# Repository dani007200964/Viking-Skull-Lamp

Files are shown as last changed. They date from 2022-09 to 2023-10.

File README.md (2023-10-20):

# Viking Skull Lamp 

## Introduction

I made this project for my brother. He loves Halloween and asked me to create a Viking-style lamp that has a glowing skull.
This is what comes out of this idea. I roughly had five months to test the device before publishing it. I can happily say
that in this period nothing went wrong with it. It just worked like a charm. Also, I have worked a lot on the documentation,
meanwhile. Here you can see what can this thing do.

Tutorial VIdeo (https://www.youtube.com/watch?v=T2uH4yskYew)

## Features:
* 30 addressable LED to make it shine :rotating_light:
* Microphone for :studio_microphone:
  * Music reactive lighting :musical_note:
  * @ref clap_pattern "Clap switch" :clap:
* Foldable controls
* Interactive menu with a graphical display :joystick:
* Saving and loading the configuration parameters :floppy_disk:
* Light modes:
  * Rainbow :rainbow:
  * Candle :candle:
  * Pulse :loud_sound:
  * Komodo 3000 :sunny:
  * Color :art:
* Humidifier for spooky smoke effect :ghost:
* Magic runes on the front. They are glow-in-the-dark :star:

## Documentation

The full documentation with detailed assembly instructions can be found [here](https://dani007200964.github.io/Viking-Skull-Lamp/html/index.html).

## Donation

If you like my work, and if it was useful for you, please consider buying me a coffee or tipping. :coffee: :coffee: :coffee:

<a href='https://ko-fi.com/danielhajnal' target='_blank'>Buy Me a Coffee at ko-fi.com

## Contributing

Pull requests are welcome. For major changes, please open an issue first to discuss what you would like to change.

## Used Resources:

* [FastLED](https://github.com/FastLED/FastLED)
* [PlatformIO](https://platformio.org/)
* [Visual Studio Code](https://code.visualstudio.com/)
* [Atom](https://atom.io/)
* [Doxygen](https://doxygen.nl/manual/tables.html)
* [Doxygen Awesome Theme](https://github.com/jothepro/doxygen-awesome-css)
* [Graphviz](https://graphviz.org/)
* [FreeCAD](https://www.freecadweb.org/)
* [Blender](https://www.blender.org/)
* [Prusa Slicer](https://github.com/prusa3d/PrusaSlicer/releases)
* [Gimp](https://www.gimp.org/)
* [KiCad](https://www.kicad.org/)
* [Interactive HTML BOM](https://github.com/openscopeproject/InteractiveHtmlBom)
* [Inkscape](https://inkscape.org/)
* [OpenShot](https://www.openshot.org/)
* [model-viewer](https://modelviewer.dev/)

## License & Copyright

© Daniel Hajnal

:email: hajnal.daniel96@gmail.com

Software is licensed under the __MIT__ License, and the hardware and the mechanical parts are licensed under the __Creative Commons__ [BY-NC-SA](https://creativecommons.org/licenses/by-nc-sa/4.0/) license.

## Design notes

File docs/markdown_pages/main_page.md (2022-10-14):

@mainpage Viking Skull Lamp

__Introduction__

I made this project for my brother. He loves Halloween and asked me to create a Viking-style lamp that has a glowing skull.
This is what comes out of this idea. I roughly had five months to test the device before publishing it. I can happily say
that in this period nothing went wrong with it. It just worked like a charm. Also, I have worked a lot on the documentation,
meanwhile. Here you can see what can this thing do. Also, there are some nice photos of the lighting in the @ref gallery "gallery".

\htmlonly

<p align="center"><iframe width="1024" height="786" src="https://www.youtube.com/embed/T2uH4yskYew" title="YouTube video player" frameborder="0" allow="accelerometer; autoplay; clipboard-write; encrypted-media; gyroscope; picture-in-picture" allowfullscreen></iframe></iframe></p>

\endhtmlonly

__Features:__
* 30 addressable LED to make it shine \emoji :rotating_light:
* Microphone for \emoji :studio_microphone:
  * Music reactive lighting \emoji :musical_note:
  * @ref clap_pattern "Clap switch" \emoji :clap:
* Foldable controls
* Interactive menu with a graphical display \emoji :joystick:
* Saving and loading the configuration parameters \emoji :floppy_disk:
* Light modes:
  * Rainbow \emoji :rainbow:
  * Candle \emoji :candle:
  * Pulse \emoji :loud_sound:
  * Komodo 3000 \emoji :sunny:
  * Color \emoji :art:
* Humidifier for spooky smoke effect \emoji :ghost:
* Magic runes on the front. They are glow-in-the-dark \emoji :star:

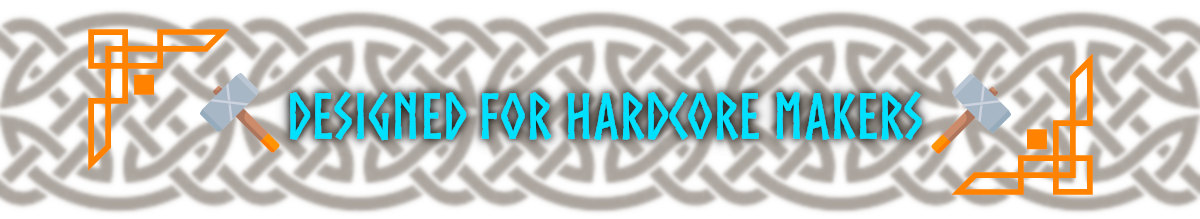
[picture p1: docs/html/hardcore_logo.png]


I want to clarify at the beginning that this is not a beginner-level project. It's more like a hardcore one.
If you love to create stuff and you are brave enough to start this journey, this documentation will guide you
through the whole assembly procedure. Before you start buying the components, please check the
@ref required_tools "required tools" page. It contains everything you need to create this device. If you don't
have a tool, it will be clear at the beginning.

I tried to not make mistakes in the device or its documentation, but I'm just a regular person, sometimes
I make mistakes like everyone else do. If you find a problem or something does not understandable, please visit
the @ref issue_guide "issue guide" section. There is an example of how to submit an issue. If you report an issue
I will try my best to fix it.

This journey consists of five stages. You have to start from the first and progress upwards.

1. \ref components "Sourcing Components:" Firstly you have to source the required parts and materials.

2. \ref print_guide "3D Printing Parts:" Next, you have to print all the necessary parts. There are some tricky ones
so read the \ref print_guide "print guide" section carefully.

3. \ref pcb_assembly "PCB And Cable Assembly:" I have designed a custom PCB for this project. It expands the functionality of
the Arduino UNO platform. It controls all the peripherals in the system. The custom PCB was necessary to make the project
fit this size.

4. \ref software_guide "Software Guide:" Of course, this project has a custom firmware. It is written in C++ and I
have used PlatformIO as a development tool.

5. \ref assembly_instructions "Mechanical Assembly:" Finally it's time to assemble the whole thing.

__Donation__

If you like my work, and if it was useful for you, please consider buying me a coffee or tipping. \emoji :coffee: \emoji :coffee: \emoji :coffee:



__Contributing__

Pull requests are welcome. For major changes, please open an issue first to discuss what you would like to change.

__Used Resources:__

* [FastLED](https://github.com/FastLED/FastLED)
* [PlatformIO](https://platformio.org/)
* [Visual Studio Code](https://code.visualstudio.com/)
* [Atom](https://atom.io/)
* [Doxygen](https://doxygen.nl/manual/tables.html)
* [Doxygen Awesome Theme](https://github.com/jothepro/doxygen-awesome-css)
* [Graphviz](https://graphviz.org/)
* [FreeCAD](https://www.freecadweb.org/)
* [Blender](https://www.blender.org/)
* [Prusa Slicer](https://github.com/prusa3d/PrusaSlicer/releases)
* [Gimp](https://www.gimp.org/)
* [KiCad](https://www.kicad.org/)
* [Interactive HTML BOM](https://github.com/openscopeproject/InteractiveHtmlBom)
* [Inkscape](https://inkscape.org/)
* [OpenShot](https://www.openshot.org/)
* [model-viewer](https://modelviewer.dev/)

__License & Copyright__

© Daniel Hajnal

\emoji :email: hajnal.daniel96@gmail.com

Software is licensed under the __MIT__ License, and the hardware and the mechanical parts are licensed under the __Creative Commons__ [BY-NC-SA](https://creativecommons.org/licenses/by-nc-sa/4.0/) license.

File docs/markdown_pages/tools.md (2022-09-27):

@page required_tools Required Tools

@section essential_tools Essential Tools

These tools are required to create this project. Without them, it is almost impossible
to finish every section. Also if you are a maker these tools can be used later for
future projects.

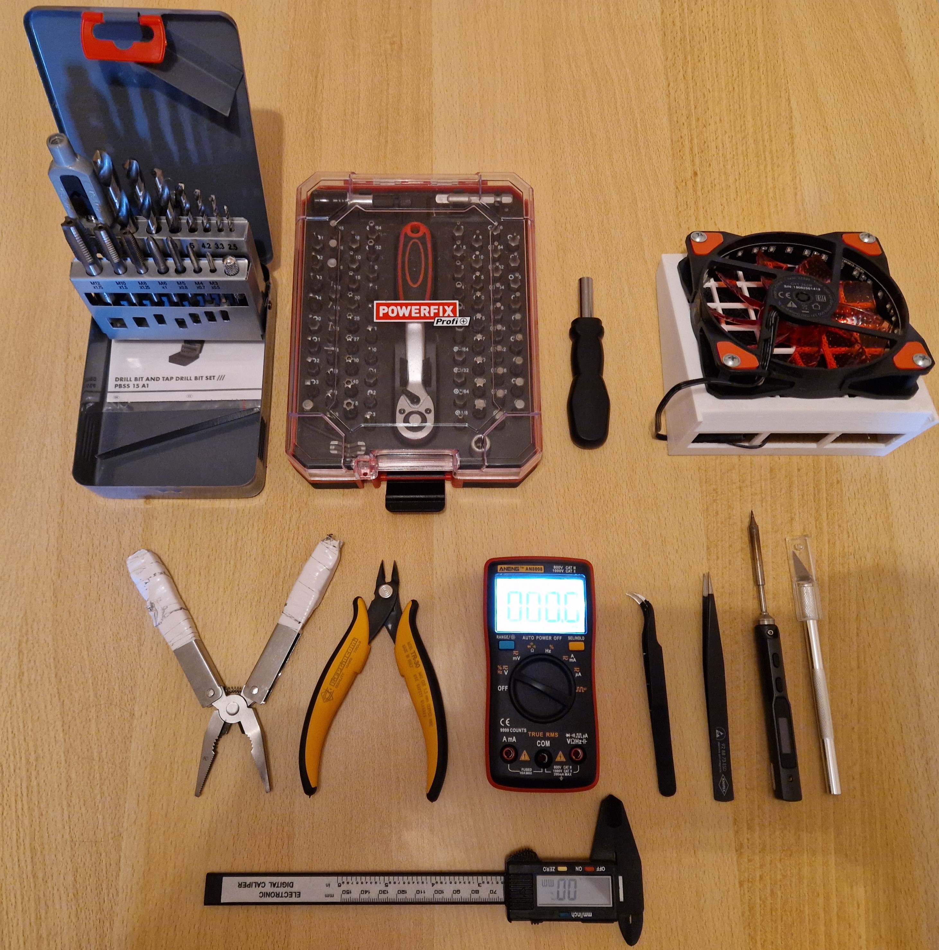
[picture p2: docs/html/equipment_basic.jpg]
Essential Tools


* Screwdriver with a lot of bitheads
* Superglue
* Side cutter
* Multimeter
* Tweezers
* Soldering iron
* Fume extractor
* Exacto knife
* Tapping set
* Caliper
* Pliers
* Connector crimping pliers( [PA-09](https://www.engineertools-jp.com/pa092021) for example )
* 3D printer with 180mm * 180mm * 150mm volume at least. I have a Prusa Mini, but
I think any popular 3D printer can make these parts. For the nozzle, I used a 0.4mm one and it
was enough for all parts.

@note If you do some soldering work PLEASE USE A FUME EXTRACTOR. That smoke is very
dangerous, it can kill you. Please solder in a well-ventilated area with some kind
of fume extractor. You can build one with some carbon filter and a PC fan.

@section tools_for_warriors Tools For Warriors

In this section, I show some tools, that I used in this project. These are not necessary
to finish the project, but they can accelerate the process and the result will be
more professional.

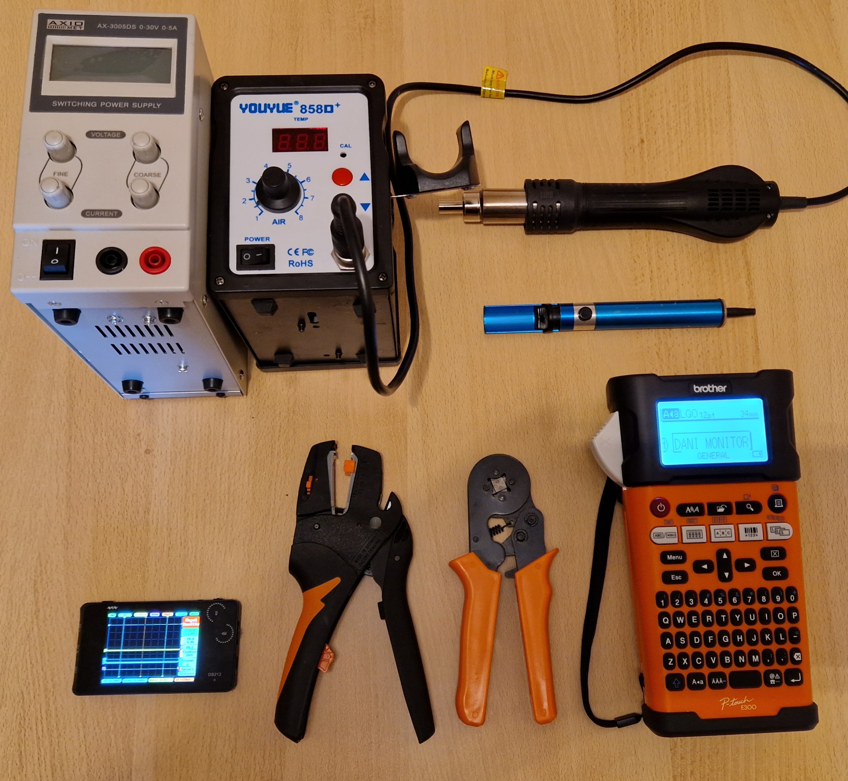
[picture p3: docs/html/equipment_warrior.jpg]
Warrior's Tools


* Bench supply - If you want to power up prototype electronics it can be a lifesaver.
You can limit the current to a safe level, this way if something's wrong with the
circuit, it won't blow to your face at the smoke test.
* Hot air station - If you do some SMD rework it is a game changer. Also, it can be
used for heat-shrinking tubes.
* Label maker - One of my favorite gadgets. If you want to organize something it is
the right tool. I use it whenever I have more cable than one.
* Stripping tool - This thing is awesome when you have to deal with cables. It is
not cheap, but you can strip cable ends like a God with it. Also, your hand won't
hurt after a day.
* End sleeve crimper - If you have to deal with terminal blocks, this thing is very useful.
You can press the end sleeves with regular pliers, but it's hard to fit in the terminal block
that way. There are cheap solutions, I highly recommend getting one.
* Solder sucker - It can be useful with THT components.
* Oscilloscope - There are a huge variety of scopes today. There are cheap ones like
the [DS212](https://www.miniware.com.cn/product/ds212-mini-oscilloscope-digital-oscilloscope/).
It is cheap and does the job for basic circuits. Sadly the interface is hard to use.

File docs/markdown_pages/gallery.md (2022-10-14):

@page gallery Gallery

\htmlonly

<div class="row">   
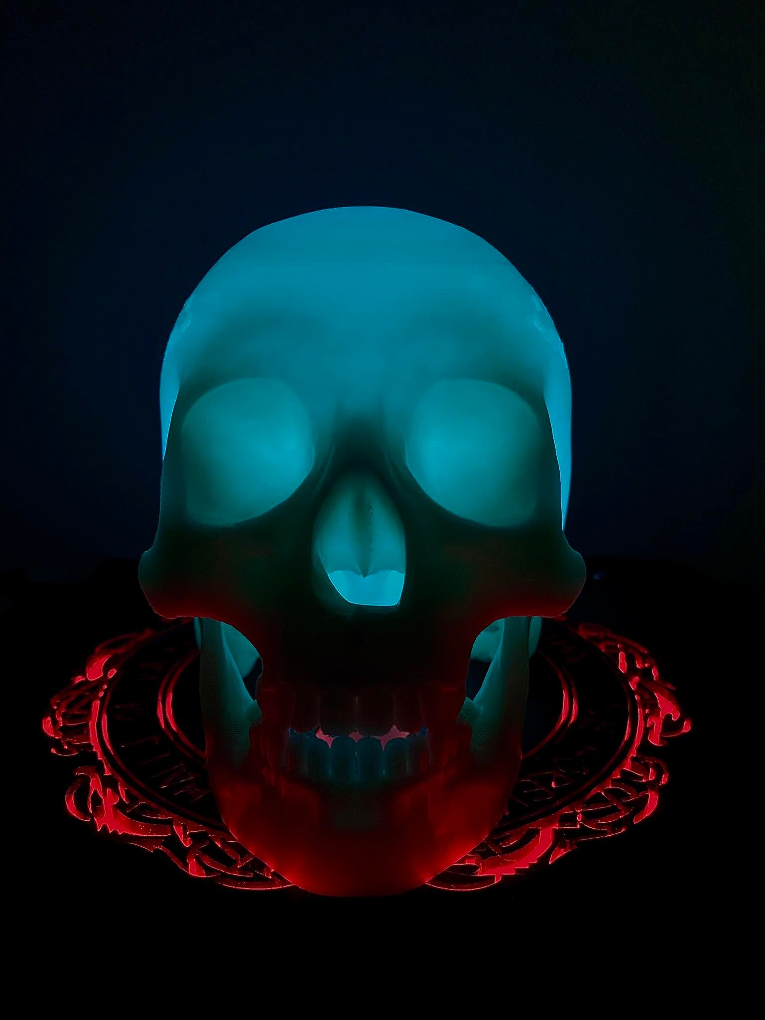
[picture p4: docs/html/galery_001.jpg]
Concrete factory
     
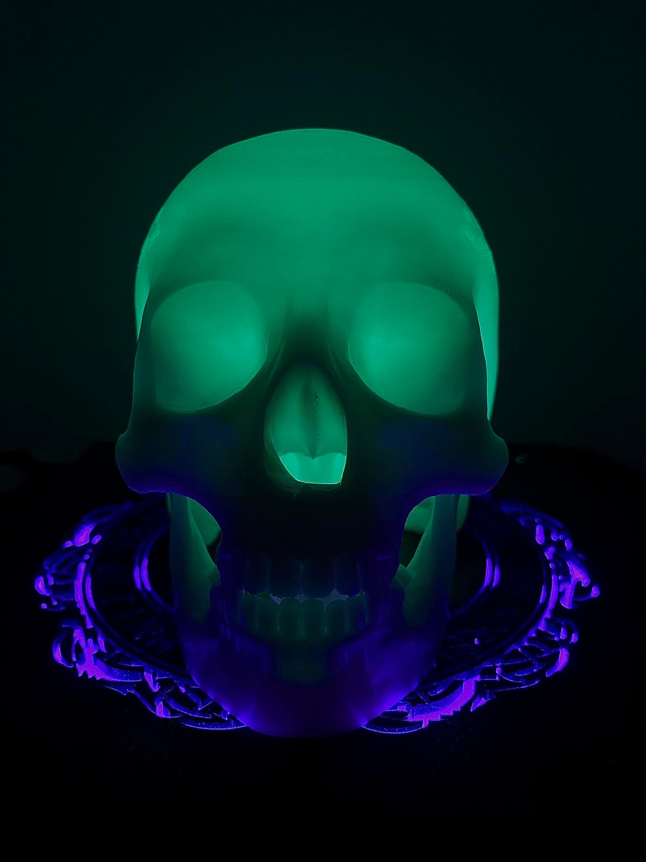
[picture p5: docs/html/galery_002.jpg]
     
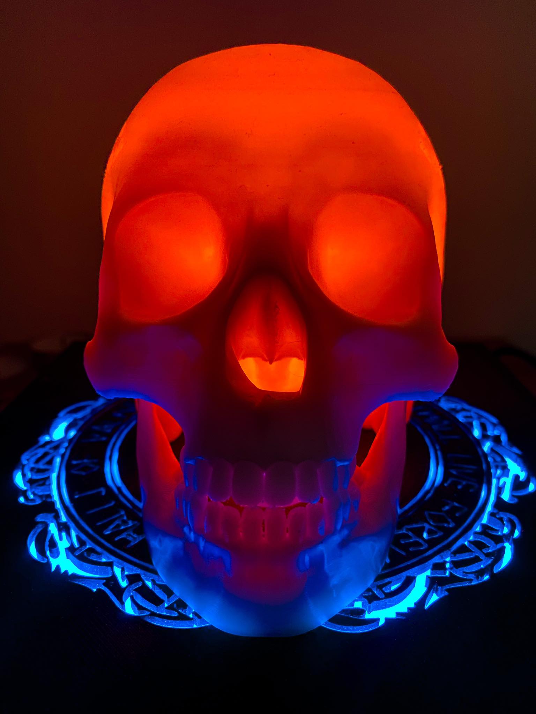
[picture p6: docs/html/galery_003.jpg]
     
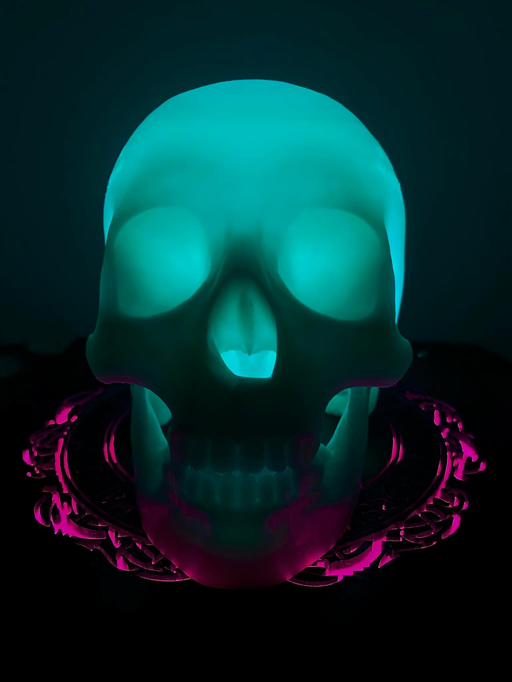
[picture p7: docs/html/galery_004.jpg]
     
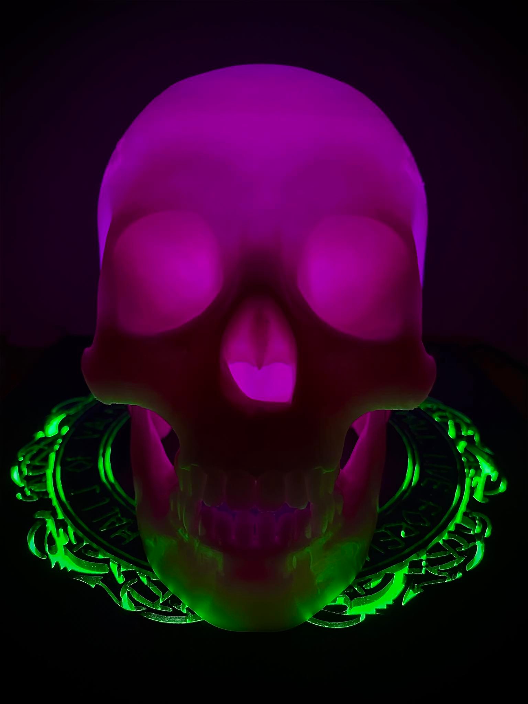
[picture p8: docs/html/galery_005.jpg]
     
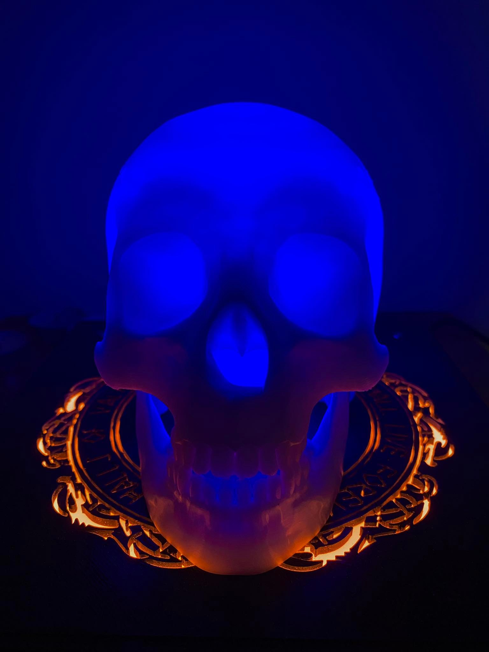
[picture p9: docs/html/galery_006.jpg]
     
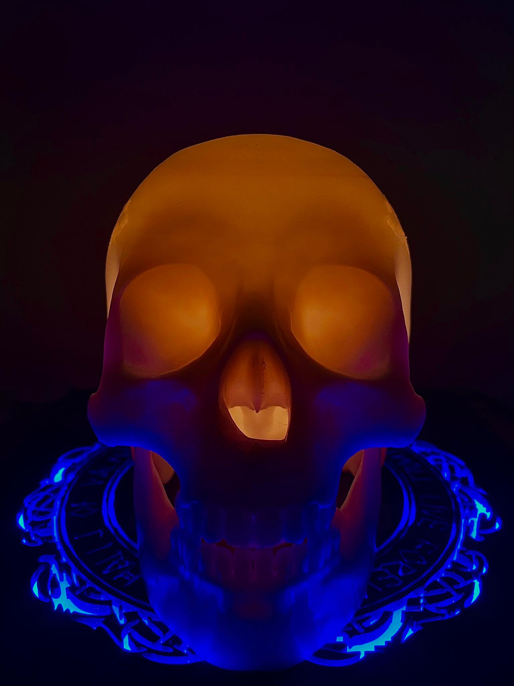
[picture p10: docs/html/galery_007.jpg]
     
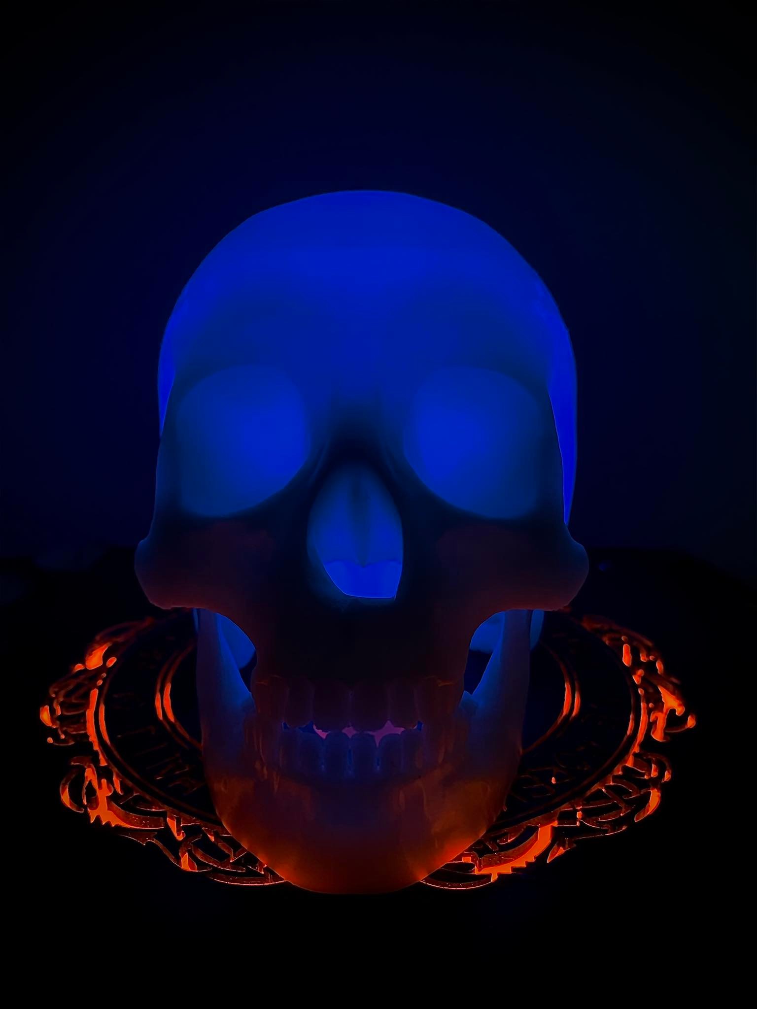
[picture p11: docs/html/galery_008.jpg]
     
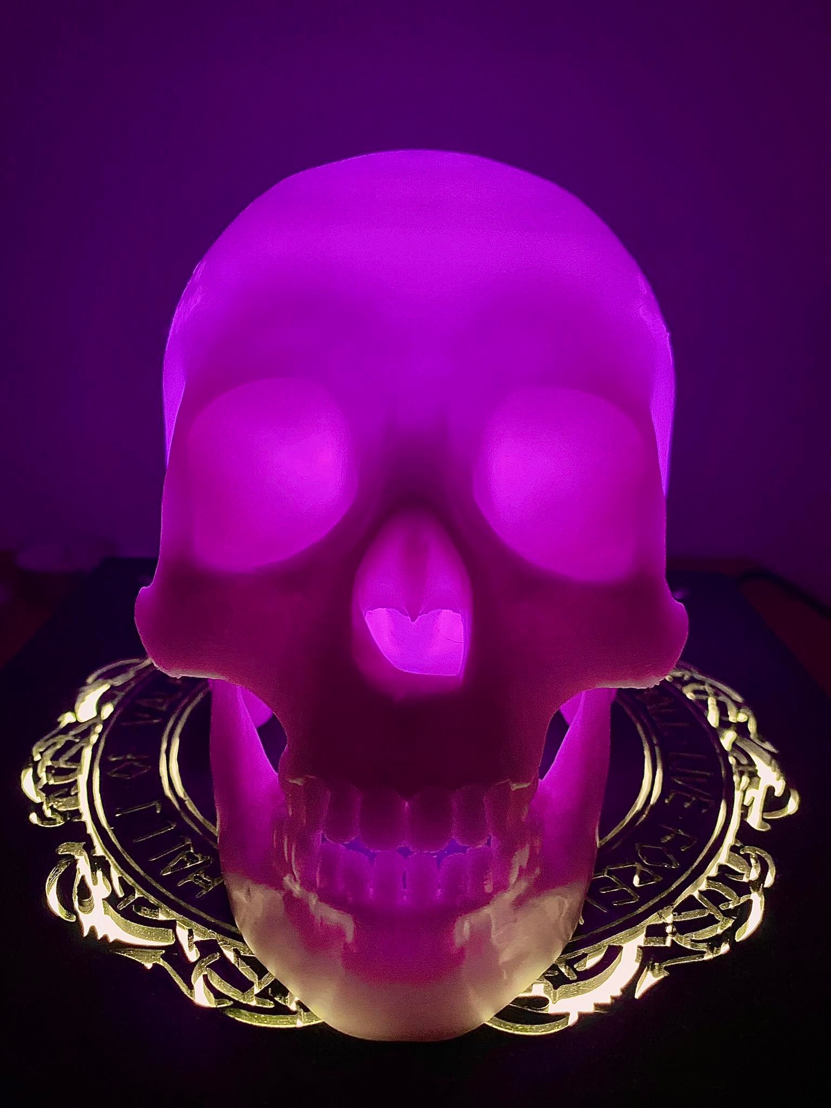
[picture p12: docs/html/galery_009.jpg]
     
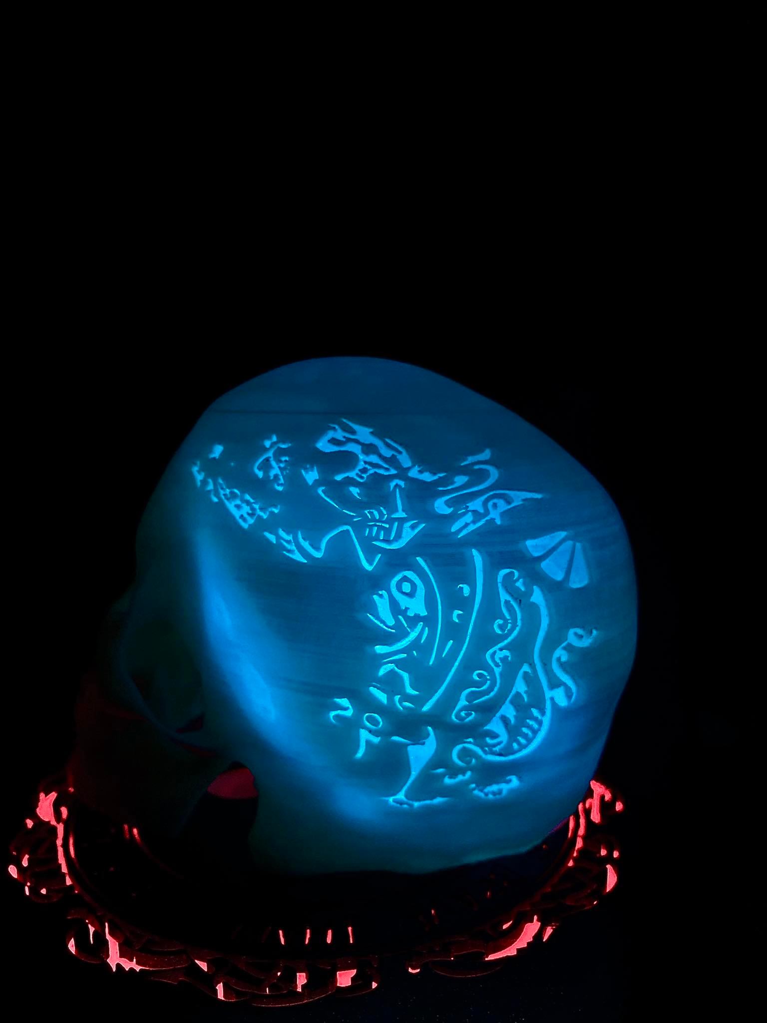
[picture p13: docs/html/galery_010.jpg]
     
     Abstract factory
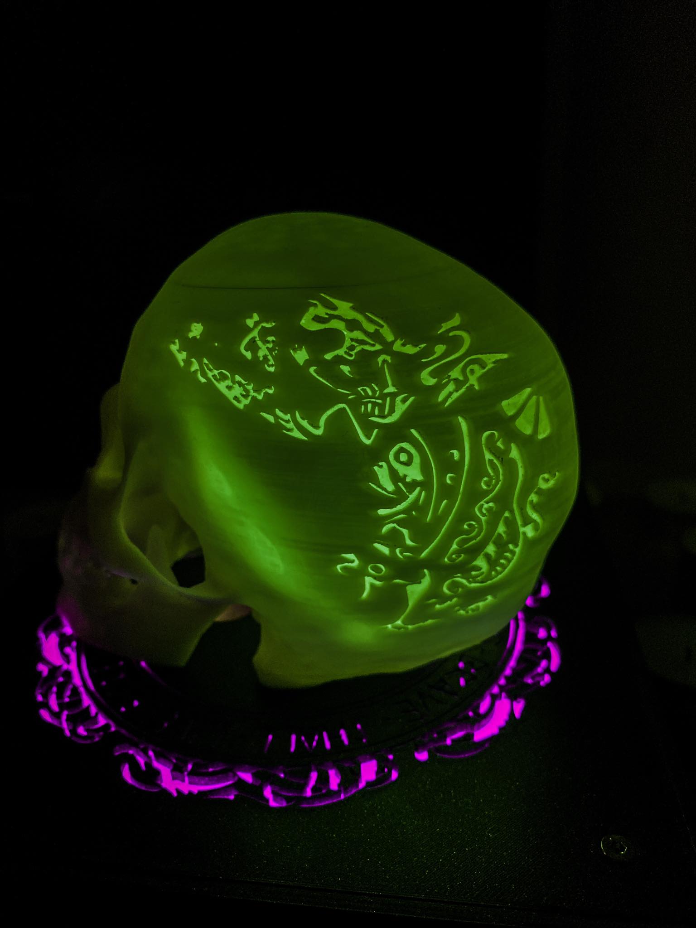
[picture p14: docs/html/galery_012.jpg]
     
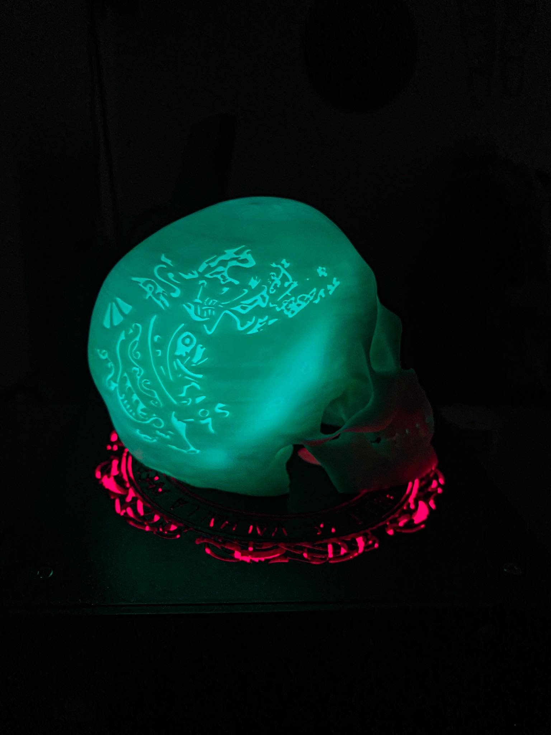
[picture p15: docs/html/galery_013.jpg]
     
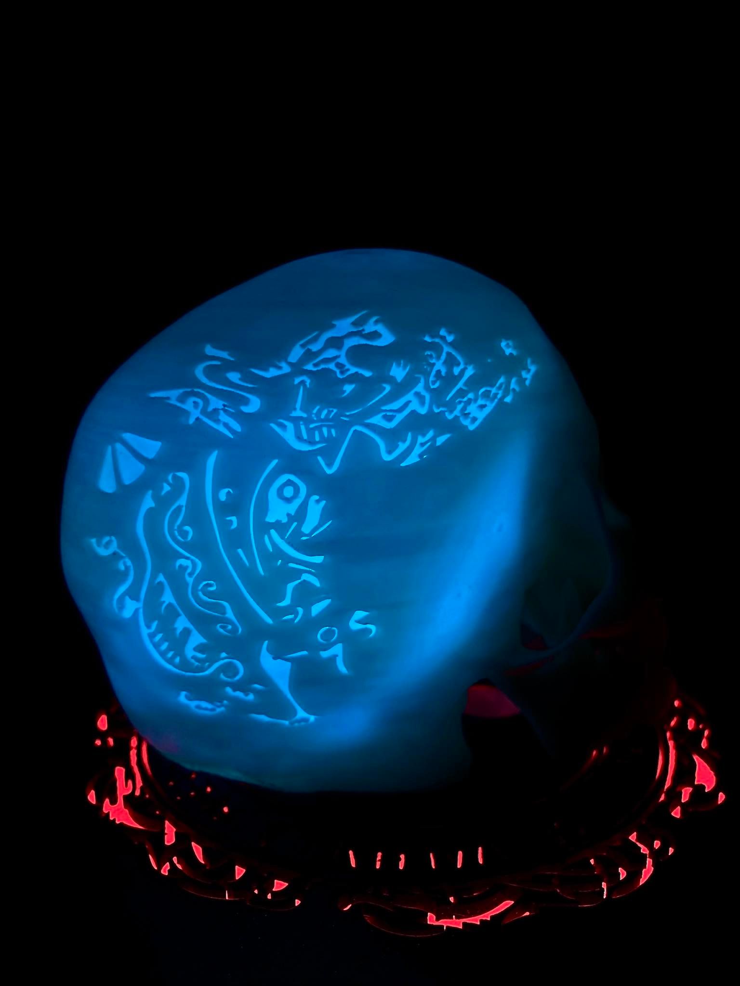
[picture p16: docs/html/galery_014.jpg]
     
</div>

\endhtmlonly

@section clap_pattern Clap Pattern

\htmlonly

<video controls>
  <source src="clap_pattern.mp4">
</video>

\endhtmlonly

@note This clap pattern is supported by the software. It sometimes works \emoji :grimacing:

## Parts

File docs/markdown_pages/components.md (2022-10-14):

@page components Components

\htmlonly

<iframe src="https://docs.google.com/spreadsheets/d/e/2PACX-1vSf02YC8l392_BotfjYF4mUZivv1Xb5yQWE1lsLWvxXTTtfUl-AnEIT_xKbkZg5Pfvl0sSlF0SmhizU/pubhtml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" style="width:100%;height:80vh;"></iframe>

\endhtmlonly

This table shows all the required components to build this project. I tried to use generic
parts to make the sourcing easier. I included the distributors which I used. I calculated
the nominal quantity for everything, but I also included the quantity, that I recommend
to source. It is always a good thing if you have some spare parts, you can use them later.
It is very frustrating when something has less in stock than needed. Also sometimes you
stumble upon a bad module( encoder, display... ) that doesn't work. Personally, I had only
one incident with a cheap display module in the years, but you get the idea.

__Techno Viking PCB Parts__

This is a special topic. Because the PCB has a relatively high amount of components, I think
it's better to handle that separately. Luckily the PCB designer software that I used can create
an interactive HTML-based component list, I included that in the
@ref how_to_get_the_right_components "How To Get PCB Components" section. It can be used for
PCB assembly as well.

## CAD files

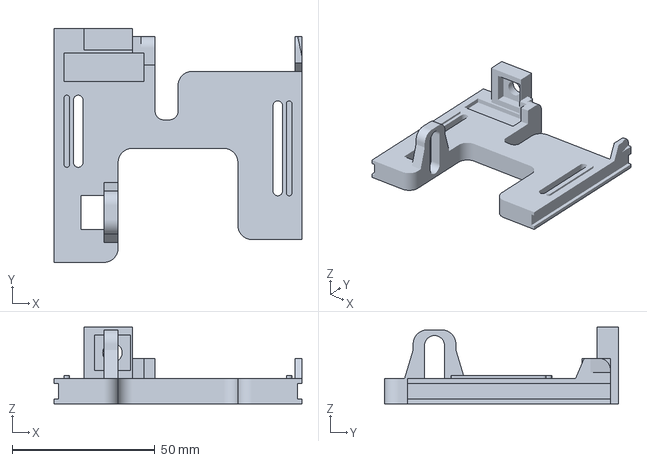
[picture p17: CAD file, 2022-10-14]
CAD/3mf/moving_platform_1pcs.3mf
87.0 x 82.0 x 27.0 mm

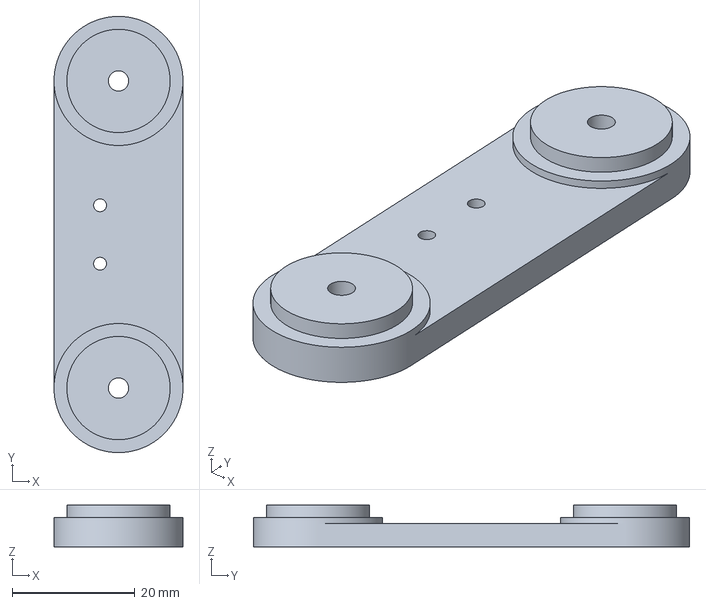
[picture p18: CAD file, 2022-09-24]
CAD/3mf/left_endstop_mount_1pcs.3mf
21.0 x 71.0 x 6.80 mm

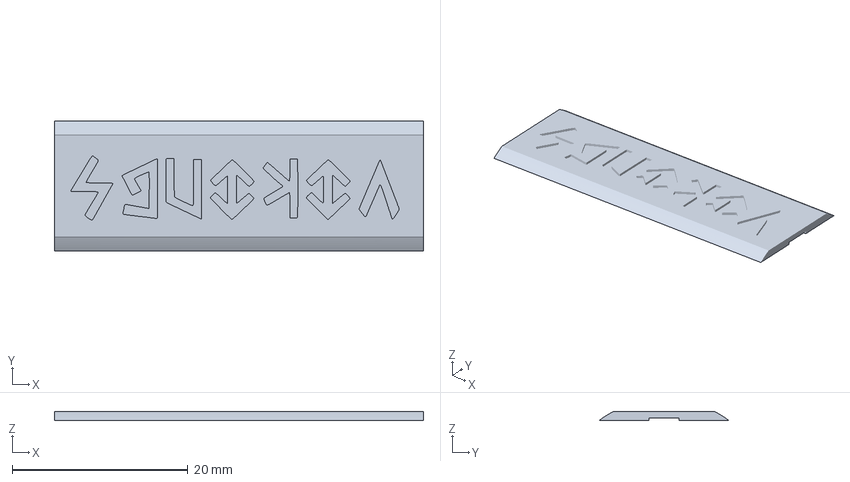
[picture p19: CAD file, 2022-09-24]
docs/html/display_holder_front_with_art_1pcs.3mf
42.0 x 14.8 x 1.00 mm

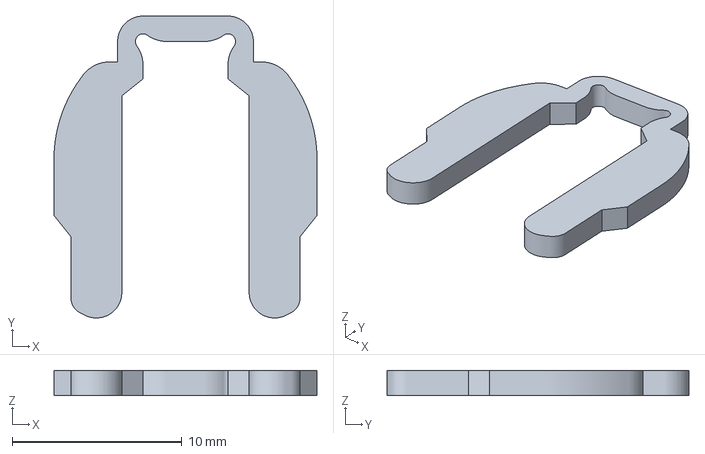
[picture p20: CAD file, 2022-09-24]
docs/html/display_clamp_2pcs.3mf
15.5 x 17.8 x 1.50 mm

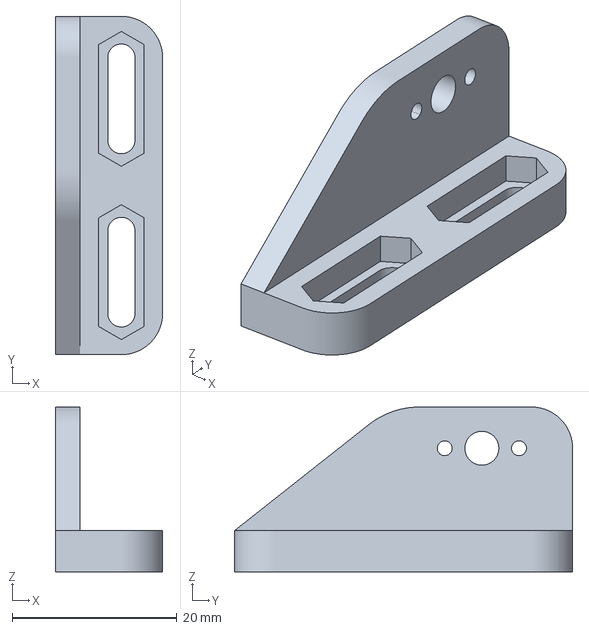
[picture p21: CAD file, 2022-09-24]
CAD/3mf/motor_mount_1pcs.3mf
13.0 x 41.0 x 20.0 mm

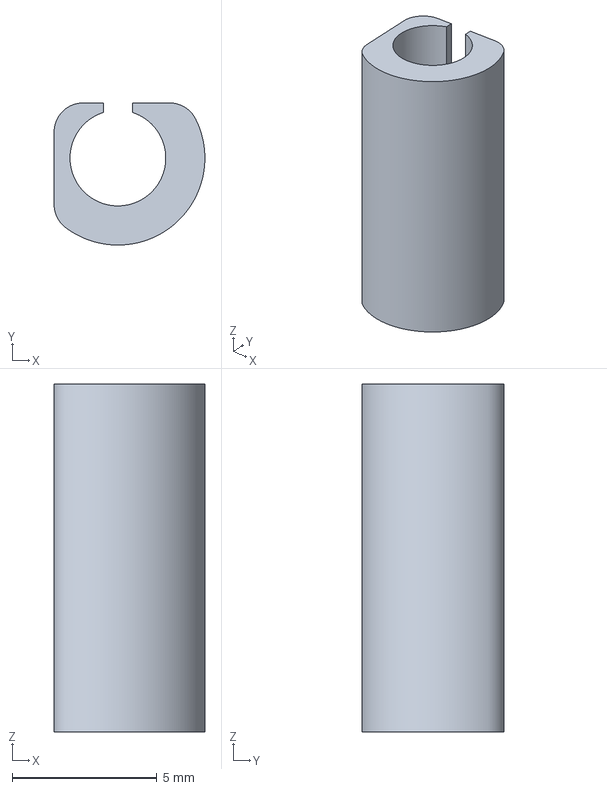
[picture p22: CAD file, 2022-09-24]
docs/html/pcb_spacer_corner_1pcs.3mf
5.20 x 4.90 x 12.0 mm

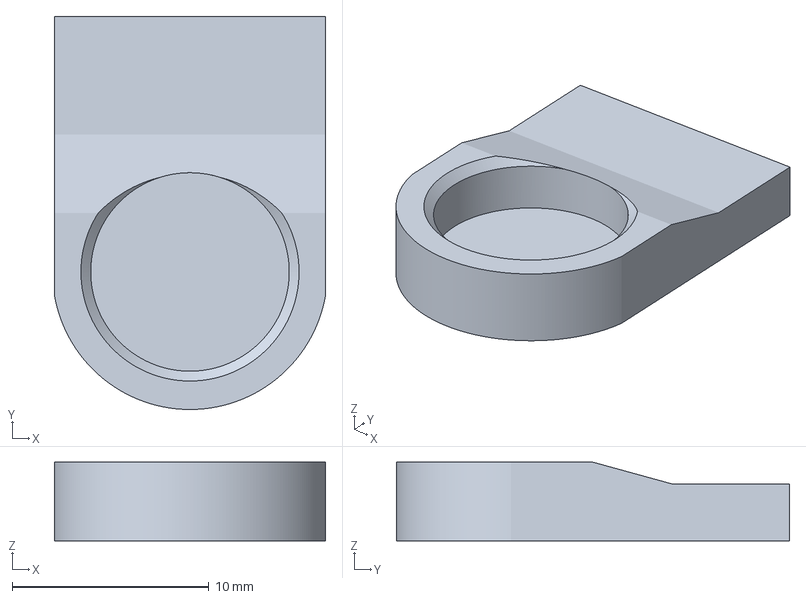
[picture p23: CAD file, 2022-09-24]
CAD/3mf/front_panel_magnet_holder_1pcs.3mf
13.8 x 20.0 x 4.00 mm

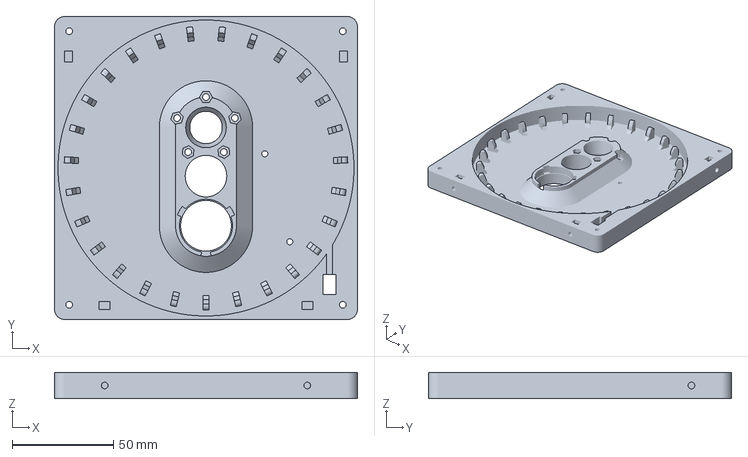
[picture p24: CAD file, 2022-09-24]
docs/html/led_holder_1pcs.3mf
149.5 x 149.5 x 13.0 mm

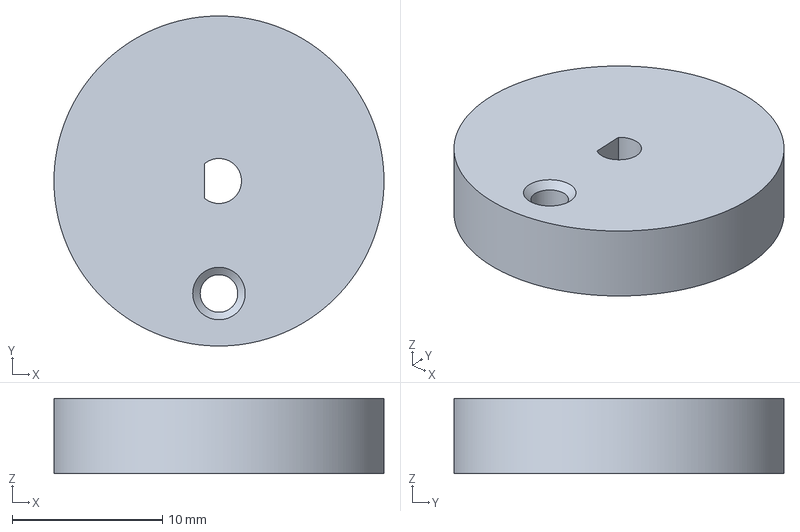
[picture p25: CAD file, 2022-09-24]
CAD/3mf/eccetric_shaft_1pcs.3mf
22.0 x 22.0 x 5.00 mm

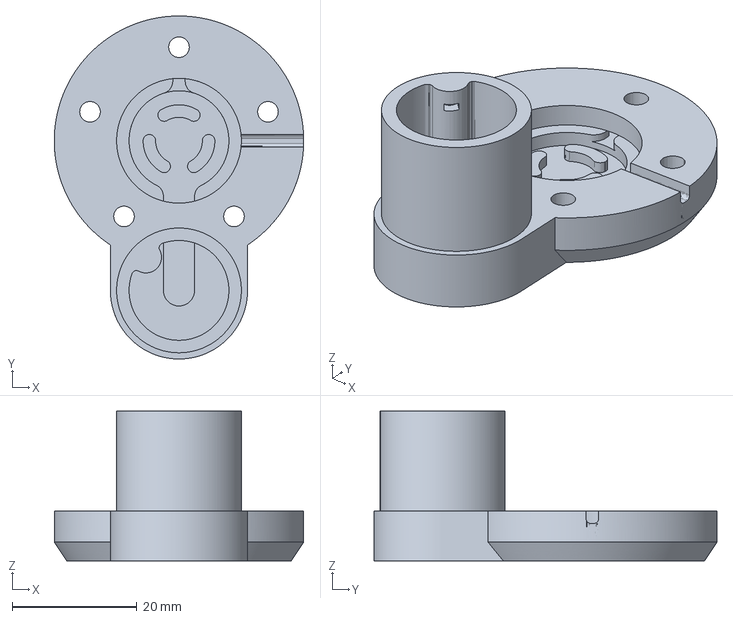
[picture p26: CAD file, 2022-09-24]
docs/html/azomizer_socket_1pcs_PETG.3mf
40.0 x 55.0 x 24.0 mm

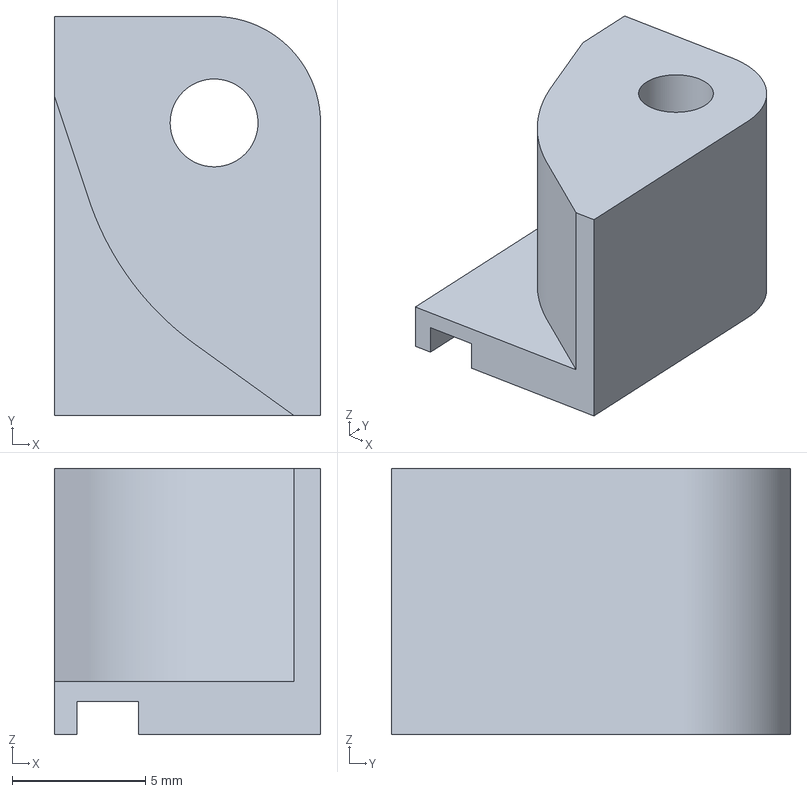
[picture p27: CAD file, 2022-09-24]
CAD/3mf/endstop_knob_2pcs.3mf
10.0 x 15.0 x 10.0 mm

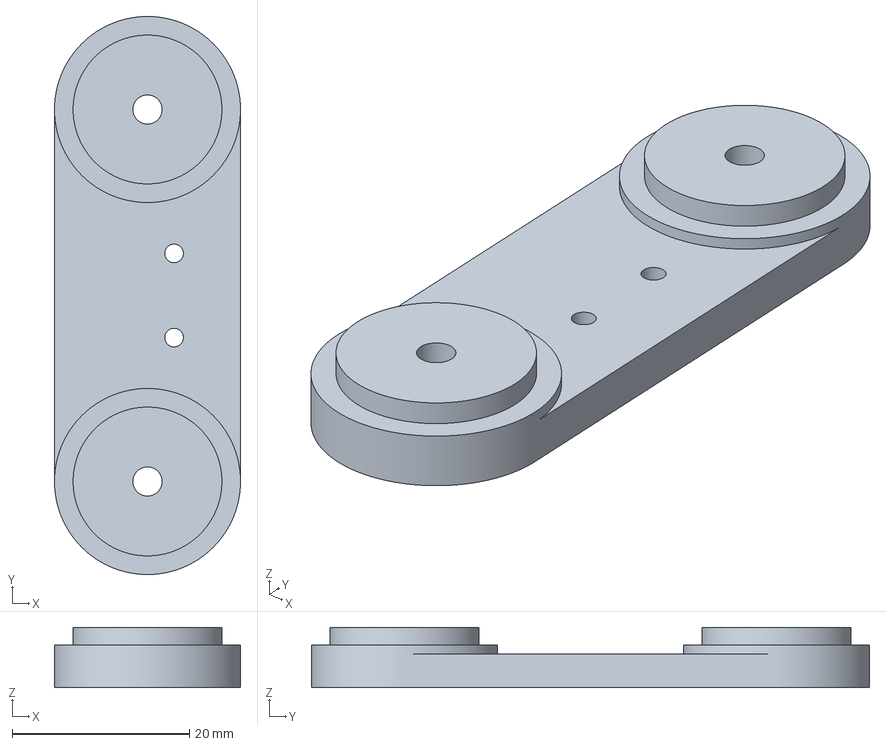
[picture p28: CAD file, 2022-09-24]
docs/html/right_endstop_mount_1pcs.3mf
21.0 x 63.0 x 6.80 mm

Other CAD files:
CAD/3mf/box_front_with_art_1pcs.3mf
CAD/3mf/display_holder_base_with_art_1pcs.3mf
CAD/3mf/encoder_knob_with_art_1pcs.3mf
CAD/3mf/led_ring_mount_1pcs.3mf
CAD/3mf/long_screw_spacer_1pcs.3mf
CAD/3mf/short_screw_spacer_1pcs.3mf
docs/html/box_front_naked_1pcs.stl
docs/html/box_front_with_art_1pcs.3mf
docs/html/display_clamp_2pcs.stl
docs/html/display_holder_base_with_art_1pcs.3mf
docs/html/display_holder_base_with_art_1pcs.stl
docs/html/display_holder_front_with_art_1pcs.stl
docs/html/display_holder_naked_1pcs.stl
docs/html/eccetric_shaft_1pcs.stl
docs/html/encoder_knob_naked_1pcs.stl
docs/html/encoder_knob_with_art_1pcs.3mf
docs/html/encoder_knob_with_art_1pcs.stl
docs/html/endstop_knob_2pcs.stl
docs/html/front_panel_magnet_holder_1pcs.stl
docs/html/led_ring_mount_1pcs.3mf
docs/html/led_ring_mount_1pcs.stl
docs/html/left_endstop_mount_1pcs.stl
docs/html/long_screw_spacer_1pcs.3mf
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

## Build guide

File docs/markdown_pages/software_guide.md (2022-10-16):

@page software_guide Software Guide



@section environment Environment

In this project, I used [Visual Studio Code](https://code.visualstudio.com/). It is an
open-source, multi-platform text editor, which has a lot of useful plugins. One of
those plugins is [PlatformIO](https://platformio.org/), which is a complete build system
for embedded devices. It is very easy to use and works very well.

__To make it work:__

__1.__ Download and install \emoji :package: [Visual Studio Code](https://code.visualstudio.com/)

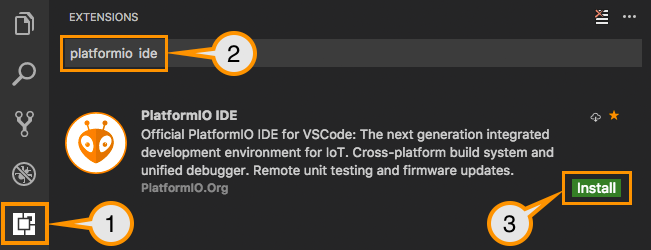
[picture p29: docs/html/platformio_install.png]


__2.__ Open VS Code and install the PlatformIO extension.

__3.__ Download the latest [release](https://github.com/dani007200964/Viking-Skull-Lamp/releases)
from the Viking Skull Lamp repository and unpack it somewhere on your machine.

__4.__ Open VS Code and follow the steps below.

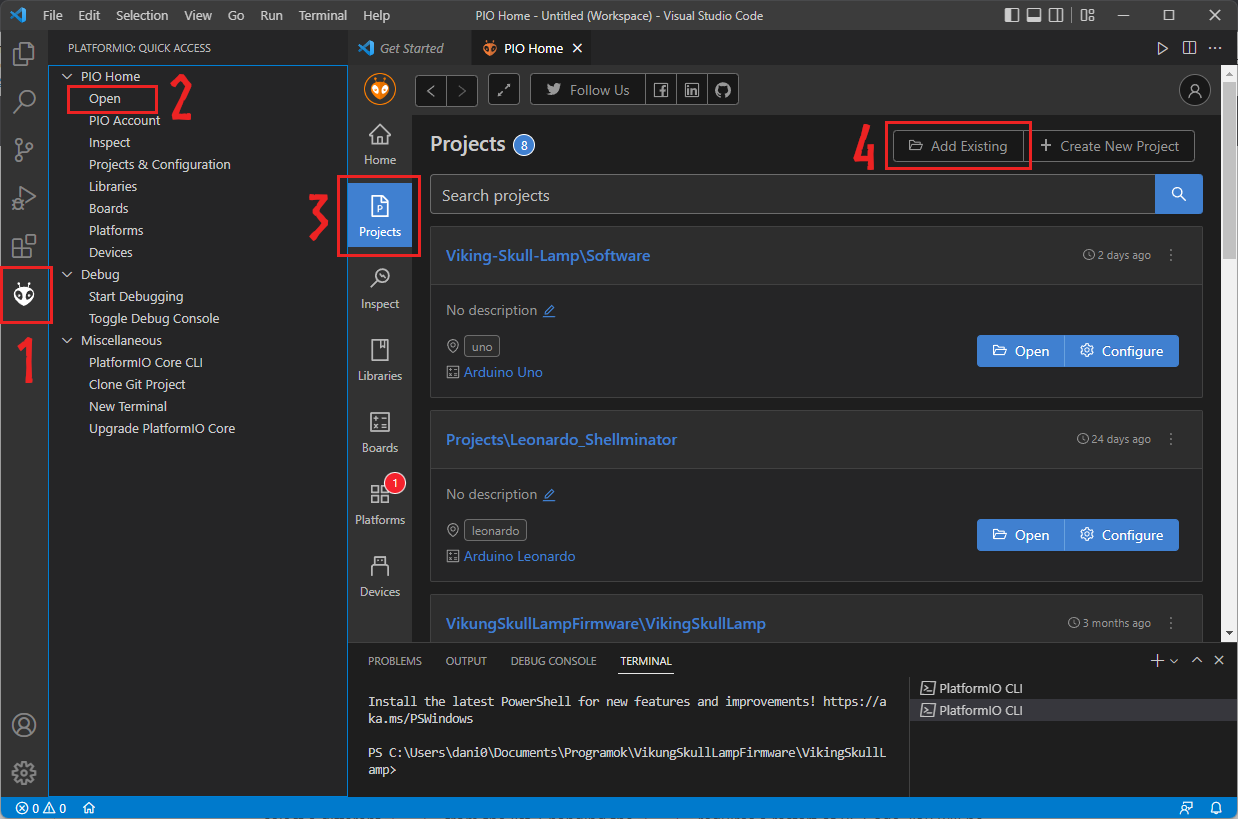
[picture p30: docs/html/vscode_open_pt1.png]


__5.__ Locate and open the __Software__ folder in the downloaded project folder.

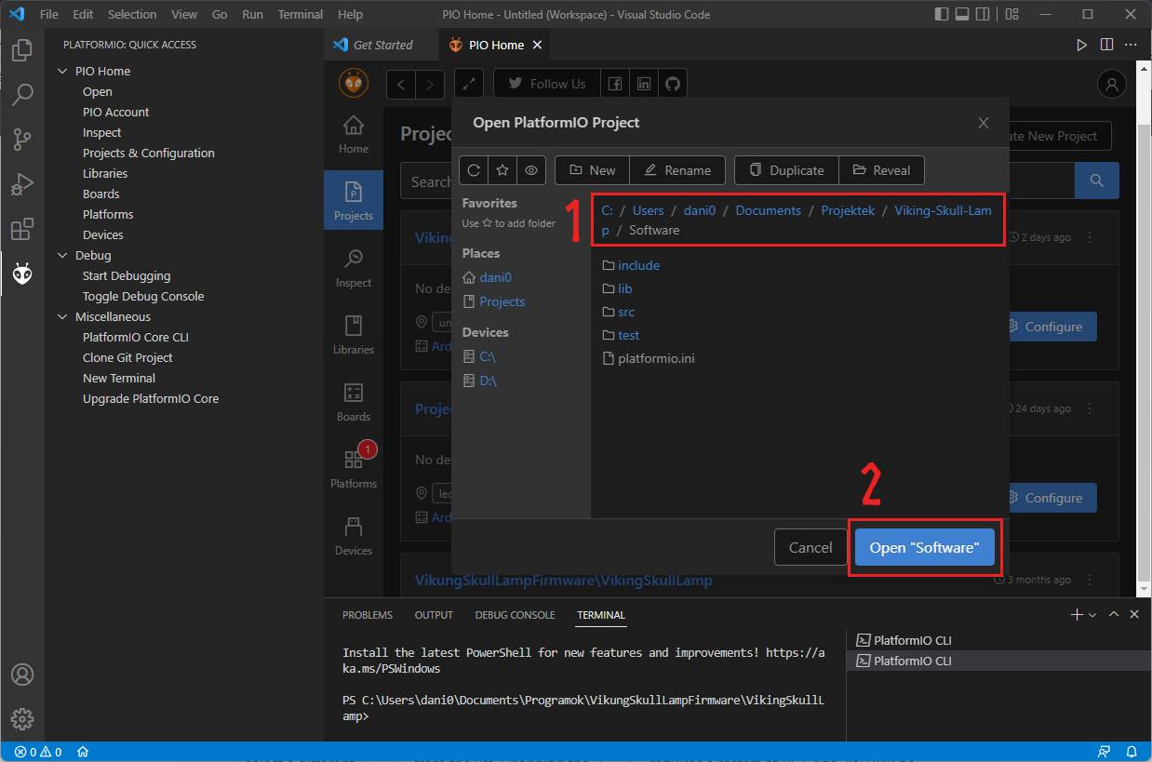
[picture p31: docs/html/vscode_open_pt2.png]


If everything went well, that's all, you can build and upload the firmware.

@section build_the_firmware Build The Firmware

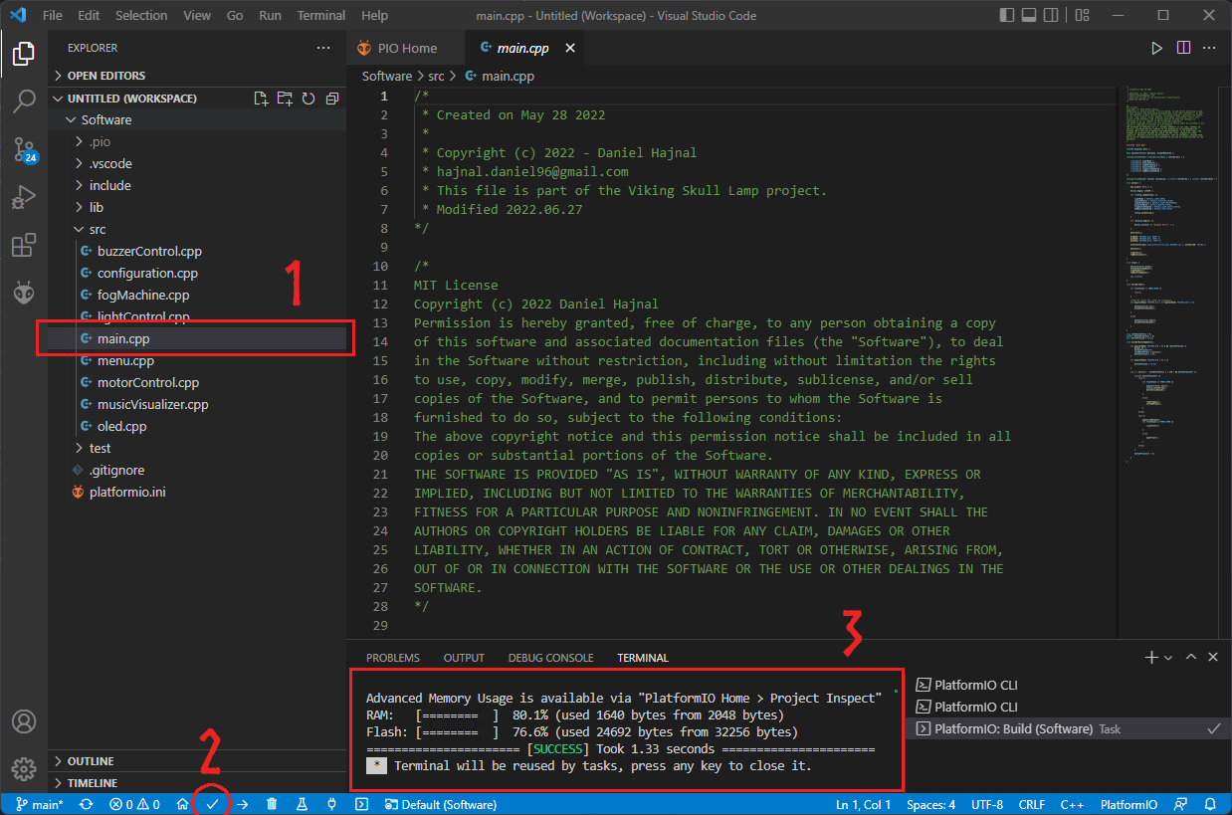
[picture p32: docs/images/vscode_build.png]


After the build finishes you should see a big green __[SUCCESS]__ on the console.

@section upload_the_firmware Upload The Firmware

@warning Do __NOT__ power the board from the USB and the power chord at the same
time! It can damage your board or your computer. If you upload the firmware use
the USB port only. If you use the device as intended of course you can use the
power chord.

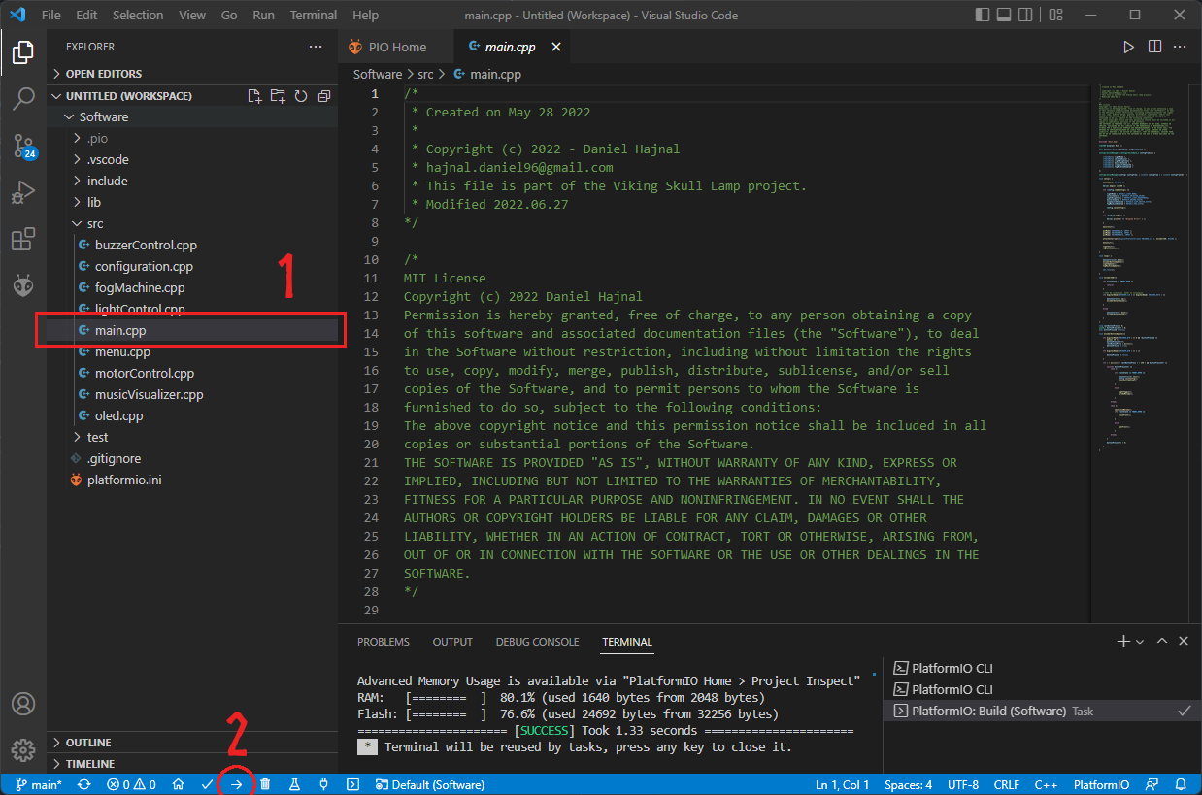
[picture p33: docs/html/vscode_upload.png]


@section modify_the_firmware Modify The Firmware

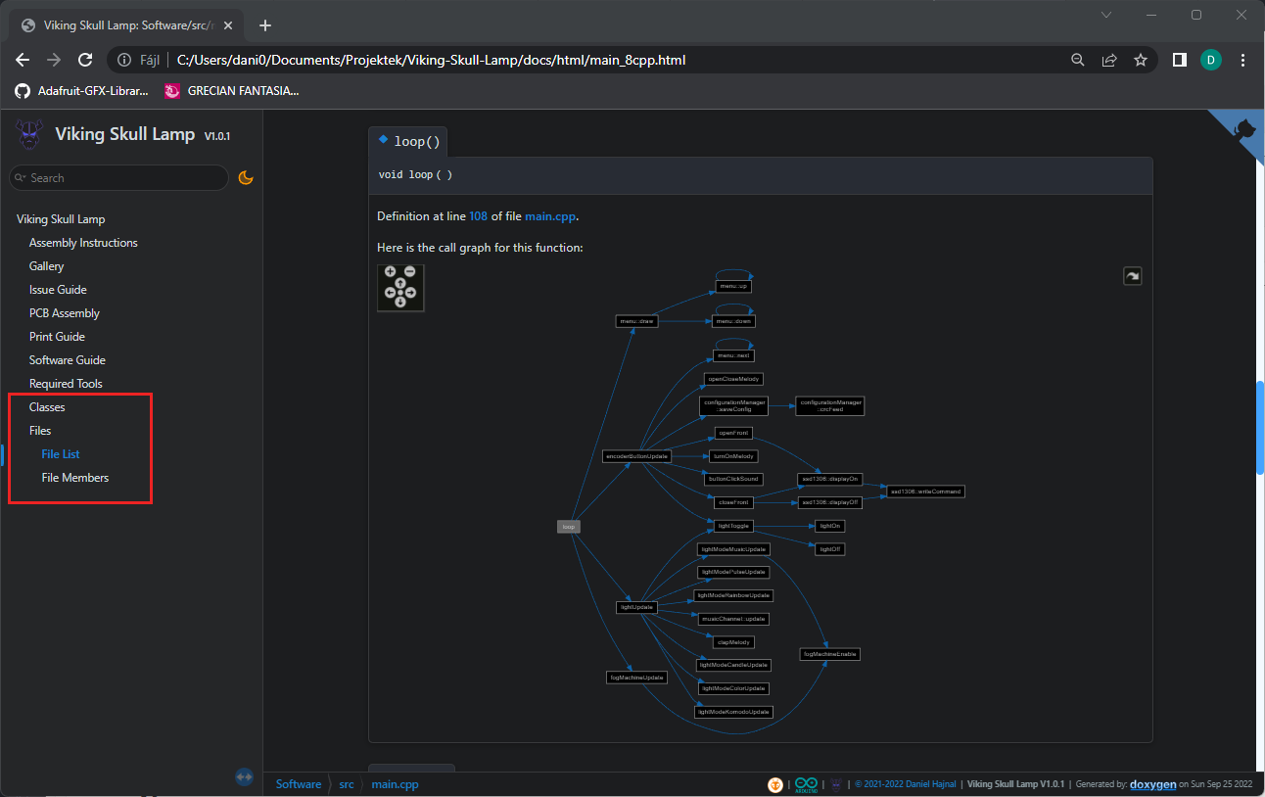
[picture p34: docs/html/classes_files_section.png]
Classes And Files


This is an open-source project, you can modify it as you like. The software
is no exception. I tried to comment it as much as possible to make it Doxygen compatible.
To understand the structure and the logic behind the source code, please check out
the __Classes__ and __Files__ section at the bottom left.

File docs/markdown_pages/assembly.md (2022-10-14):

@page assembly_instructions Assembly Instructions

\htmlonly

<script type="module" src="https://unpkg.com/@google/model-viewer/dist/model-viewer.min.js"></script>

<model-viewer src="assembly_animation.glb" ar ar-modes="webxr scene-viewer quick-look" camera-controls poster="poster.png" shadow-intensity="0" exposure="0.81" shadow-softness="1" environment-image="legacy" autoplay style="width:100%;height:80vh;">
    <div class="progress-bar hide" slot="progress-bar">
        
    </div>
</model-viewer>

\endhtmlonly

@section step_1_rubber_feet Step 1 - Rubber Feet

Rubber Feet

@pre Required parts:
* @ref box_bottom "Box Bottom" - 1pcs
* __Rubber Feet__              - 4pcs

The four rubber feet has to glued to the bottom of the box.
Rubber feet, that I used can be found
[here](https://www.hestore.hu/prod_10030980.html?lang=en).

@section step_2_endstop_mount_prepare Step 2 - Endstop Mount Prepare

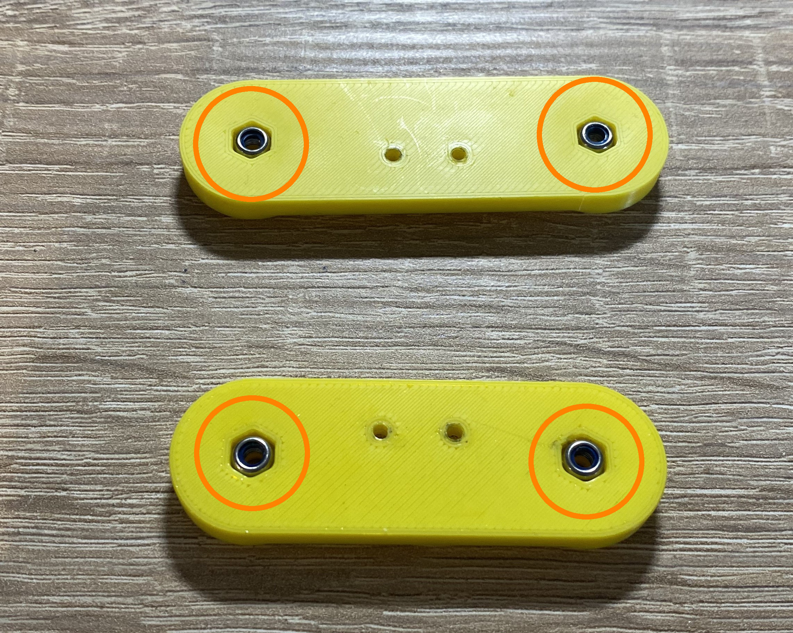
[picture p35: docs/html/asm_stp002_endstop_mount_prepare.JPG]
Endstop Mount Prepare


@pre Required parts:
* @ref right_endstop_mount "Right Endstop Mount" - 1pcs
* @ref left_endstop_mount "Left Endstop Mount"   - 1pcs
* __M3 Lock Nut__                                - 4pcs

Four M3 locknuts has to be pressed to the endstop mounts.

@section step_3_endstop_mount_screws Step 3 - Endstop Mount Screws

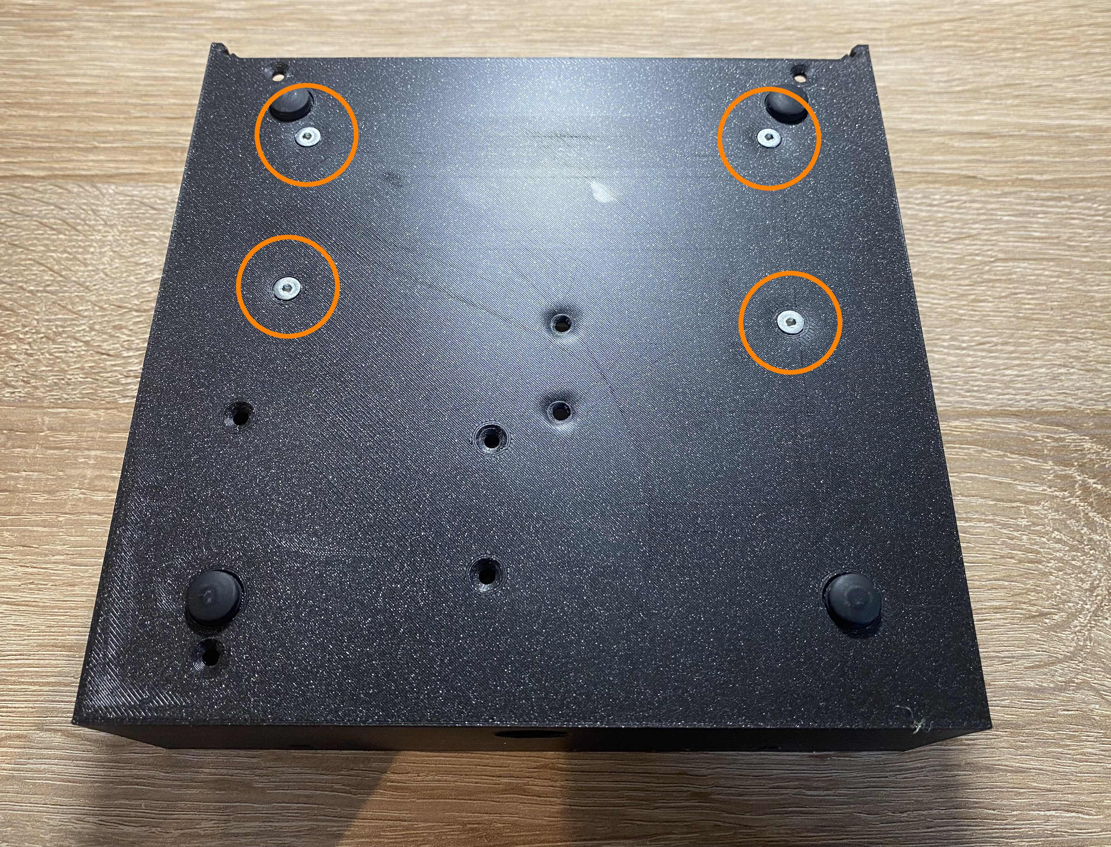
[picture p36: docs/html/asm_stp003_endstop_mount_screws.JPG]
Endstop Mount Screws


@pre Required parts:
* __M3 x 18mm FHCS__ - 4pcs

Four M3 x 18mm Flat Head Screw has to be inserted to the endstop mount holes.

@section step_4_insert_bearings Step 4 - Insert Bearings

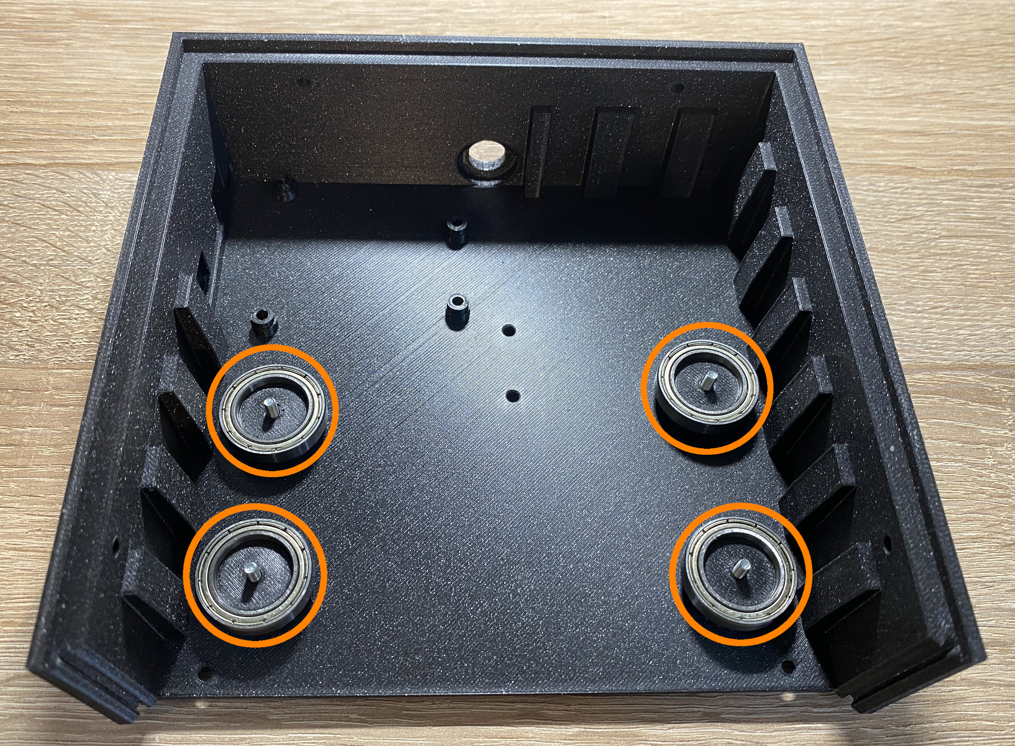
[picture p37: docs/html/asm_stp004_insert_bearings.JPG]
Insert Bearings


@pre Required parts:
* __61803 ZZ Bearings__ - 4pcs

Insert four 61803 ZZ Bearings.

@section step_5_locking_endstop_mounts Step 5 - Locking Endstop Mounts

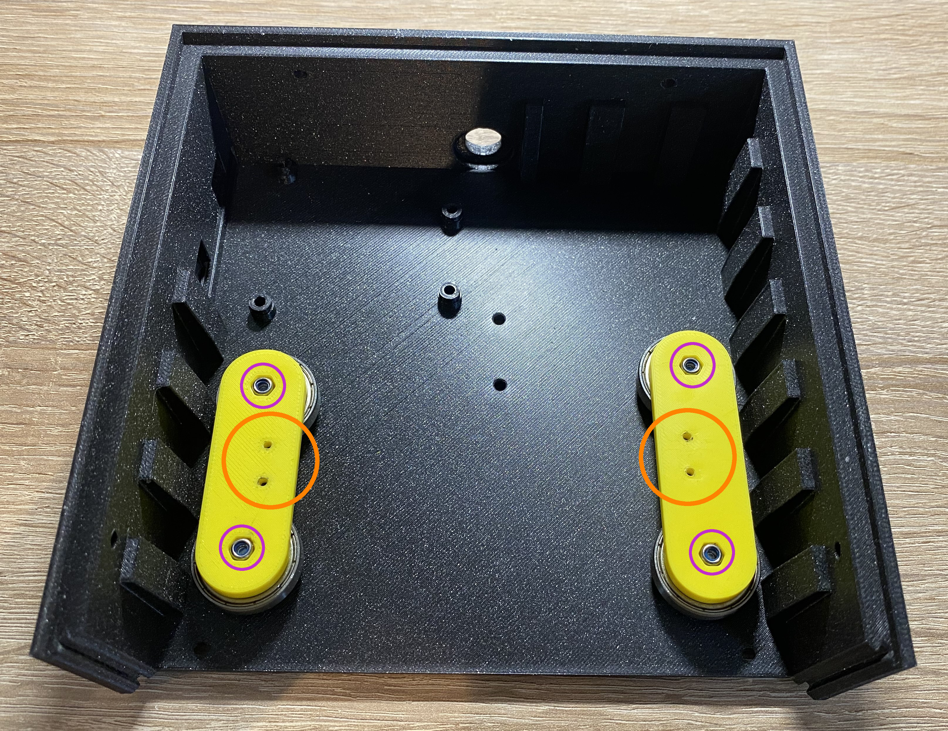
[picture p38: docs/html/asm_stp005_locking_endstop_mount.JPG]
Locking Endstop Mount


\emoji :orange_circle: Make shore, that the holes for the endstop switches are
looking __inwards__.

\emoji :purple_circle: Tighten the four screws, but __not so hard__, the bearings has
to move a bit sideways.

@section step_6_moving_platform_knobs Step 6 - Moving Platform Knobs

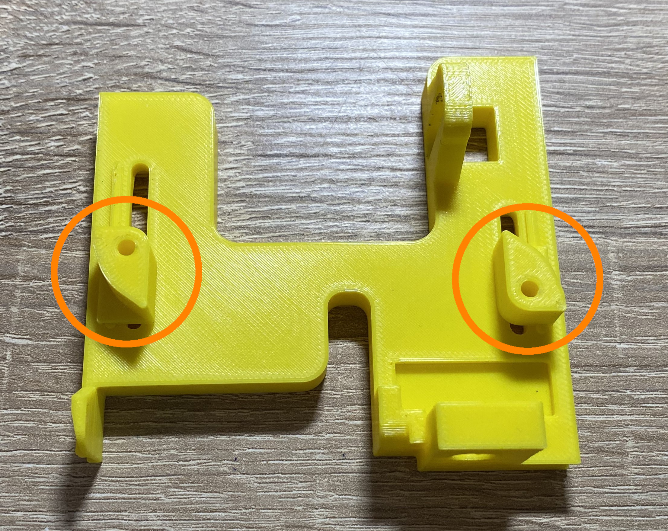
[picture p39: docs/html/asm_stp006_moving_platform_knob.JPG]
Moving Platform Knobs


@pre Required parts:
* @ref endstop_knob "Enstop Knob"        - 2pcs
* @ref moving_platform "Moving Platform" - 1pcs
* __M3 x 16mm SHCS__                     - 2pcs
* __M3 Hexnut__                          - 2pcs

Insert the two knobs to the rails on the moving platform.

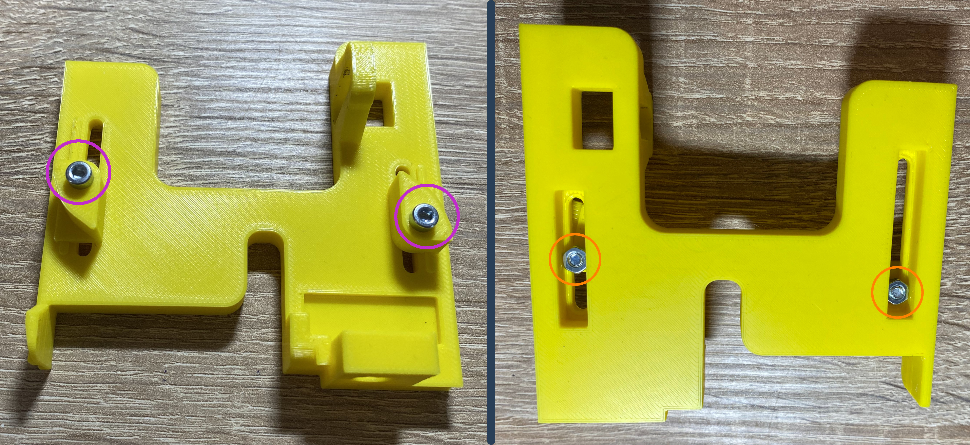
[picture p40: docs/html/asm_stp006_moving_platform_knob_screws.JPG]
Moving Platform Knobs


\emoji :orange_circle: Insert the two M3 nut to the back side of the moving platform.

\emoji :purple_circle: Tighten the two screws, but __not so hard__, the knobs has
to slide freely.

\htmlonly

<video controls autoplay loop muted>
  <source src="asm_stp006_demonstration.mp4">
</video>

\endhtmlonly

@note It has to slide freely like in the video above.

@section step_7_insert_encoder Step 7 - Insert Encoder

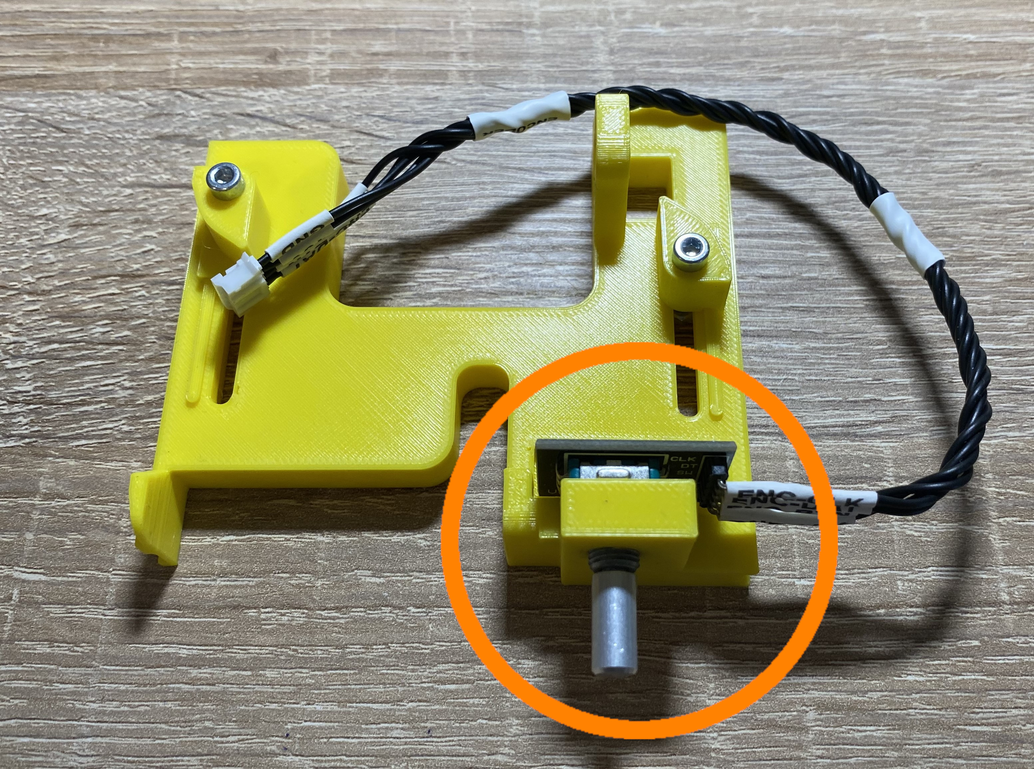
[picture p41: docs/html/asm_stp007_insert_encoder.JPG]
Insert Encoder


@pre Required parts:
* __Encoder With__ @ref encoder_cable "Cable Assembly" - 1pcs

Insert the encoder into the moving platform.

@section step_8_lock_encoder Step 8 - Lock Encoder

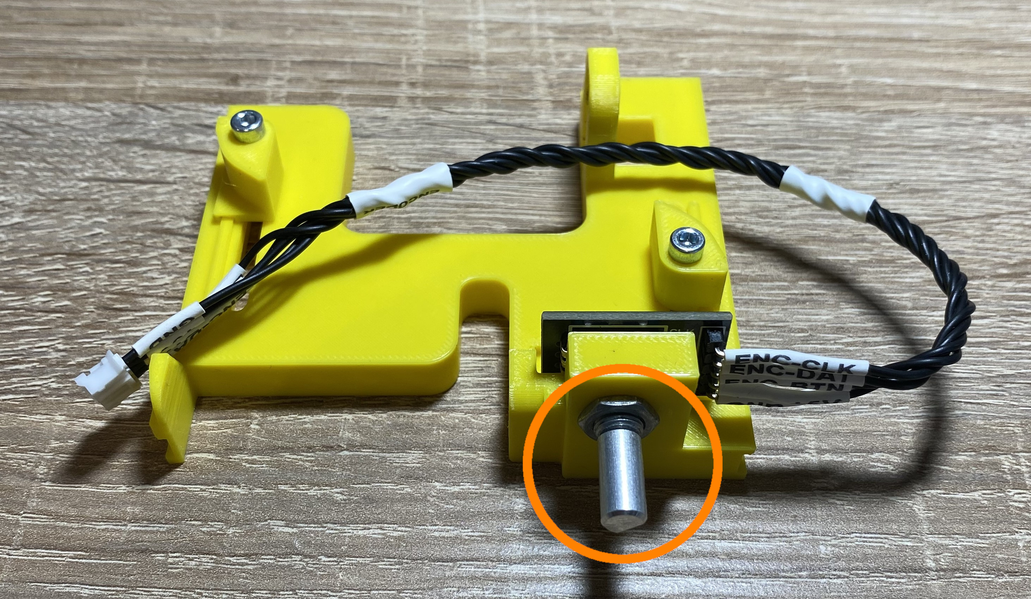
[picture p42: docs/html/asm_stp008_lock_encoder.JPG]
Lock Encoder


@pre Required parts:
* __M7 x 0.75mm__ [nut](https://www.hestore.hu/prod_10043306.html?lang=en) - 1pcs

Lock the encoder shaft with a nut. It has to be tighten.

@section step_9_slide_in_moving_platform Step 9 - Slide In The Moving Platform

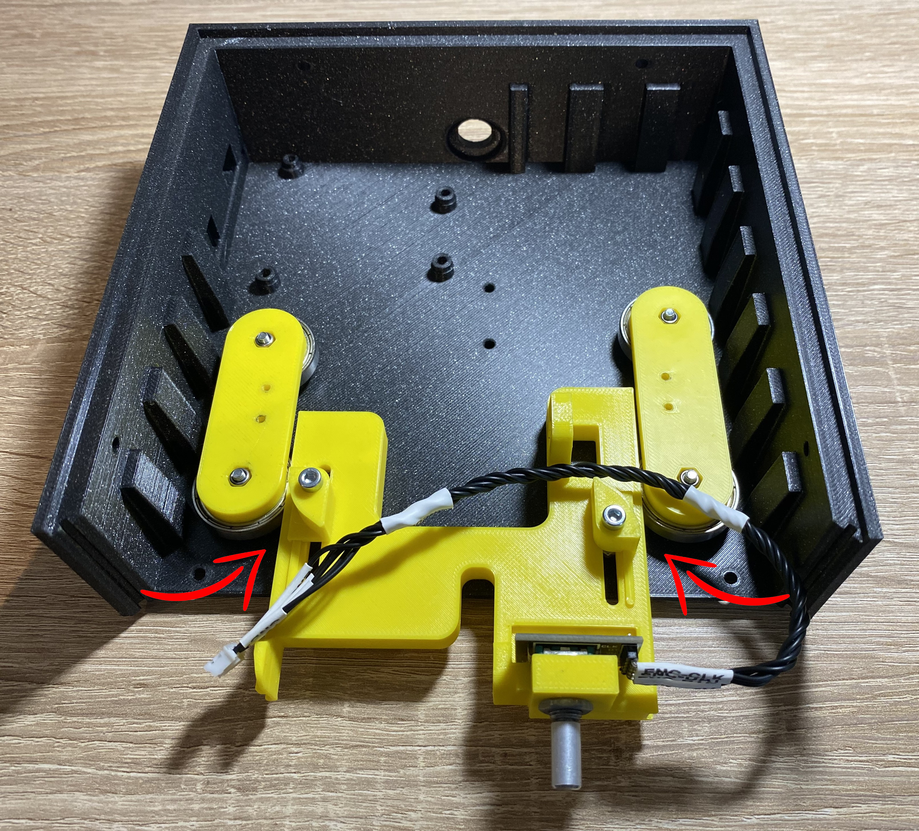
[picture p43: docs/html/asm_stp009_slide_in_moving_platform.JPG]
Slide In The Moving Platform


Slide in the moving platform to the base. The four bearings has to slide in to the
sockets on the moving platform.

@section step_10_lock_endstop_mount_screws Step 10 - Lock Endstop Mount Screws

Lock Encoder

Lock the four endstop mount screws.

@note The moving platform has to move freely forward and backward, without any side wobble.

@section step_11_motor_shaft_thread_cutting Step 11 - Motor Shaft M3 Thread Cutting

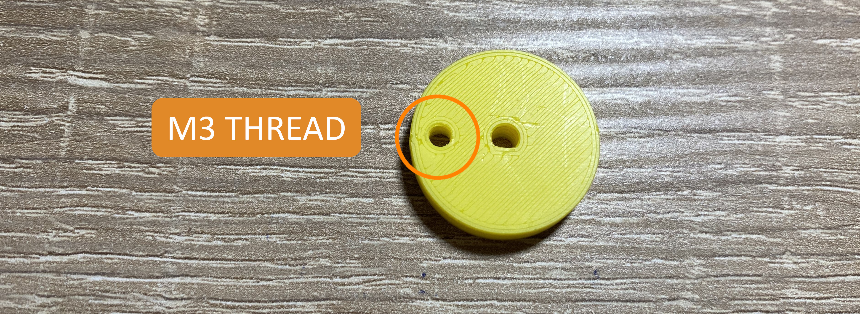
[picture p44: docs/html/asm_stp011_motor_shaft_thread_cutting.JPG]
Motor Shaft M3 Thread Cutting


@pre Required parts:
* @ref eccentric_shaft "Eccentric Shaft" - 1pcs

Cut an M3 thread to the hole on the side.

@section step_12_eccentric_shaft_assembly Step 12 - Eccentric Shaft Assembly

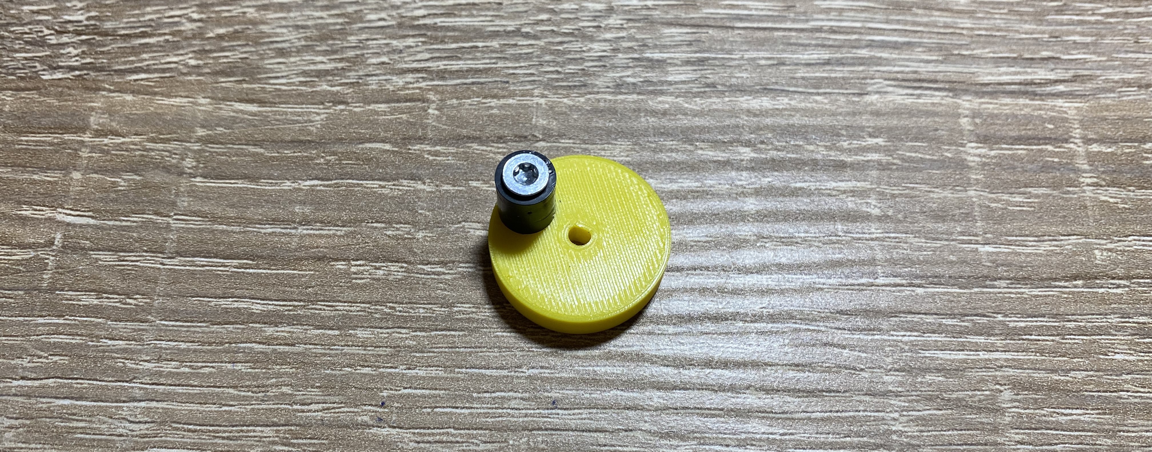
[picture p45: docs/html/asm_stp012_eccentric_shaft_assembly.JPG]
Eccentric Shaft Assembly


@pre Required parts:
* @ref step_11_motor_shaft_thread_cutting "Eccentric Shaft With Thread" - 1pcs
* __M3 x 12mm FHCS__ - 1pcs
* [Spacer](https://www.hestore.hu/prod_10024539.html) __OD=7mm ID=3.6mm H=8mm__ - 1pcs

Assemble the eccentric shaft as seen on the picture above.

@section step_13_insert_motor_screws Step 13 - Insert Motor Screws

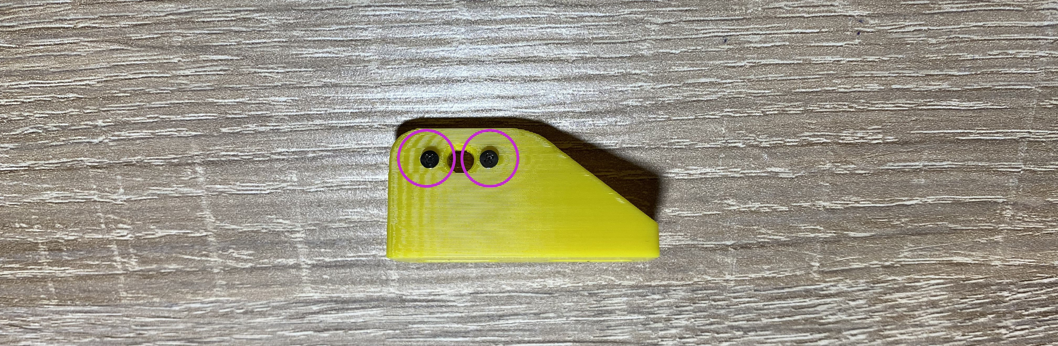
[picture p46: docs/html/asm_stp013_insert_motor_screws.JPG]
Insert Motor Screws


@pre Required parts:
* @ref motor_mount "Motor Mount" - 1pcs
* __M1.6 x 5mm FHCS__ - 2pcs

Insert the two screws into the motor mount.

@section step_14_lock_motor_screws Step 14 - Lock The Motor Screws

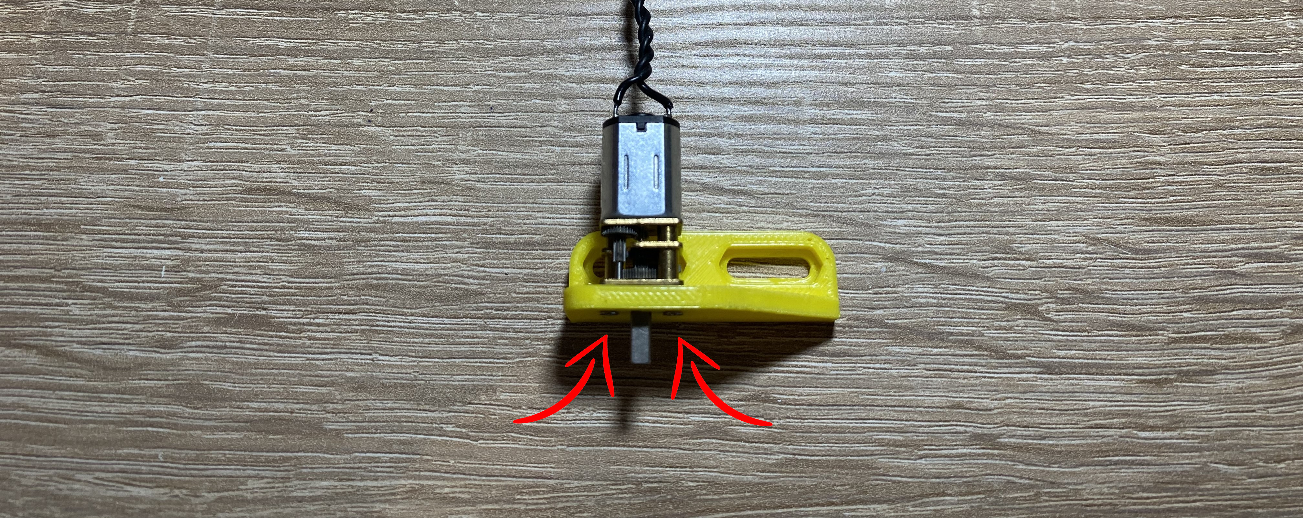
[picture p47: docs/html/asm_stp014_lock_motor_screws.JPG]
Tighten Motor Screws


@pre Required parts:
* __Motor With__ @ref motor_cable "Cable Assembly" - 1pcs

Tighten the two screws of the motor.

@section step_15_insert_motor_mount_nuts Step 15 - Insert Motor Mount Nuts

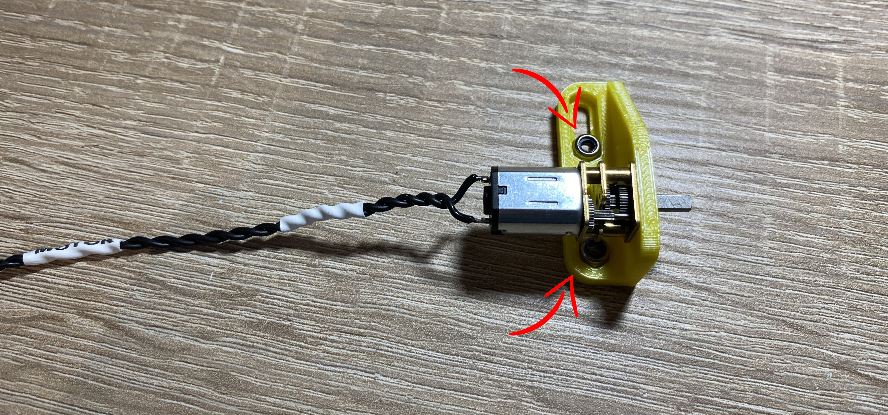
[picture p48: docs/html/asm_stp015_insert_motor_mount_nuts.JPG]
Insert Motor Mount Nuts


@pre Required parts:
* __M3 Locknut__ - 2pcs

Insert the nuts to the slots on the motor mount.

@section step_16_press_the_eccentric_shaft Step 16 - Press The Eccentric Shaft To The Motor

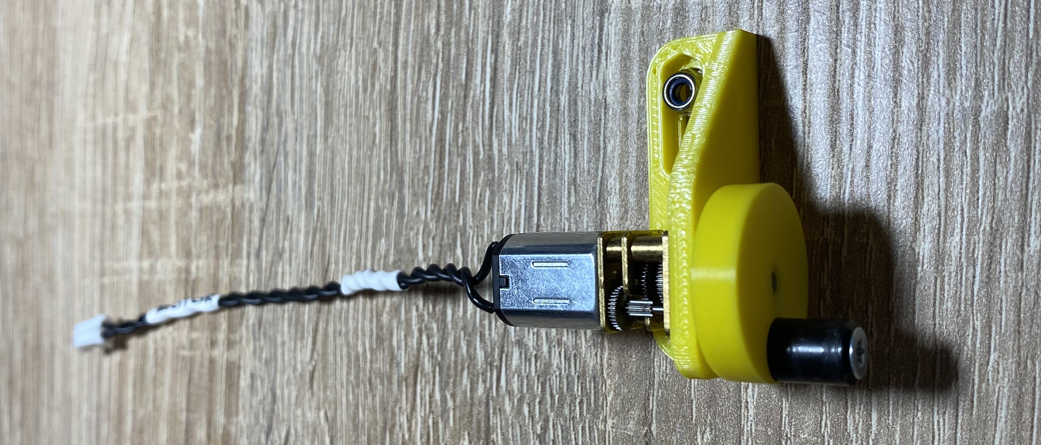
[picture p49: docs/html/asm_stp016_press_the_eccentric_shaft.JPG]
Press The Eccentric Shaft


@pre Required parts:
* @ref step_12_eccentric_shaft_assembly "Eccentric Shaft Assembly" - 1pcs

Press the eccentric shaft to the motor shaft.

@section step_17_insert_the_motor_mount Step 17 - Insert The Motor Mount

Insert The Motor Mount

@pre Required parts:
* __M3 x 10mm FHCS__ - 2pcs

Insert the motor mount to the base. From the bottom insert two M3 x 10mm flat head crews.
Tighten the two screws, but __not so hard__, the motor mount has to slide back and forward freely.

\htmlonly

<video controls autoplay loop muted>
  <source src="asm_stp017_demonstration.mp4">
</video>

\endhtmlonly

@section step_18_insert_power_jack Step 18 - Insert Power Jack

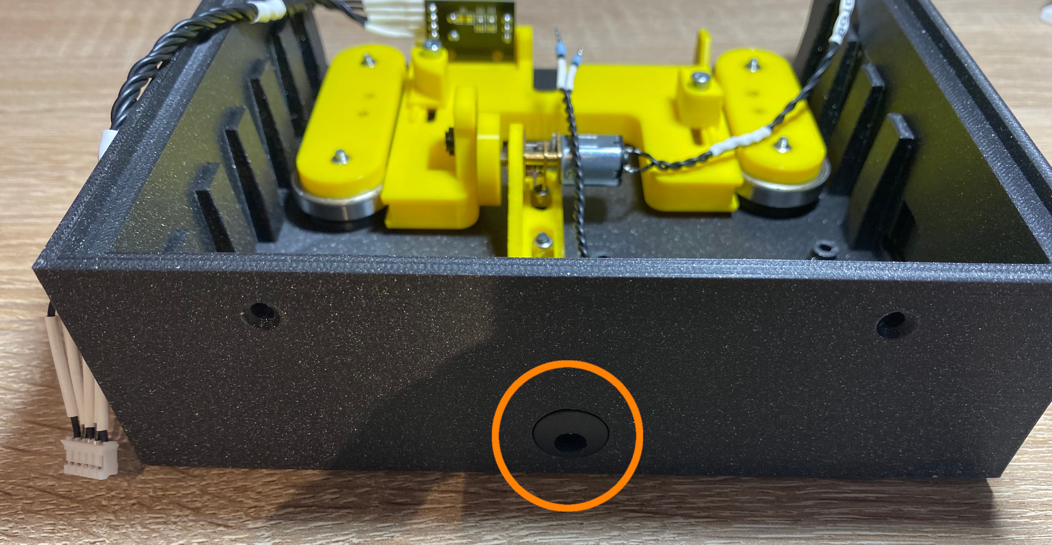
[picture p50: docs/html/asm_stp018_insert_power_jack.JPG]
Insert Power Jack


@pre Required parts:
* @ref power_connector_cable "Power Cable Assembly" - 1pcs

Insert the power jack to the slot on the back side.

@section step_19_lock_power_jack Step 19 - Lock Power Jack

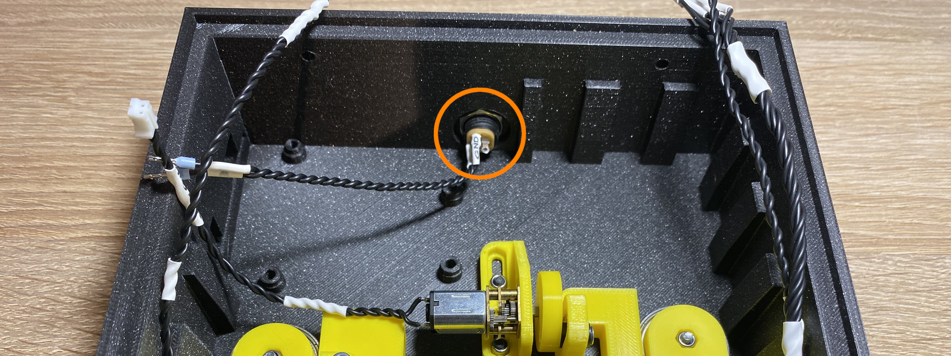
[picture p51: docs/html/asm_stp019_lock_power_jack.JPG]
Lock Power Jack


Lock the power jack with it's nut. A tweezer can be helpful for this operation.

@section step_20_insert_endstops Step 20 - Insert Endstops

Insert Endstops

@pre Required parts:
* __M2.3 x 10mm SHCS__ [Screws](https://www.tme.com/us/en-us/details/b2.3x10_bn330/bolts/bossard/1123106/) - 4pcs
* __Front Endstop__ @ref front_endstop_cable "Cable Assembly" - 1pcs
* __Back Endstop__ @ref back_endstop_cable "Cable Assembly" - 1pcs

Fix the endstops with the screws. The screw has to cut thread to the plastic,
it require some force.

@note Check the orientation of the endstops!

@section step_21_insert_pcb_screws Step 21 - Insert PCB Screws

Insert Endstops

@pre Required parts:
* __M3 x 30mm FHCS__ - 1pcs
* __M3 x 16mm FHCS__ - 3pcs

\emoji :orange_circle: M3 X 16mm screws.

\emoji :purple_circle: M3 X 30mm screw.

@section step_22_insert_arduino Step 22 - Insert Arduino

Insert Arduino

@pre Required parts:
* __Arduino Uno__ [R3](https://store.arduino.cc/products/arduino-uno-rev3) - 1pcs

Insert an Arduino UNO __R3__ to the base.

@section step_23_insert_pcb_spacers Step 23 - Insert Threaded PCB Spacers

Insert Threaded PCB Spacers

@pre Required parts:
* __M3 x 12mm__ [Spacer](https://www.tme.com/us/en-us/details/dr185rdm3x12/plastic-standoffs/dremec/185rdx12/) __With 6mm OD__ - 3pcs

Insert the spacers and tighten them.

@section step_24_insert_printed_pcb_spacer Step 24 - Insert Printed PCB Spacer

Insert Printed PCB Spacer

@pre Required parts:
* @ref pcb_spacer "PCB Spacer" - 1pcs

Insert the spacer.

@note Check the orientation!

@section step_25_insert_viking_pcb Step 25 - Insert Techno Viking PCB

Insert Techno Viking PCB

@pre Required parts:
* __Techno Viking PCB__ - 1pcs

Insert the PCB to the Arduino UNO.

@note Gently push the Techno Viking Board to the Arduino UNO.

@section step_26_insert_plastic_washer_pcb Step 26 - Insert Plastic Washer

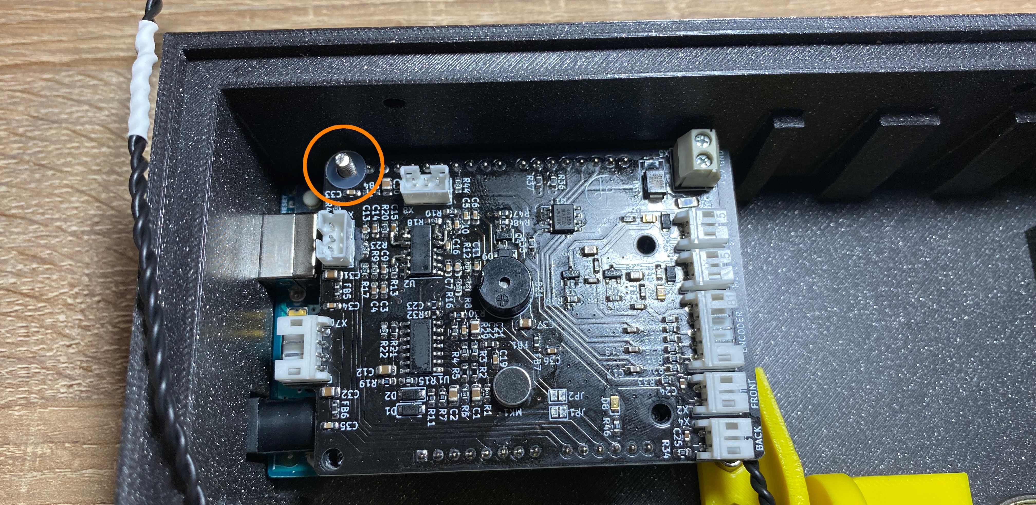
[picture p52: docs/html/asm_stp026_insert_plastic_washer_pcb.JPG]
Insert Plastic Washer


@pre Required parts:
* __M3 x 0.5mm Plastic Washer__ - 1pcs

Insert the plastic washer to the screw.

@section step_27_lock_pcb Step 27 - Lock The PCB

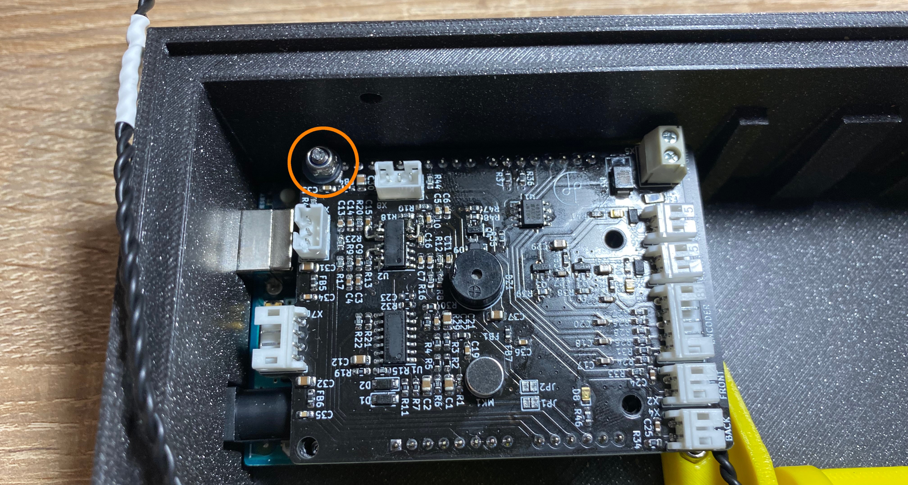
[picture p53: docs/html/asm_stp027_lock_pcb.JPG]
Lock The PCB


@pre Required parts:
* __M3 Lock Nut__ - 1pcs

Lock the screw with a nut.

@section step_28_insert_other_pcb_washers Step 28 - Insert Plastic Washer

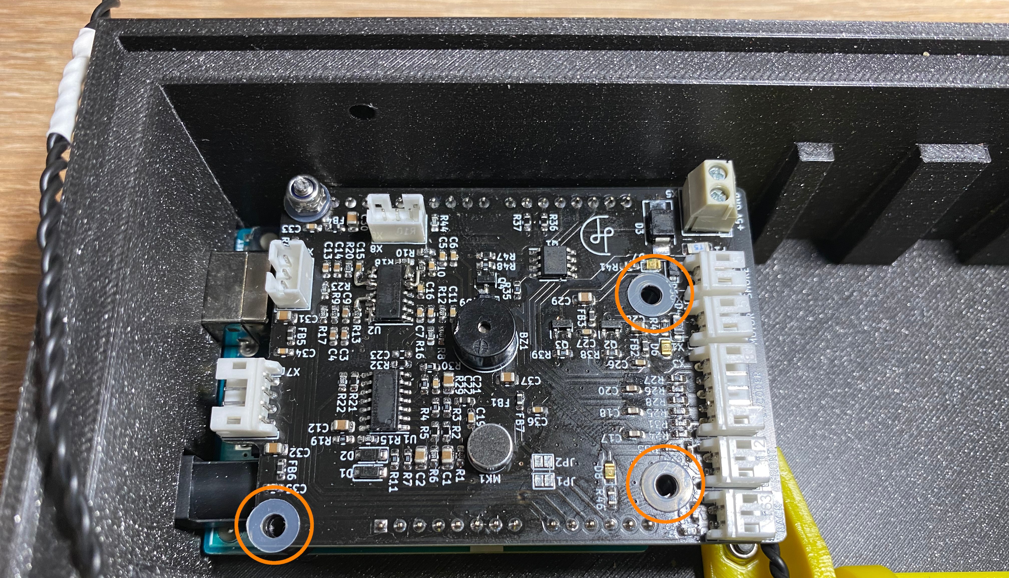
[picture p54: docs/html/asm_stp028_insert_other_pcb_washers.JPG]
Insert Plastic Washer


@pre Required parts:
* __M3 x 0.5mm Plastic Washer__ - 3pcs

Insert the remaining plastic PCB washers.

@section step_29_lock_pcb_screws Step 29 - Lock PCB Screws

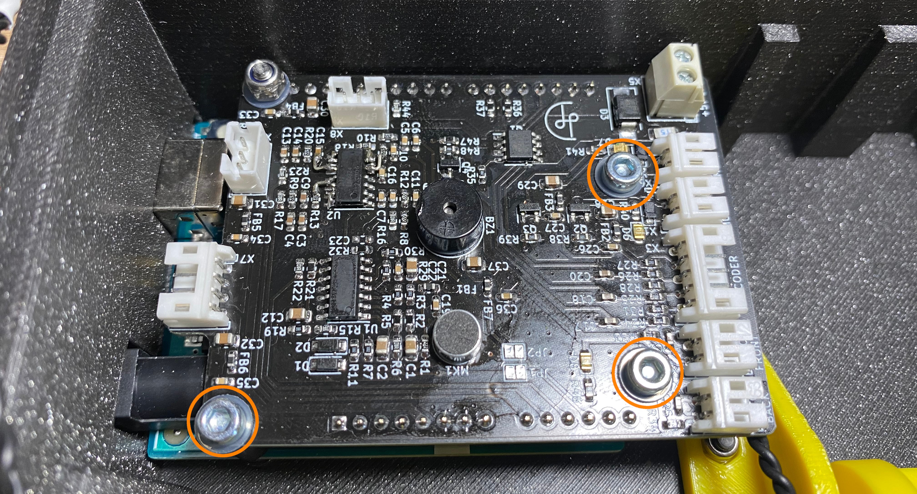
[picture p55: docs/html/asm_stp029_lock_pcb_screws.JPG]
Lock PCB Screws


@pre Required parts:
* __M3 x 5mm SHCS__ - 3pcs

Lock the PCB with the screws.

@section step_30_glue_display_holder Step 30 - Glue Display Holder

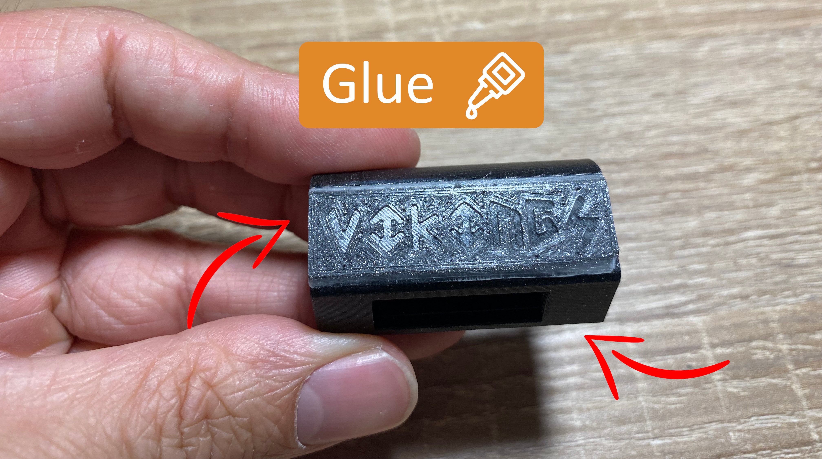
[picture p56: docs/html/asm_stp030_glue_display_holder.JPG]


@pre Required parts:
* @ref display_holder_base "Display Holder Base" - 1pcs
* @ref display_holder_front "Display Holder Front" - 1pcs
* __Super Glue__

Glue the front to the base part of the display holder.

@note Check the orientation before gluing!

@section step_31_glue_magnet_holder Step 31 - Glue Magnet Holder

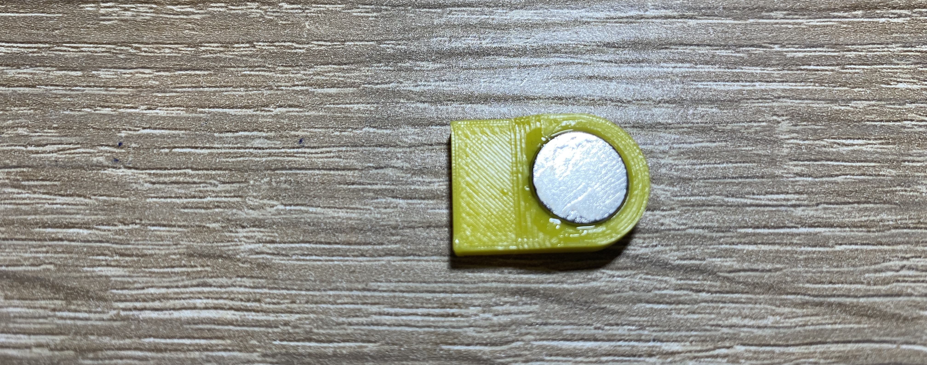
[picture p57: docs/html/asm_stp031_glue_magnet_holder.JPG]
Glue Magnet Holder


@pre Required parts:
* @ref magnet_holder "Magnet Holder" - 1pcs
* __10mm x 3mm__ [Neodymium Magnet](https://www.tme.com/us/en-us/details/gn55.2-nd-10-3/magnets/elesa-ganter/gn-55-2-nd-10-3/) - 1pcs
* __Super Glue__

Glue the magnet into the magnet holder.

@section step_32_insert_front_nuts Step 32 - Insert Front Nuts

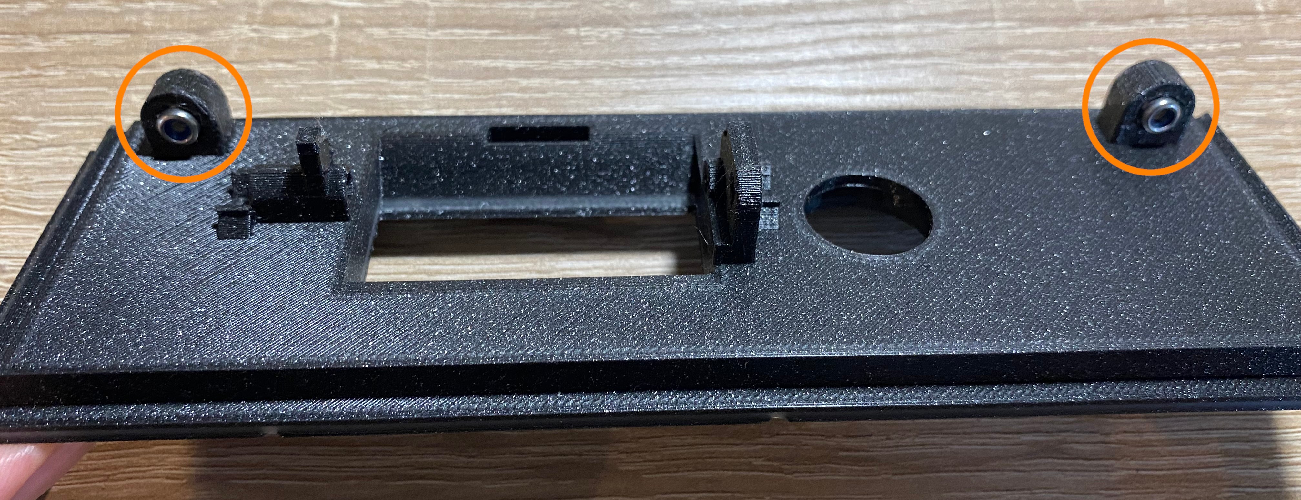
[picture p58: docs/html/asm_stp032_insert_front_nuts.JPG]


@pre Required parts:
* @ref box_front "Box Front" - 1pcs
* __M3 Lock Nut__ - 2pcs

Insert the nuts, to the slots on the front panel.

@section step_33_display_holder_thread Step 33 - Display Holder Thread Cut

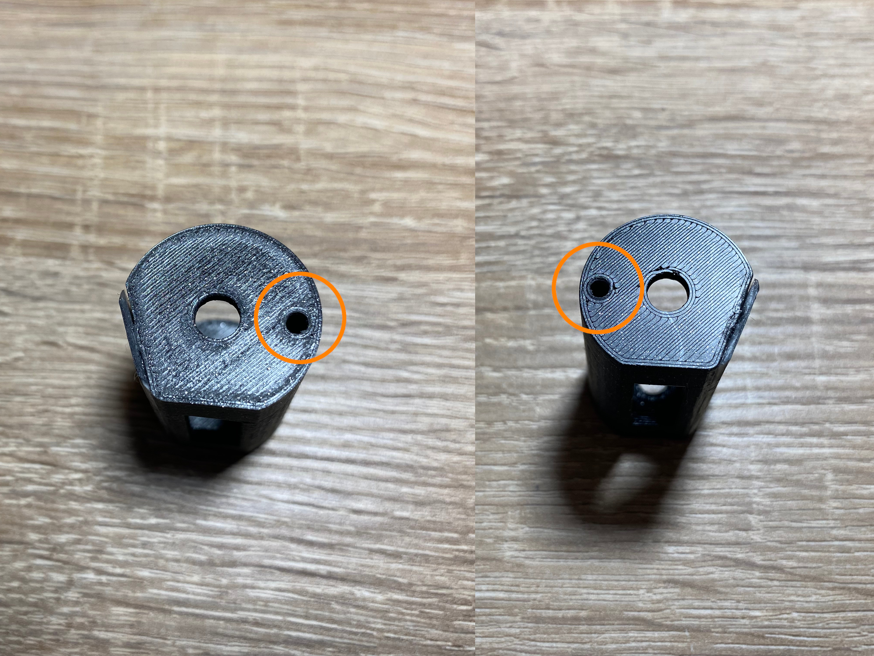
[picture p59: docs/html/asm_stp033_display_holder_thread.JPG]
Display Holder Thread Cut


@pre Required parts:
* @ref step_30_glue_display_holder "Display Holder Assembly" - 1pcs
* __M3 Thread Cutter__

Cut an M3 thread both sides of the display holder.

@note Be gentle when cutting the thread. If you cut too fast, the plastic can melt or the cutter can break.

@section step_34_insert_display_holder_screws Step 34 - Insert Display Holder Screws

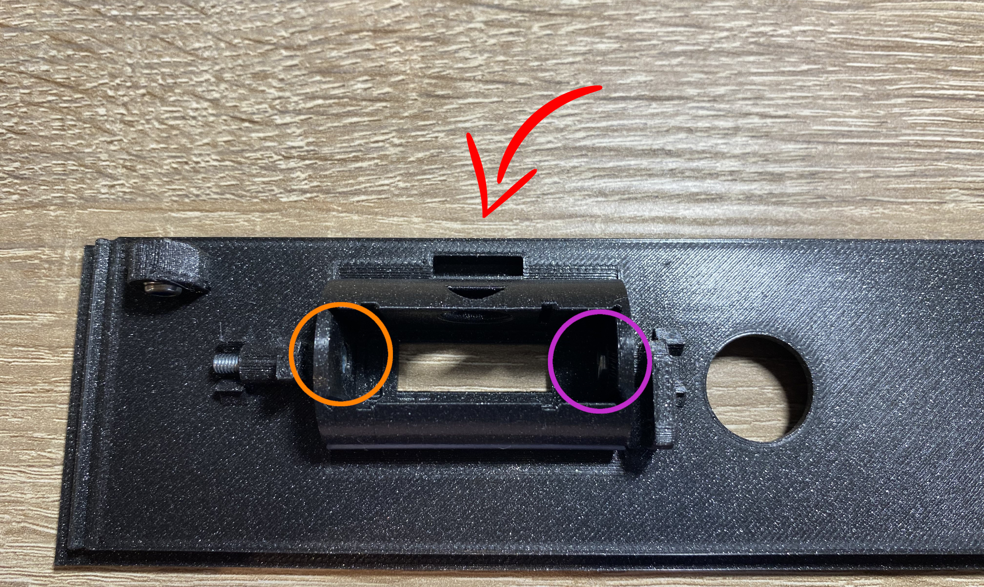
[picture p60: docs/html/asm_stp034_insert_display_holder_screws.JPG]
Insert Display Holder Screws


@pre Required parts:
* __M3 x 8mm SHCS__  - 1pcs
* __M3 x 16mm SHCS__ - 1pcs
* @ref step_33_display_holder_thread "Display Holder Assembly" - 1pcs
* @ref step_32_insert_front_nuts "Front Assembly" - 1pcs

__1.__ Insert the display holder to the front panel.

__2.__ Insert the screws from inside of the display holder.

\emoji :orange_circle: M3 x 16mm screw

\emoji :purple_circle: M3 x 8mm screw

@note Check the orientation of the slot on the front panel and the slot on the display.

@section step_35_insert_display_holder_nuts Step 35 - Insert Display Holder Nuts

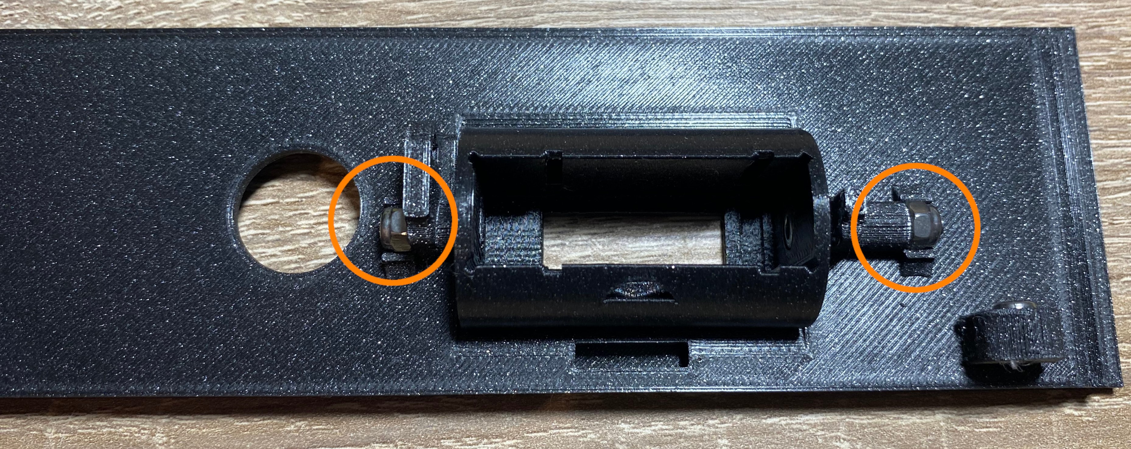
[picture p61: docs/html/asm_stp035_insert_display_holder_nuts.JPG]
Insert Display Holder Nuts


@pre Required parts:
* __M3 Lock Nut__ - 2pcs

Tighten the screws with an __Allen Key__ from the inside.

@note They have to be tight but __not overtight__! The display holder has to
rotate freely.

\htmlonly

<video controls autoplay loop muted>
  <source src="asm_stp035_demonstration.mp4">
</video>

\endhtmlonly

@section step_36_insert_display_holder_magnet Step 36 - Insert Display Holder Magnet

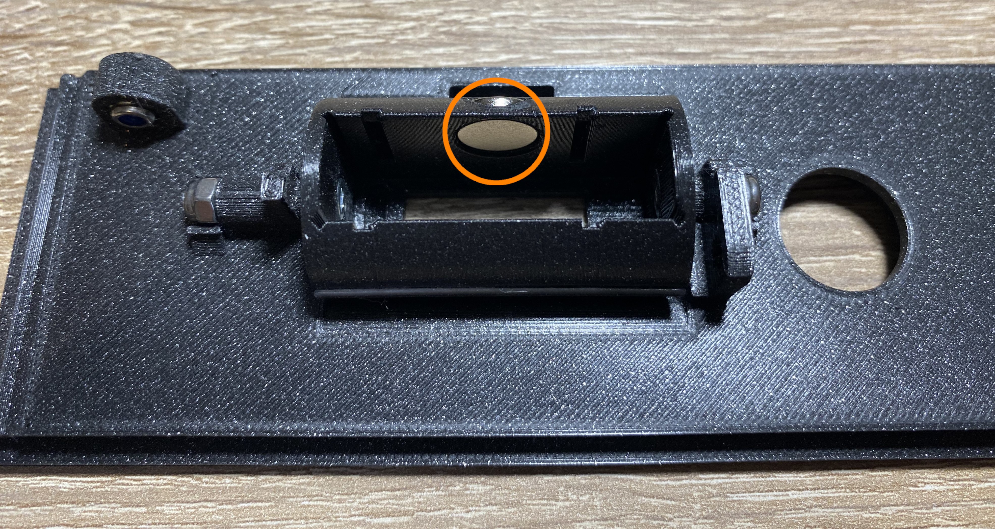
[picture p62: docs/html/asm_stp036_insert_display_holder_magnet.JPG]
Insert Display Holder Magnet


@pre Required parts:
* __10mm x 3mm__ [Neodymium Magnet](https://www.tme.com/us/en-us/details/gn55.2-nd-10-3/magnets/elesa-ganter/gn-55-2-nd-10-3/) - 1pcs

Insert the magnet in the slot on the display holder.

@note __Do NOT glue the magnet!__ It will be glued in the next steps.

@section step_37_insert_display_holder_knobs Step 37 - Insert Display Holder Knobs

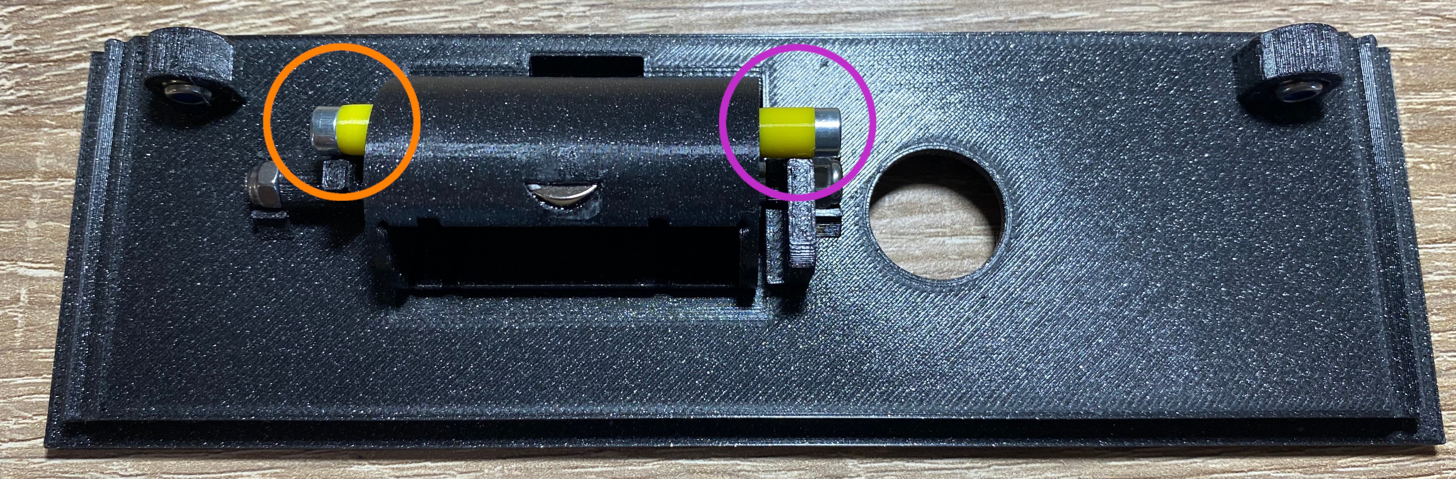
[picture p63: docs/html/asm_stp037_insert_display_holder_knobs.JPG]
Insert Display Holder Knobs


@pre Required parts:
* @ref short_screw_spacer "Short Screw Spacer" - 1pcs
* @ref long_screw_spacer "Long Screw Spacer"  - 1pcs
* __M3 x 8mm SHCS__   - 2pcs

Fix the knobs to the display holder.

\emoji :orange_circle: Short spacer

\emoji :purple_circle: Long spacer

@section step_38_test_magnets Step 38 - Test Magnets

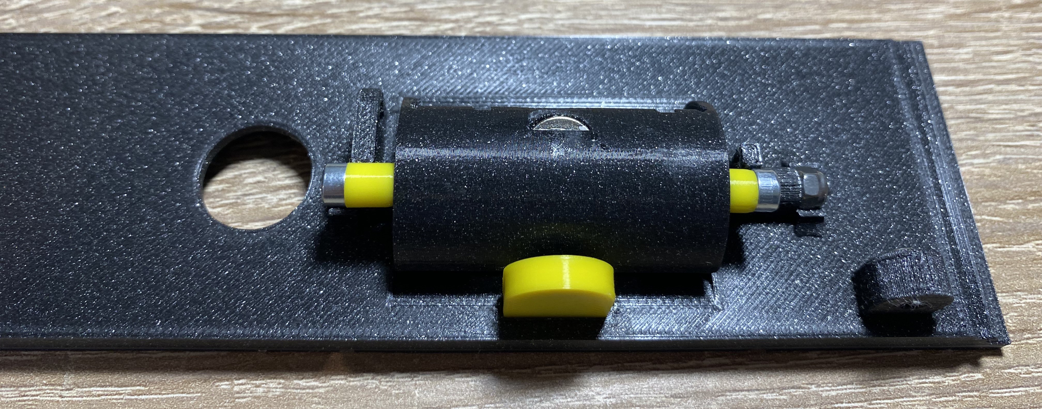
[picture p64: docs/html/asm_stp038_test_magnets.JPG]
Test Magnets


@pre Required parts:
* __Super Glue__

Insert the magnet holder to the slot on the front panel.

@note If the polarity of the magnets are correct, you should see that, the display holder closes itself.
The magnet on the front panel, should __push up__ the magnet inside the display holder.

\htmlonly

<video controls autoplay loop muted>
  <source src="asm_stp038_demonstration.mp4">
</video>

\endhtmlonly

If the magnet polarity wrong, just flip the magnet inside the display holder and try it again.

After you have tested the display holder and it's working fine, you can glue the magnet holder
into the front panel, and the magnet inside the display holder.

@section step_39_peel_off_display_cover Step 39 - Peel Off Display Cover

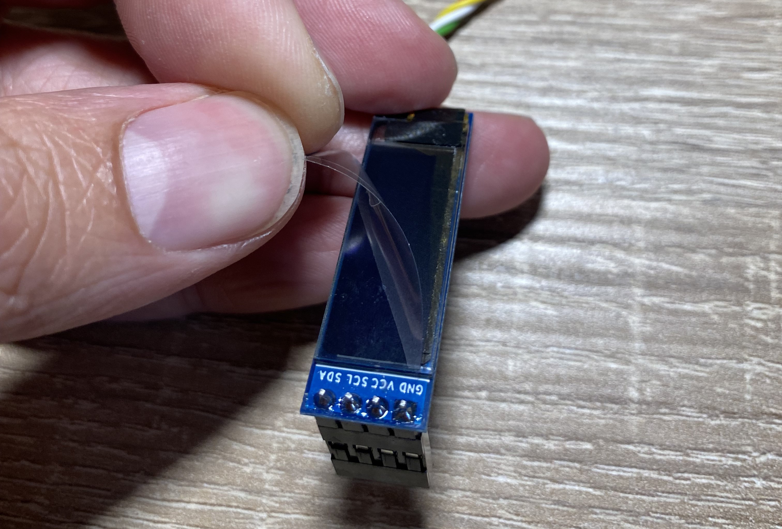
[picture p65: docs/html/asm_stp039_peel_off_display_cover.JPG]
Peel Off Display Cover


Peel off the protecting foil from the oled display.

@section step_40_insert_display Step 40 - Insert Display

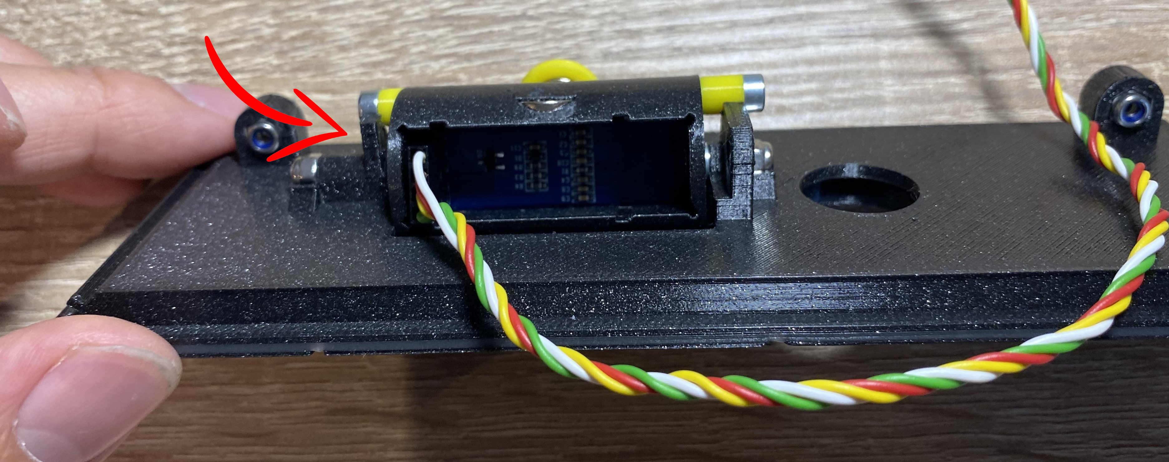
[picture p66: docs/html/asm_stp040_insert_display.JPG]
Insert Display


Insert the oled display into the display holder.

@note Check the orientation of the display cable.

@section step_41_insert_display_clamps Step 41 - Insert Display Clamps

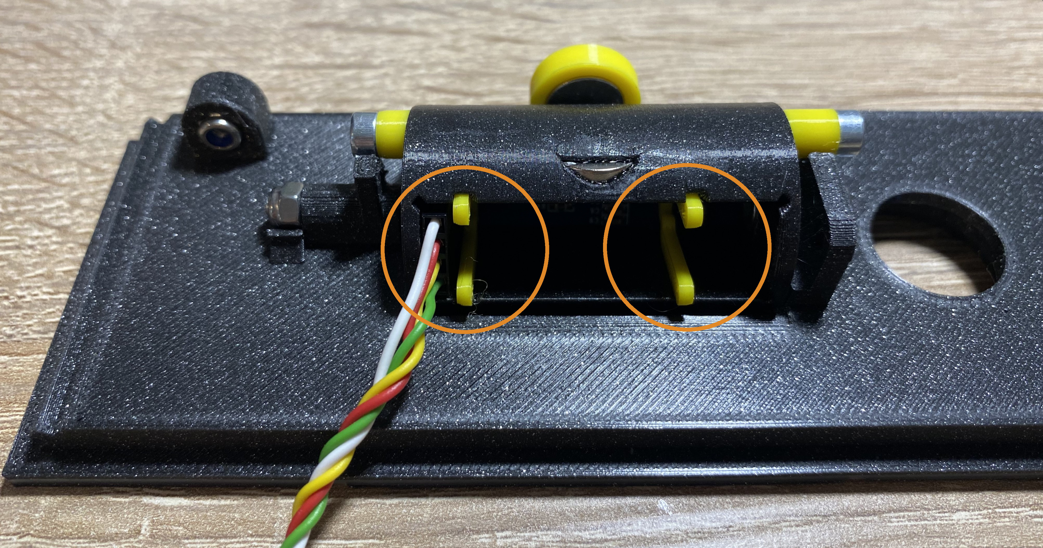
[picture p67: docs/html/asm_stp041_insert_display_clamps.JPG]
Insert Display Clamps


@pre Required parts:
* @ref display_clamp "Display Clamp" - 2pcs

Insert the clamps into the display holder.

@section step_42_rotate_shaft_back Step 42 - Rotate Shaft Back

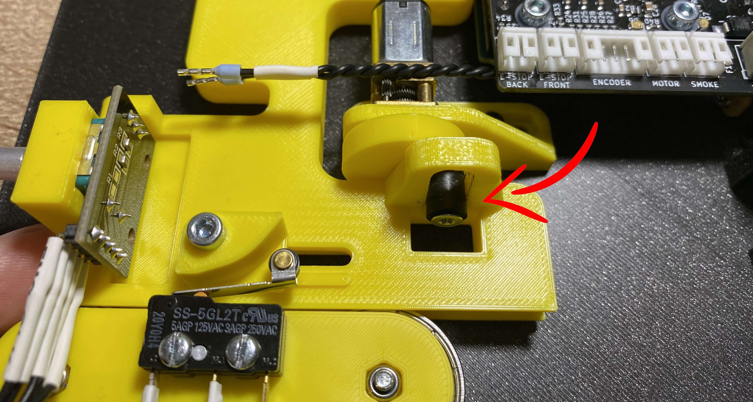
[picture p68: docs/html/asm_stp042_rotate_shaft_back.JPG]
Rotate Shaft Back


Slowly rotate the eccentric shaft to the back position.

@section step_43_insert_front Step 43 - Insert Front

Insert Front

Gently slide the front to the base.

@note The tolerances are tight, but it should slide in with a bit force. If it
doesn't, clean up the parts with an exacto knife.

Result

It should look like this.

@section step_44_lock_front Step 44 - Lock Front

Lock Front

@pre Required parts:
* __M3 x 12mm FHCS__ - 2pcs

Tighten the screws on the bottom to lock the front panel.

@section step_45_rotate_shaft_front Step 45 - Rotate Shaft Front

Rotate Shaft Front

Slowly rotate the eccentric shaft to the front position.

@section step_46_push_motor_mount_front Step 46 - Push Motor Mount Front

Push Motor Mount Front

Gently push the motor mount to the front. We have to find absolute front position.

\htmlonly

<video controls autoplay loop muted>
  <source src="asm_stp046_demonstration.mp4">
</video>

\endhtmlonly

@section step_47_lock_motor_mount Step 47 - Lock Motor Mount

Lock Motor Mount

Tighten the screws from the motor mount __while the motor mount is pushed to the front position__

If you power the motor with a bench supply( no more than __5V__, and __300mA__ ),
and crank up the voltage slowly, you should see that the mechanism opens and closes.

\htmlonly

<video controls autoplay loop muted>
  <source src="asm_stp047_test.mp4">
</video>

\endhtmlonly

@note Sorry for the color mismatch, the video captured from an early prototype.
The expected behaviour is the same.

* If the mechanism stuck at opening, that means the motor mount is set the wrong
position, it has to be adjusted. You have to push it a bit to the back.
* If the mechanism opens and closes, but the display doesn't open fully, that
means the motor mount is set the wrong position, it has to be adjusted. You have
to push it a bit to the front.

@section step_48_adjust_back_estop_knob Step 48 - Adjust Back Endstop Knob

Adjust Back Endstop Knob

1. Slowly rotate the eccentric shaft to the back position.
2. Adjust the back endstop knob position. It has to just click when the mechanism
arrives to the back position.
3. Tighten the screw to fix the knob.

@section step_49_adjust_font_estop_knob Step 49 - Adjust Front Endstop Knob

Adjust Front Endstop Knob

1. Slowly rotate the eccentric shaft to the front position.
2. Adjust the front endstop knob position. It has to just click when the mechanism
arrives to the front position.
3. Tighten the screw to fix the knob.

@section step_50_connect_wires Step 50 - Connect Wires

Connect Wires

Pinout

\emoji :orange_circle: Back endstop

\emoji :purple_circle: Front endstop

\emoji :large_blue_circle: Encoder

\emoji :green_circle: Motor

\emoji :yellow_circle: Input power \emoji :warning: __Check the polarity!__

\emoji :red_circle: Oled display.

@note If the oled display cable won't fit easily, it is recommended to unscrew the
Techno Viking PCB to access the oled display cable connector. After the display
cable connected the PCB put back to it's place.

@section step_51_oled_cable_tie Step 51 - Oled Cable Tie

Oled Cable Tie

Secure the display cable with a cable tie.

@note Make shore that the cable have enough room to move back and forward after
it has been tied.

Base Cables

The wiring should look like this.

@section step_52_encoder_knob Step 52 - Encoder Knob

Encoder Knob

@pre Required parts:
* @ref encoder_knob "Encoder Knob" - 2pcs

Insert the encoder knob to the encoder shaft.

@note The encoder knob model is designed to fit multiple length encoder shafts.
Maybe it can be pushed further than it should. In this case, insert some cotton
swabs into the hole in the knob until it's internal length is perfect.

@section step_53_upload_software Step 53 - Upload Software

Now it's time to @ref software_guide "upload the software" to the board. After it
finished you can check the functionality of the mechanism by double pressing the
encoder button. Also the display should work. Maybe some adjustment on the endstop
knobs are required.

@warning Do not continue until the mechanism and the display does not work correctly!

@note If the motor is too aggressive and fast, that means you made better mechanism than me \emoji :tada:.
In this case you have to lower the motor power by reducing the @ref MOTOR_PWM parameter in the firmware.
It requires to rebuild the software and upload it again.

@section step_54_led_holder_nuts Step 54 - Insert LED Holder Nuts

Insert LED Holder Nuts

@pre Required parts:
* @ref led_holder "Led Holder" - 1pcs
* __M3 Lock Nut__   - 5pcs
* __M3  Hexut__     - 4pcs

Insert the nuts into their slots.

\emoji :orange_circle: Regular nut

\emoji :purple_circle: Locknut

@note On the photo I have used locknuts everywhere. It was a mistake.

@section step_55_insert_led_ring_mount Step 55 - Insert LED Ring Mount

Insert LED Ring Mount

@pre Required parts:
* @ref led_ring_mount "Led Ring Mount" - 1pcs

Insert the LED ring mount to the LED holder.

@section step_56_insert_cotton_swab Step 56 - Insert Cotton Swab

Cotton Swab From Ear Stick

3mm Long Cotton Swab Rod

@pre Required parts:
* @ref atomizer_socket "Atomizer Socket" - 1pcs
* __Cotton Swab__                   - 1pcs

@note Some humidifier modules come with a cotton swab rod, some don't.
If your does not contain it, you can use an ear cleaning stick, and use
the cotton swab from it. If your module come with a cotton swab rod,
you have to cut exactly __3mm__ long peace of it with an exacto knife.

Insert the cotton swab to the center slot on the atomizer socket.

@section step_57_insert_atomizer Step 57 - Insert Atomizer

Insert Atomizer

@pre Required parts:
* __20mm Ceramic Humidifier Transducer With Silicone Housing__ - 1pcs

Insert the atomizer to the socket on the atomizer socket.

@note Check the wire orientation. It has to slide into the slot on the atomizer socket.

@warning Do __NOT__ use any glue or sealant. It could clog the return path and the humidifier
wont work. Trust me I have tried it...

@section step_58_fix_atomizer_socket Step 58 - Fix Atomizer Socket

Fix Atomizer Socket

@pre Required parts:
* __M3 x 20mm FHCS__ - 5pcs
* __M3 Lock Nut__    - 4pcs

\emoji :purple_circle: Tighten the screws using a __star pattern__. If it's too loose, it will leak.

\emoji :orange_circle: Insert the nuts to the slots.

@note Check the wire during the process. It can stuck between the two surfaces.

@section step_59_humidifier_pcb_holes Step 59 - Humidifier PCB Holes

@pre Required parts:
* __3.2mm Drill Bit__

I have bought a few humidifier module and the hole positions were different for each.
If your modules hole positions are different, lock the board to one hole and drill
another one. To fix the humidifier PCB, at least two screws are required.

@section step_60_humidifier_pcb_screws Step 60 - Insert Humidifier PCB Screws

Insert Humidifier PCB Screws

@pre Required parts:
* __M3 x 8mm Imbus Head Screw__ - 2pcs
* __M3 x 0.5mm Plastic Spacer__ - 8pcs

__1.__ Insert the two screws from the top.

__2.__ Insert 4 - 4 plastic spacer to the screw from the bottom.

@section step_61_fix_humidifier_pcb Step 61 - Fix Humidifier PCB

Fix Humidifier PCB

@pre Required parts:
* __M3 Regular Nut__ - 2pcs

\emoji :orange_circle: Tighten the screws.

\emoji :purple_circle: Connect the humidifier disc cable to the PCB.

@section step_62_humidifier_test Step 62 - Humidifier Test

__1.__ You have to make shore that the humidifier does not leak.

Fill The Tank

Fill the tank ( marked purple ) with a bit of water. Do not overfill it! It usually
takes a few minutes to soak the cotton swab, please wait at least 5 minutes. If the
cotton swab soaks all the water pleas add a bit again.

If you connect the USB port of the humidifier PCB to a phone charger you should see
some fog \emoji :ghost:

\htmlonly

<video controls autoplay loop muted>
  <source src="asm_stp062_humidifier_test_video.mp4">
</video>

\endhtmlonly

__2.__ Leave some water in the tank and put some dry paper towels between the tank and the table.
Let it on the table for a day at least. If it does not leak after a day it probably good.

@section step_63_insert_led_strip Step 63 - Insert LED Strip

Insert LED Strip

@pre Required parts:
* __LED Strip__ @ref led_strip_cable "Cable Assembly" - 1pcs

1. Insert the LED strip into the slots on the LED holder. It does not require any glue!
2. Feed through the cable on the hole at the corner.

@section step_64_skull_inserts Step 64 - Skull Inserts

Skull Inserts

@pre Required parts:
* @ref skull "Skull" - 1pcs
* __M3 inserts__ - 2pcs

Press the two inserts to the plastic with a soldering iron. I used  the with 200°C
and it worked perfectly.

@note Let it cool for 2-3 minutes.

@section step_65_fix_skull Step 65 - Fix Skull

Fix Skull

@pre Required parts:
* @ref box_top "Box Top"     - 1pcs
* __M3 x 10mm BHCS__ - 2pcs

Tighten the two screws to fix the skull to the top.

Top Part Finished

It should look like this.

@section step_66_insert_the_led_ring Step 66 - Insert LED Disc

Insert LED Disc

@pre Required parts:
* __LED Disc__ @ref led_disc_cable "Cable Assembly" - 1pcs

Insert the LED disc to the slot.

@section step_67_connect_top_cables Step 67 - Connect Top Cables

Connect Top Cables

Connect the top section's cables to the Techno Viking PCB.

\emoji :orange_circle: LED disc

\emoji :purple_circle: Humidifier

\emoji :large_blue_circle: LED strip

@section step_68_insert_led_holder Step 68 - Insert LED Holder

Insert LED Holder

Insert the LED holder to the base.

@note Check the orientation.

@section step_69_insert_top Step 69 - Insert Top

Insert Top

@pre Required parts:
* __M3 x 20mm FHCS__ - 4pcs

1. Insert the top part.
2. Tighten the 4 screws on the sides( 2 on the back 1 - 1 on the front sides ).

@section step_70_fix_top Step 70 - Fix Top

Fix Top

@pre Required parts:
* __M3 x 20mm FHCS__ - 4pcs



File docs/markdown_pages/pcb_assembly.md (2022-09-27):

@page pcb_assembly PCB Assembly

@section how_to_get_the_pcb How To Get The PCB?

This is a tricky question. If you never made a PCB and you don't want to try it, maybe I can help.
I can make a few in a month but it's depending on my free time, and suppliers( shortage... ). If
you are in trouble with the PCB you can contact me and I will try to help.

The other option is to create the PCB for yourself. It is not that hard actually, you need a good soldering iron and a
tweezer. There are a ton of videos online about soldering, but here is my preferred one:

\htmlonly

<iframe width="1024" height="786" src="https://www.youtube.com/embed/VxMV6wGS3NY" title="YouTube video player" frameborder="0" allow="accelerometer; autoplay; clipboard-write; encrypted-media; gyroscope; picture-in-picture" allowfullscreen></iframe>

\endhtmlonly

You also need some naked PCB panels, I highly recommend [JLCPCB](https://jlcpcb.com/). It is cheap and fast.
The quality for this price is very good, and the interface is simple. Just upload the
<a href="gerber.zip" target="_blank"><b>gerber files</b></a> and fill inthe settings as shown below:

JLCPCB Settings

@note Please check the settings twice. A wrong setting can be a huge price difference!

@section how_to_get_the_right_components How To Get PCB Components?

The whole PCB is designed with [KiCad](https://www.kicad.org/) and it has a very useful plugin
called [Interactive HTML BOM](https://github.com/openscopeproject/InteractiveHtmlBom).
This plugin generates a browser-based interactive tool, where you can find all the components
needed for the board. Also, it shows where those components shall be placed on the PCB.

\htmlonly

<iframe src="ibom.html" style="height:800px;width:100%;" title="description"></iframe>

\endhtmlonly

@note On smaller monitors, you may open this document <a href="ibom.html" target="_blank"><b>separately</b></a>.

Of course, if you don't like the browser version of the BOM, you can open the whole project with
KiCad.

@section schematic Schematics

This section explains the different modules and their job on the panel. You can skip this part if you
are not interested in circuit design.

\htmlonly

  <embed src="Schematics.pdf#toolbar=0" width="100%" height="800px">

\endhtmlonly

@note On smaller monitors, you may open this document <a href="Schematics.pdf" target="_blank"><b>separately</b></a>.

@subsection analog_stage Analog Stage

__This part consists of seven amplifier stages:__

1. __Microphone Preamplifier:__ The condenser microphone generates a very low amplitude signal. This stage amplifies this
signal to make it usable for the other stages. Also, this amplified signal is connected to the A3 ADC channel by default.
2. __Half-Wave Rectifier:__ This stage consumes two amplifiers. In this configuration, it is a peak detector. The software
is using this signal to detect the noise floor of the environment. It is connected to the A2 ADC channel.
3. __Low-Pass Filter:__ This stage attenuates frequency components above 500Hz. It could be used for something, but
this signal is not used by default. If you want, you can switch the state of JP1 and JP2 jumpers to use this channel.
In this way, it will be connected to the A3 ADC channel instead of the preamplifier output.
__The software does not support it, you have to implement it if needed.__
4. __High-Pass Filter:__ This stage attenuates frequency components below 2000Hz. It is connected to the A1 ADC channel.
5. __Band-Pass Filter:__ The last stage consumes two amplifiers. It has a pass band between 500Hz and 2000Hz. That
means it passes all frequency components in this range, but outside this band, it attenuates.

@subsection half_supply_generator Half-Supply Generator

This part generates exactly half of the supply voltage. The filters need a reference voltage between the power rails
to swing the output voltage up and down. This is why we need a half-supply generator. Also, this means that the filter's
output voltage is shifted to half supply instead of 0V.

@subsection power_input Power Input

This section is responsible to supply the circuits safely. It has a thermal fuse, a TVS diode, and polarity protection.
I tried to make this as safe as possible.

@subsection endstops Endstops

The endstops are just simple switches, they have to be debounced. This simple part does this job.

@subsection buzzer_driver Buzzer Driver

The panel has a small buzzer. It is useful to create some interaction when you navigate the menu. This section consists
of a transistor, that drives the buzzer, and some power filtering. The driver stage has a protection diode, so both
electromechanical and piezoelectric buzzers can be used.

@subsection display_interface Display Interface

This is just a connector for the display cable with two pull-up resistors for the I2C signals. It also has some power filtering.

@subsection dc_motor_driver DC-Motor Driver

The circuit is the same as the buzzer driver. Its job is to drive the motor.

@subsection humidifier_switch Humidifier Switch

The circuit is the same as the buzzer driver. Its job is to turn on or off the humidifier module.

@subsection led_interface LED Interface

This contains two connectors for the two LED strips and some power filtering. It also has some series
resistance, which is required to use the WS2812 and WS2813 chips properly.

@subsection encoder_interface Encoder Interface

The encoder is three switches, they have to be debounced. This section does this.

@section pcb_test PCB Test

1. After you have assembled the PCB it is necessary to test it, before connecting it to the Arduino.
This is the smoke test. The best method is to have a bench power supply, and power up the board with
s 5V and 100mA current limit. The power LED should turn on, and the current consumption should be less
than 50mA( for just the bare PCB ).
2. If the smoke test succeeds it's time to connect the PCB to the Arduino UNO and
@ref software_guide "upload the firmware" to it. If you can program the Arduino without a problem that
is a good sign.
3. Lastly, you have to connect all the peripherals to the board and try them before the final assembly.
For this step, you need all the @ref cable_preparation "peripherals and cables to be prepared". Every
connector is labeled on the PCB, so you can find the right one for each peripheral easily.
4. If everything works, you can jump to the @ref assembly_instructions "final assembly".

@note If the smoke test fails, and the current consumption is high, you probably assembled one or more components wrong.
To identify the problem, there are some practices. For example, if something blows up, it has to be replaced without
a question. Also if a component gets hot for the touch it is probably dead, I recommend replacement. Also, check the
IC-s and silicon-based component's orientation. If they are soldered in the wrong orientation they usually die at power up.

@section cable_preparation Cable Preparation

@subsection power_connector_cable Power Connector Cable

Power Connector Cable

The cable length from the connector to the end sleeves is approximately __110mm__,
the cable is __0.22mm2 ( 24 AWG )__, and the ends have cable end sleeves.
The connector, that I used can be found [here](https://www.hestore.hu/prod_10038660.html?lang=en).

@warning Always check the polarity with a multimeter, before connecting to the PCB!
The best practice is to mark the cable with a label printer or some kind of sticker.

@subsection humidifier_cable Humidifier Cable

Humidifier Cable

The cable length from the humidifier to the end connector is approximately __140mm__,
the cable is __0.22mm2 ( 24 AWG )__, and the end has a PHR-2 JST connector.
The connector, that I used can be found [here](https://www.tme.com/us/en-us/details/phr-2/raster-signal-connectors-2-00mm/jst/).
The crimping tool for the connector, that I used can be found
[here](https://www.tme.com/us/en-us/details/fut.pa-09/crimping-tools-for-terminals/engineer/pa-09/).

Humidifier Back

The polarity is marked at the back side of the humidifier board. Also, a little solder bridge
has to be made to turn on the humidifier without a button press.
The humidifier module, that I used can be found
[here](https://www.hestore.hu/prod_10041539.html?lang=en).

@warning Always check the polarity with a multimeter, before connecting to the PCB!
The best practice is to mark the cable with a label printer or some kind of sticker.

@subsection led_disc_cable LED Disc Cable

LED Disc Cable

LED Disc Connector

The cable length from the LED disc to the end connector is approximately __160mm__,
the cable is __0.22mm2 ( 24 AWG )__, and the end has a PHR-3 JST connector.
The connector, that I used can be found [here](https://www.tme.eu/hu/details/phr-3/jelcsatlakozok-raszter-2-00mm/jst/).
The crimping tool for the connector, that I used can be found
[here](https://www.tme.com/us/en-us/details/fut.pa-09/crimping-tools-for-terminals/engineer/pa-09/).

@note The cable has to be soldered to the bottom of the LED disc. The bottom side has SMD solder terminals
where the cable has to be soldered. They are labeled, so it's easy to identify the wires. There is an input
and an output connector, the input one has to be used.

The LED disc, that I used can be found
[here](https://www.hestore.hu/prod_10037905.html?lang=en).

@subsection led_strip_cable LED Strip Cable

LED Strip Cable

LED Strip Connector

The cable length from the LED strip to the end connector is approximately __130mm__,
the cable is __0.22mm2 ( 24 AWG )__, and the end has a PHR-3 JST connector.
The connector, that I used can be found [here](https://www.tme.eu/hu/details/phr-3/jelcsatlakozok-raszter-2-00mm/jst/).
The Crimping tool for the connector, that I used can be found
[here](https://www.tme.com/us/en-us/details/fut.pa-09/crimping-tools-for-terminals/engineer/pa-09/).

@note The LED strip has to be cut to length with 27 LEDs. The wires have to be soldered.
If the strip is made with WS2813 LEDs, the BI ( Backup Input ) pin has to be soldered to the
ground. Also, a __470uF 10V capacitor__ has to be soldered to the input across __VCC__ and __GND__
on the strip to stabilize the power rail. The width of the capacitor has to be equal to or
less than the LED strip( which is 10mm ).

@warning The polarity of the capacitor has to be correct, otherwise, it will blow up.

LED strip, that I used can be found
[here](https://www.tme.com/us/en-us/details/hcbaa60wg/light-sources-led-ribbon/worldsemi/hc-f5v-60l-60led-w-ws2813-ip65/).

@subsection oled_display_cable Oled Display Cable

Oled Display Cable

Oled Display Connector

The cable length from the Oled display to the end connector is approximately __210mm__,
the cable is __0.22mm2 ( 24 AWG )__, and the end has a PHR-4 JST connector.
The connector, that I used can be found [here](https://www.tme.eu/hu/details/phr-4/jelcsatlakozok-raszter-2-00mm/jst/).
The display side of the cable also has a connector, it can be found
[here](https://www.tme.com/us/en-us/details/nsr-04/pin-headers/ninigi/).
The crimping tool for the connector, that I used can be found
[here](https://www.tme.com/us/en-us/details/fut.pa-09/crimping-tools-for-terminals/engineer/pa-09/).

The oled display module, that I used can be found
[here](https://www.hestore.hu/prod_10040388.html?lang=en).

@subsection encoder_cable Encoder Cable

Encoder Cable

Encoder Connector

The cable length from the encoder to the end connector is approximately __200mm__,
the cable is __0.22mm2 ( 24 AWG )__, and the end has a PHR-5 JST connector.
The connector, that I used can be found [here](https://www.tme.eu/hu/details/phr-5/jelcsatlakozok-raszter-2-00mm/jst/).
The crimping tool for the connector, that I used can be found
[here](https://www.tme.com/us/en-us/details/fut.pa-09/crimping-tools-for-terminals/engineer/pa-09/).

The encoder module, that I used can be found
[here](https://www.hestore.hu/prod_10043306.html).

@note On the encoder side, the wires have to be soldered to the pins on the encoder module.
Use heat-shrink tubes to isolate the wires from each other.

@subsection front_endstop_cable Front Endstop Cable

Front Endstop Cable

The cable length from the front endstop to the end connector is approximately __155mm__,
the cable is __0.22mm2 ( 24 AWG )__, and the end has a PHR-2 JST connector.
The connector, that I used can be found [here](https://www.tme.com/us/en-us/details/phr-2/raster-signal-connectors-2-00mm/jst/).
The crimping tool for the connector, that I used can be found
[here](https://www.tme.com/us/en-us/details/fut.pa-09/crimping-tools-for-terminals/engineer/pa-09/).

@note Because it is a mechanical switch, the polarity off the connector doesn't matter.

The endstop switch, that I used can be found
[here](https://www.tme.eu/hu/details/ss-5gl2t/mikrokapcsolok-snap-action/omron-ocb/).

@subsection back_endstop_cable Back Endstop Cable

Back Endstop Cable

The cable length from the back endstop to the end connector is approximately __155mm__,
the cable is __0.22mm2 ( 24 AWG )__, and the end has a PHR-2 JST connector.
The connector, that I used can be found [here](https://www.tme.com/us/en-us/details/phr-2/raster-signal-connectors-2-00mm/jst/).
The crimping tool for the connector, that I used can be found
[here](https://www.tme.com/us/en-us/details/fut.pa-09/crimping-tools-for-terminals/engineer/pa-09/).

@note Because it is a mechanical switch, the polarity off the connector doesn't matter.
The endstop switch, that I used can be found
[here](https://www.tme.eu/hu/details/ss-5gl2t/mikrokapcsolok-snap-action/omron-ocb/).

@subsection motor_cable Back Motor Cable

Motor Cable

The cable length from the motor to the end connector is approximately __105mm__,
the cable is __0.22mm2 ( 24 AWG )__, and the end has a PHR-2 JST connector.
The connector, that I used can be found [here](https://www.tme.com/us/en-us/details/phr-2/raster-signal-connectors-2-00mm/jst/).
The crimping tool for the connector, that I used can be found
[here](https://www.tme.com/us/en-us/details/fut.pa-09/crimping-tools-for-terminals/engineer/pa-09/).

@note Because of the mechanical construction of the open mechanism, the polarity on the connector doesn't matter.

DC motor, that I used can be found
[here](https://www.hestore.hu/prod_10042774.html?lang=en).

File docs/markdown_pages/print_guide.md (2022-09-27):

@page print_guide Print Guide

I have made a lot of iterations for some parts to make them perfectly fit. I had
a ton of ideas at the beginning on how to make this whole thing happen, so I tried
them and I chose the solution that I think is the best. After a month of tweaking,
I think the models are ready for anyone. Every FDM printer nowadays should be capable
to make them.

Prototypes

If you don't like the color design of my version, you can use different colors
and materials of course. Be creative and create something that you would like to
see on your desk.

@note Only the atomizer socket should be printed from PETG because it will hold
some water.

@section basic_parts Basic Parts

Firstly let's start with the easy ones. These parts do not require any advanced settings.
Just set the layer height to 0.2mm and print them.

@subsection display_clamp Display Clamp

Display Clamp

@pre
* __Required quantity:__ 2pcs
* __Color:__ \emoji :yellow_circle: Yellow
* __Recommended material:__ PLA
* __Material, that I have used:__ [Prusament PLA Pineapple Yellow 1kg](https://www.prusa3d.com/product/prusament-pla-pineapple-yellow-1kg/)
* __Required filament:__ 0.33g
* __Estimated print time:__ 3m
* __File for Prusa Slicer:__ <a href="display_clamp_2pcs.3mf" target="_blank"><b>display_clamp_2pcs.3mf</b></a>
* __File for other slicers:__ <a href="display_clamp_2pcs.stl" target="_blank"><b>display_clamp_2pcs.stl</b></a>

@subsection motor_mount Motor Mount

Motor Mount

@pre
* __Required quantity:__ 1pcs
* __Color:__ \emoji :yellow_circle: Yellow
* __Recommended material:__ PLA
* __Material, that I have used:__ [Prusament PLA Pineapple Yellow 1kg](https://www.prusa3d.com/product/prusament-pla-pineapple-yellow-1kg/)
* __Required filament:__ 3.47g
* __Estimated print time:__ 39m
* __File for Prusa Slicer:__ <a href="motor_mount_1pcs.3mf" target="_blank"><b>motor_mount_1pcs.3mf</b></a>
* __File for other slicers:__ <a href="motor_mount_1pcs.stl" target="_blank"><b>motor_mount_1pcs.stl</b></a>

@subsection eccentric_shaft Eccentric Shaft

Eccentric Shaft

@pre
* __Required quantity:__ 1pcs
* __Color:__ \emoji :yellow_circle: Yellow
* __Recommended material:__ PLA
* __Material, that I have used:__ [Prusament PLA Pineapple Yellow 1kg](https://www.prusa3d.com/product/prusament-pla-pineapple-yellow-1kg/)
* __Required filament:__ 1.51g
* __Estimated print time:__ 9m
* __File for Prusa Slicer:__ <a href="eccetric_shaft_1pcs.3mf" target="_blank"><b>eccetric_shaft_1pcs.3mf</b></a>
* __File for other slicers:__ <a href="eccetric_shaft_1pcs.stl" target="_blank"><b>eccetric_shaft_1pcs.stl</b></a>

@subsection endstop_knob Endstop Knob

Endstop Knob

@pre
* __Required quantity:__ 2pcs
* __Color:__ \emoji :yellow_circle: Yellow
* __Recommended material:__ PLA
* __Material, that I have used:__ [Prusament PLA Pineapple Yellow 1kg](https://www.prusa3d.com/product/prusament-pla-pineapple-yellow-1kg/)
* __Required filament:__ 1.03g
* __Estimated print time:__ 14m
* __File for Prusa Slicer:__ <a href="endstop_knob_2pcs.3mf" target="_blank"><b>endstop_knob_2pcs.3mf</b></a>
* __File for other slicers:__ <a href="endstop_knob_2pcs.stl" target="_blank"><b>endstop_knob_2pcs.stl</b></a>

@subsection magnet_holder Magnet Holder

Magnet Holder

@pre
* __Required quantity:__ 1pcs
* __Color:__ \emoji :yellow_circle: Yellow
* __Recommended material:__ PLA
* __Material, that I have used:__ [Prusament PLA Pineapple Yellow 1kg](https://www.prusa3d.com/product/prusament-pla-pineapple-yellow-1kg/)
* __Required filament:__ 0.83g
* __Estimated print time:__ 7m
* __File for Prusa Slicer:__ <a href="front_panel_magnet_holder_1pcs.3mf" target="_blank"><b>front_panel_magnet_holder_1pcs.3mf</b></a>
* __File for other slicers:__ <a href="front_panel_magnet_holder_1pcs.stl" target="_blank"><b>front_panel_magnet_holder_1pcs.stl</b></a>

@subsection led_ring_mount LED Ring Mount

LED Ring Mount

@pre
* __Required quantity:__ 1pcs
* __Color:__ \emoji :yellow_circle: Yellow
* __Recommended material:__ PLA
* __Material, that I have used:__ [Prusament PLA Pineapple Yellow 1kg](https://www.prusa3d.com/product/prusament-pla-pineapple-yellow-1kg/)
* __Required filament:__ 1.01g
* __Estimated print time:__ 12m
* __File for Prusa Slicer:__ <a href="led_ring_mount_1pcs.3mf" target="_blank"><b>led_ring_mount_1pcs.3mf</b></a>
* __File for other slicers:__ <a href="led_ring_mount_1pcs.stl" target="_blank"><b>led_ring_mount_1pcs.stl</b></a>

@subsection left_endstop_mount Left Endstop Mount

Left Endstop Mount

@pre
* __Required quantity:__ 1pcs
* __Color:__ \emoji :yellow_circle: Yellow
* __Recommended material:__ PLA
* __Material, that I have used:__ [Prusament PLA Pineapple Yellow 1kg](https://www.prusa3d.com/product/prusament-pla-pineapple-yellow-1kg/)
* __Required filament:__ 5.67g
* __Estimated print time:__ 42m
* __File for Prusa Slicer:__ <a href="left_endstop_mount_1pcs.3mf" target="_blank"><b>left_endstop_mount_1pcs.3mf</b></a>
* __File for other slicers:__ <a href="left_endstop_mount_1pcs.stl" target="_blank"><b>left_endstop_mount_1pcs.stl</b></a>

@subsection right_endstop_mount Right Endstop Mount

Right Endstop Mount

@pre
* __Required quantity:__ 1pcs
* __Color:__ \emoji :yellow_circle: Yellow
* __Recommended material:__ PLA
* __Material, that I have used:__ [Prusament PLA Pineapple Yellow 1kg](https://www.prusa3d.com/product/prusament-pla-pineapple-yellow-1kg/)
* __Required filament:__ 5.16g
* __Estimated print time:__ 38m
* __File for Prusa Slicer:__ <a href="right_endstop_mount_1pcs.3mf" target="_blank"><b>right_endstop_mount_1pcs.3mf</b></a>
* __File for other slicers:__ <a href="right_endstop_mount_1pcs.stl" target="_blank"><b>right_endstop_mount_1pcs.stl</b></a>

@subsection long_screw_spacer Long Screw Spacer

Long Screw Spacer

@pre
* __Required quantity:__ 1pcs
* __Color:__ \emoji :yellow_circle: Yellow
* __Recommended material:__ PLA
* __Material, that I have used:__ [Prusament PLA Pineapple Yellow 1kg](https://www.prusa3d.com/product/prusament-pla-pineapple-yellow-1kg/)
* __Required filament:__ 0.2g
* __Estimated print time:__ 2m
* __File for Prusa Slicer:__ <a href="long_screw_spacer_1pcs.3mf" target="_blank"><b>long_screw_spacer_1pcs.3mf</b></a>
* __File for other slicers:__ <a href="long_screw_spacer_1pcs.stl" target="_blank"><b>long_screw_spacer_1pcs.stl</b></a>

@subsection short_screw_spacer Short Screw Spacer

Short Screw Spacer

@pre
* __Required quantity:__ 1pcs
* __Color:__ \emoji :yellow_circle: Yellow
* __Recommended material:__ PLA
* __Material, that I have used:__ [Prusament PLA Pineapple Yellow 1kg](https://www.prusa3d.com/product/prusament-pla-pineapple-yellow-1kg/)
* __Required filament:__ 0.15g
* __Estimated print time:__ 2m
* __File for Prusa Slicer:__ <a href="short_screw_spacer_1pcs.3mf" target="_blank"><b>short_screw_spacer_1pcs.3mf</b></a>
* __File for other slicers:__ <a href="short_screw_spacer_1pcs.stl" target="_blank"><b>short_screw_spacer_1pcs.stl</b></a>

@subsection moving_platform Moving Platform

Moving Platform

@pre
* __Required quantity:__ 1pcs
* __Color:__ \emoji :yellow_circle: Yellow
* __Recommended material:__ PLA
* __Material, that I have used:__ [Prusament PLA Pineapple Yellow 1kg](https://www.prusa3d.com/product/prusament-pla-pineapple-yellow-1kg/)
* __Required filament:__ 24.79g
* __Estimated print time:__ 3h 11m
* __File for Prusa Slicer:__ <a href="moving_platform_1pcs.3mf" target="_blank"><b>moving_platform_1pcs.3mf</b></a>
* __File for other slicers:__ <a href="moving_platform_1pcs.stl" target="_blank"><b>moving_platform_1pcs.stl</b></a>

@subsection pcb_spacer PCB Spacer

PCB Spacer

@pre
* __Required quantity:__ 1pcs
* __Color:__ \emoji :yellow_circle: Yellow
* __Recommended material:__ PLA
* __Material, that I have used:__ [Prusament PLA Pineapple Yellow 1kg](https://www.prusa3d.com/product/prusament-pla-pineapple-yellow-1kg/)
* __Required filament:__ 0.28g
* __Estimated print time:__ 4m
* __File for Prusa Slicer:__ <a href="pcb_spacer_corner_1pcs.3mf" target="_blank"><b>pcb_spacer_corner_1pcs.3mf</b></a>
* __File for other slicers:__ <a href="pcb_spacer_corner_1pcs.stl" target="_blank"><b>pcb_spacer_corner_1pcs.stl</b></a>

@subsection atomizer_socket Atomizer Socket

Atomizer Socket

@pre
* __Required quantity:__ 1pcs
* __Color:__ \emoji :large_blue_circle: Blue
* __Recommended material:__ PETG
* __Material, that I have used:__ [Prusament PETG Chalky Blue](https://www.prusa3d.com/product/prusament-petg-chalky-blue-1kg/)
* __Required filament:__ 15.07g
* __Estimated print time:__ 2h 33m
* __File for Prusa Slicer:__ <a href="azomizer_socket_1pcs_PETG.3mf" target="_blank"><b>azomizer_socket_1pcs_PETG.3mf</b></a>
* __File for other slicers:__ <a href="azomizer_socket_1pcs_PETG.stl" target="_blank"><b>azomizer_socket_1pcs_PETG.stl</b></a>

@subsection box_bottom Box Bottom

Box Bottom

@pre
* __Required quantity:__ 1pcs
* __Color:__ \emoji :black_circle: Black
* __Recommended material:__ PLA
* __Material, that I have used:__ [Prusament PLA Prusa Galaxy Black](https://www.prusa3d.com/product/prusament-pla-prusa-galaxy-black-1kg/)
* __Required filament:__ 162.55g
* __Estimated print time:__ 12h 45m
* __File for Prusa Slicer:__ <a href="box_bottom_1pcs.3mf" target="_blank"><b>box_bottom_1pcs.3mf</b></a>
* __File for other slicers:__ <a href="box_bottom_1pcs.stl" target="_blank"><b>box_bottom_1pcs.stl</b></a>

@subsection display_holder_base Display Holder Base

Display Holder Base

@pre
* __Required quantity:__ 1pcs
* __Color:__ \emoji :black_circle: Black
* __Recommended material:__ PLA
* __Material, that I have used:__ [Prusament PLA Prusa Galaxy Black](https://www.prusa3d.com/product/prusament-pla-prusa-galaxy-black-1kg/)
* __Required filament:__ 9.55g
* __Estimated print time:__ 1h 30m
* __File for Prusa Slicer:__ <a href="display_holder_base_with_art_1pcs.3mf" target="_blank"><b>display_holder_base_with_art_1pcs.3mf</b></a>
* __File for other slicers:__ <a href="display_holder_base_with_art_1pcs.stl" target="_blank"><b>display_holder_base_with_art_1pcs.stl</b></a>

@subsection led_holder LED Holder

LED Holder

@pre
* __Required quantity:__ 1pcs
* __Color:__ \emoji :white_circle: White
* __Recommended material:__ PLA
* __Material, that I have used:__ [Prusament PLA Vanilla White 1kg](https://www.prusa3d.com/product/prusament-pla-vanilla-white-1kg/)
* __Required filament:__ 91.19g
* __Estimated print time:__ 11h 29m
* __File for Prusa Slicer:__ <a href="led_holder_1pcs.3mf" target="_blank"><b>led_holder_1pcs.3mf</b></a>
* __File for other slicers:__ <a href="led_holder_1pcs.stl" target="_blank"><b>led_holder_1pcs.stl</b></a>

@subsection skull Skull

Skull

@note This model needs some support in the teeth area. I used __Paint On Support__
function in Prusa Slicer and it worked like a charm.

Skull Support

@pre
* __Required quantity:__ 1pcs
* __Color:__ \emoji :white_circle: White
* __Recommended material:__ PLA
* __Material, that I have used:__ [Prusament PLA Vanilla White 1kg](https://www.prusa3d.com/product/prusament-pla-vanilla-white-1kg/)
* __Required filament:__ 119.85g
* __Estimated print time:__ 20h 37m
* __File for Prusa Slicer:__ <a href="skull_1pcs.3mf" target="_blank"><b>skull_1pcs.3mf</b></a>
* __File for other slicers:__ <a href="skull_1pcs.stl" target="_blank"><b>skull_1pcs.stl</b></a>

@section advanced_parts Advanced Parts

Finally the tricky parts. These parts require color change during the printing.
With Prusa Slicer it is easy, I have added the color change commands to the settings.

@subsection box_front Box Front

Box Front

This part is made of three sections:
* The bottom one is black
* In the middle there is a special material, that is glow in the dark. This way the
pattern on the front panel is visible in low light conditions.
* The top section is black as well.

Box Front Layer Stackup

@pre
* __Required quantity:__ 1pcs
* __Base color:__ \emoji :black_circle: Black
* __Recommended material for base:__ PLA
* __Material, that I have used for base:__ [Prusament PLA Prusa Galaxy Black](https://www.prusa3d.com/product/prusament-pla-prusa-galaxy-black-1kg/)
* __Required filament for base:__ 29.14g
* __Parrern color:__ \emoji :green_circle: Glow in the dark green
* __Recommended material for pattern:__ PLA
* __Material, that I have used for pattern:__ [R3DA101G Glow in the dark green](https://www.3djake.hu/r3d/pla-glow-in-the-dark-green)
* __Required filament for pattern:__ 11.52g
* __Estimated print time:__ 4h 58m
* __File for Prusa Slicer:__ <a href="box_front_with_art_1pcs.3mf" target="_blank"><b>box_front_with_art_1pcs.3mf</b></a>
* __File for other slicers:__ <a href="box_front_with_art_1pcs.stl" target="_blank"><b>box_front_with_art_1pcs.stl</b></a>

@subsection box_top Box Top

Box Top

This part is made of two sections:
* The bottom one is white
* The top one is black

Box Top Layer Stackup

@pre
* __Required quantity:__ 1pcs
* __Pattern color:__ \emoji :black_circle: Black
* __Recommended material for pattern:__ PLA
* __Material, that I have used for pattern:__ [Prusament PLA Prusa Galaxy Black](https://www.prusa3d.com/product/prusament-pla-prusa-galaxy-black-1kg/)
* __Required filament for base:__ 50.71g
* __Base color:__ \emoji :white_circle: White
* __Recommended material for base:__ PLA
* __Material, that I have used for base:__ [Prusament PLA Vanilla White 1kg](https://www.prusa3d.com/product/prusament-pla-vanilla-white-1kg/)
* __Required filament for base:__ 15.4g
* __Estimated print time:__ 8h 46m
* __File for Prusa Slicer:__ <a href="box_top_with_art_1pcs.3mf" target="_blank"><b>box_top_with_art_1pcs.3mf</b></a>
* __File for other slicers:__ <a href="box_top_with_art_1pcs.stl" target="_blank"><b>box_top_with_art_1pcs.stl</b></a>

@subsection display_holder_front Display Holder Front

Display Holder Front

This part is made of two sections:
* The bottom one is special material, that is glow in the dark.
* The top one is black

Display Holder Front Layer Stackup

@pre
* __Required quantity:__ 1pcs
* __Pattern color:__ \emoji :black_circle: Black
* __Recommended material for pattern:__ PLA
* __Material, that I have used for pattern:__ [Prusament PLA Prusa Galaxy Black](https://www.prusa3d.com/product/prusament-pla-prusa-galaxy-black-1kg/)
* __Required filament for base:__ 0.15g
* __Base color:__ \emoji :green_circle: Glow in the dark green
* __Recommended material for base:__ PLA
* __Material, that I have used for base:__ [R3DA101G Glow in the dark green](https://www.3djake.hu/r3d/pla-glow-in-the-dark-green)
* __Required filament for base:__ 0.52g
* __Estimated print time:__ 8m
* __File for Prusa Slicer:__ <a href="display_holder_front_with_art_1pcs.3mf" target="_blank"><b>display_holder_front_with_art_1pcs.3mf</b></a>
* __File for other slicers:__ <a href="display_holder_front_with_art_1pcs.stl" target="_blank"><b>display_holder_front_with_art_1pcs.stl</b></a>

@subsection encoder_knob Encoder Knob

Encoder Knob

This part is made of three sections:
* Bottom one is black
* In the middle there is a special material, that is glow in the dark. This way the
pattern on the front panel is visible in low light conditions.
* The top section is black as well.

Encoder Knob Layer Stackup

@pre
* __Required quantity:__ 1pcs
* __Base color:__ \emoji :black_circle: Black
* __Recommended material for base:__ PLA
* __Material, that I have used for base:__ [Prusament PLA Prusa Galaxy Black](https://www.prusa3d.com/product/prusament-pla-prusa-galaxy-black-1kg/)
* __Required filament for base:__ 2.26g
* __Parrern color:__ \emoji :green_circle: Glow in the dark green
* __Recommended material for pattern:__ PLA
* __Material, that I have used for pattern:__ [R3DA101G Glow in the dark green](https://www.3djake.hu/r3d/pla-glow-in-the-dark-green)
* __Required filament for pattern:__ 0.54g
* __Estimated print time:__ 31m
* __File for Prusa Slicer:__ <a href="encoder_knob_with_art_1pcs.3mf" target="_blank"><b>encoder_knob_with_art_1pcs.3mf</b></a>
* __File for other slicers:__ <a href="encoder_knob_with_art_1pcs.stl" target="_blank"><b>encoder_knob_with_art_1pcs.stl</b></a>

@section custom_artwork Custom Artwork

If you don't like the artwork on the box or if you want to replace it with your own,
there is an option for that as well. There are those components without artwork:
* <a href="box_front_naked_1pcs.stl" target="_blank"><b>box_front_naked_1pcs.stl</b></a>
* <a href="box_top_naked_1pcs.stl" target="_blank"><b>box_top_naked_1pcs.stl</b></a>
* <a href="display_holder_naked_1pcs.stl" target="_blank"><b>display_holder_naked_1pcs.stl</b></a>
* <a href="encoder_knob_naked_1pcs.stl" target="_blank"><b>encoder_knob_naked_1pcs.stl</b></a>

I used [Blender](https://www.blender.org/) and its __Boolean__ feature to embed
the artwork into the models. The easiest way is to:
1. Create an __SVG__ file from the art bitmap( or use SVG from the beginning ) and import it to Blender.
2. Create a 3D mesh from the imported path.
3. Place the mesh to the component where you want to use it. The two mesh has to intersect.
4. Apply the __Boolean Modifier__.

There is a video about the subject.

\htmlonly

<iframe width="1024" height="786" src="https://www.youtube.com/embed/_S3D8djM5bE" title="YouTube video player" frameborder="0" allow="accelerometer; autoplay; clipboard-write; encrypted-media; gyroscope; picture-in-picture" allowfullscreen></iframe>

\endhtmlonly

@section skull_replacement Skull Replacement

I think the base section of the model( without artwork ) can be used to create awesome lamps.
For this reason, the top part( in this case the skull ) is easily replaceable with anything.
It is secured by only two screws. You can put any model on the top instead of the skull. I think
it would be awesome with a stormtrooper helmet for example.

Top Dimensions

<a href="top_dimensions.svg" target="_blank"><b>Zoom</b></a> \emoji :mag_right:

You can find the exact dimensions of the slots and the screws on the drawing above.

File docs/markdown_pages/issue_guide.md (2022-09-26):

@page issue_guide Issue Guide

@section new_issue New Issue

If you find an issue with this project, this page shows, how to report it.
Firstly you have to create a __new issue__.

New Issue

__There are five main issue categories.__

Issue Categories

🐛 [Bug report](https://github.com/dani007200964/Viking-Skull-Lamp/issues/new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) -
This category is created for software-related problems. For
example, if you find some strange or unwanted behavior in the firmware, this is the
right category to report it.

⚡ [Circuit problem](https://github.com/dani007200964/Viking-Skull-Lamp/issues/new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) -
This category is created for circuit-related problems.
For example, if you build the PCB and something does not work. Or if you find a problem
with the layout or in the schematics.

📜 [Documentation problem](https://github.com/dani007200964/Viking-Skull-Lamp/issues/new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) -
This category is created for documentation-related
problems. For example, if you find a wrong part number, quantity, or parameter. Or if
some comment in the code is wrong. Or if a section is doesn't understandable.

🚀 [Feature request](https://github.com/dani007200964/Viking-Skull-Lamp/issues/new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) -
If you have a new idea, you can share it with this template.

🛠️ [Mechanical problem](https://github.com/dani007200964/Viking-Skull-Lamp/issues/new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) -
This category is created for mechanical-related problems.
For example, some parts are worn quickly. Or you can not reproduce it, because it's
too complex. Also if you have a different printer than mine and it can't make a part
as precise as needed, please report it, maybe it can be modified to make it good for
everyone.

@section issue_example Issue Example

Issue Example

If you report an issue, please describe it as much as possible. If you have any idea
how to solve it please describe your solution as well.

@section discussion_section Discussion Section

Discussions

This section can be useful for people, who started to use GitHub recently. This is a very
intuitive and simple way to share your ideas and ask questions. Also if you made this thing
you can share it with others. Also if you modified or remixed it, please share it with the
community( I hope someone will make a stormtrooper helmet version \emoji :eyes: ).

@section pull_request Pull Request

If you solved a problem, or you made some change in the project and you want to share
it, you can create a [pull request](https://www.youtube.com/watch?v=8lGpZkjnkt4).
This way you can contribute to this project.

@note If you never made a pull request before, you can find a lot of tutorials on
the web. It is not that hard, and actually, there are a ton of graphical tools to use
git, so you don't have to use the command line.

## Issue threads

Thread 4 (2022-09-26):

TODO for V1

dani007200964, 2022-09-26:
Before publication:
- [x] Check links in the documentation
- [x] Create a YouTube description
- [x] Upload the files to Printables
- [x] Grammar check
- [x] Fix video orientations
- [x] Document the rest of the code
- [x] Readme
- [x] Model material fix
- [x] Documentation link in readme

After publication:
- [x] Readme documentation link.
- [x] Printables documentation link
- [x] Youtube documentation link
- [x] Check badge on software section

Closed 2022-10-16.

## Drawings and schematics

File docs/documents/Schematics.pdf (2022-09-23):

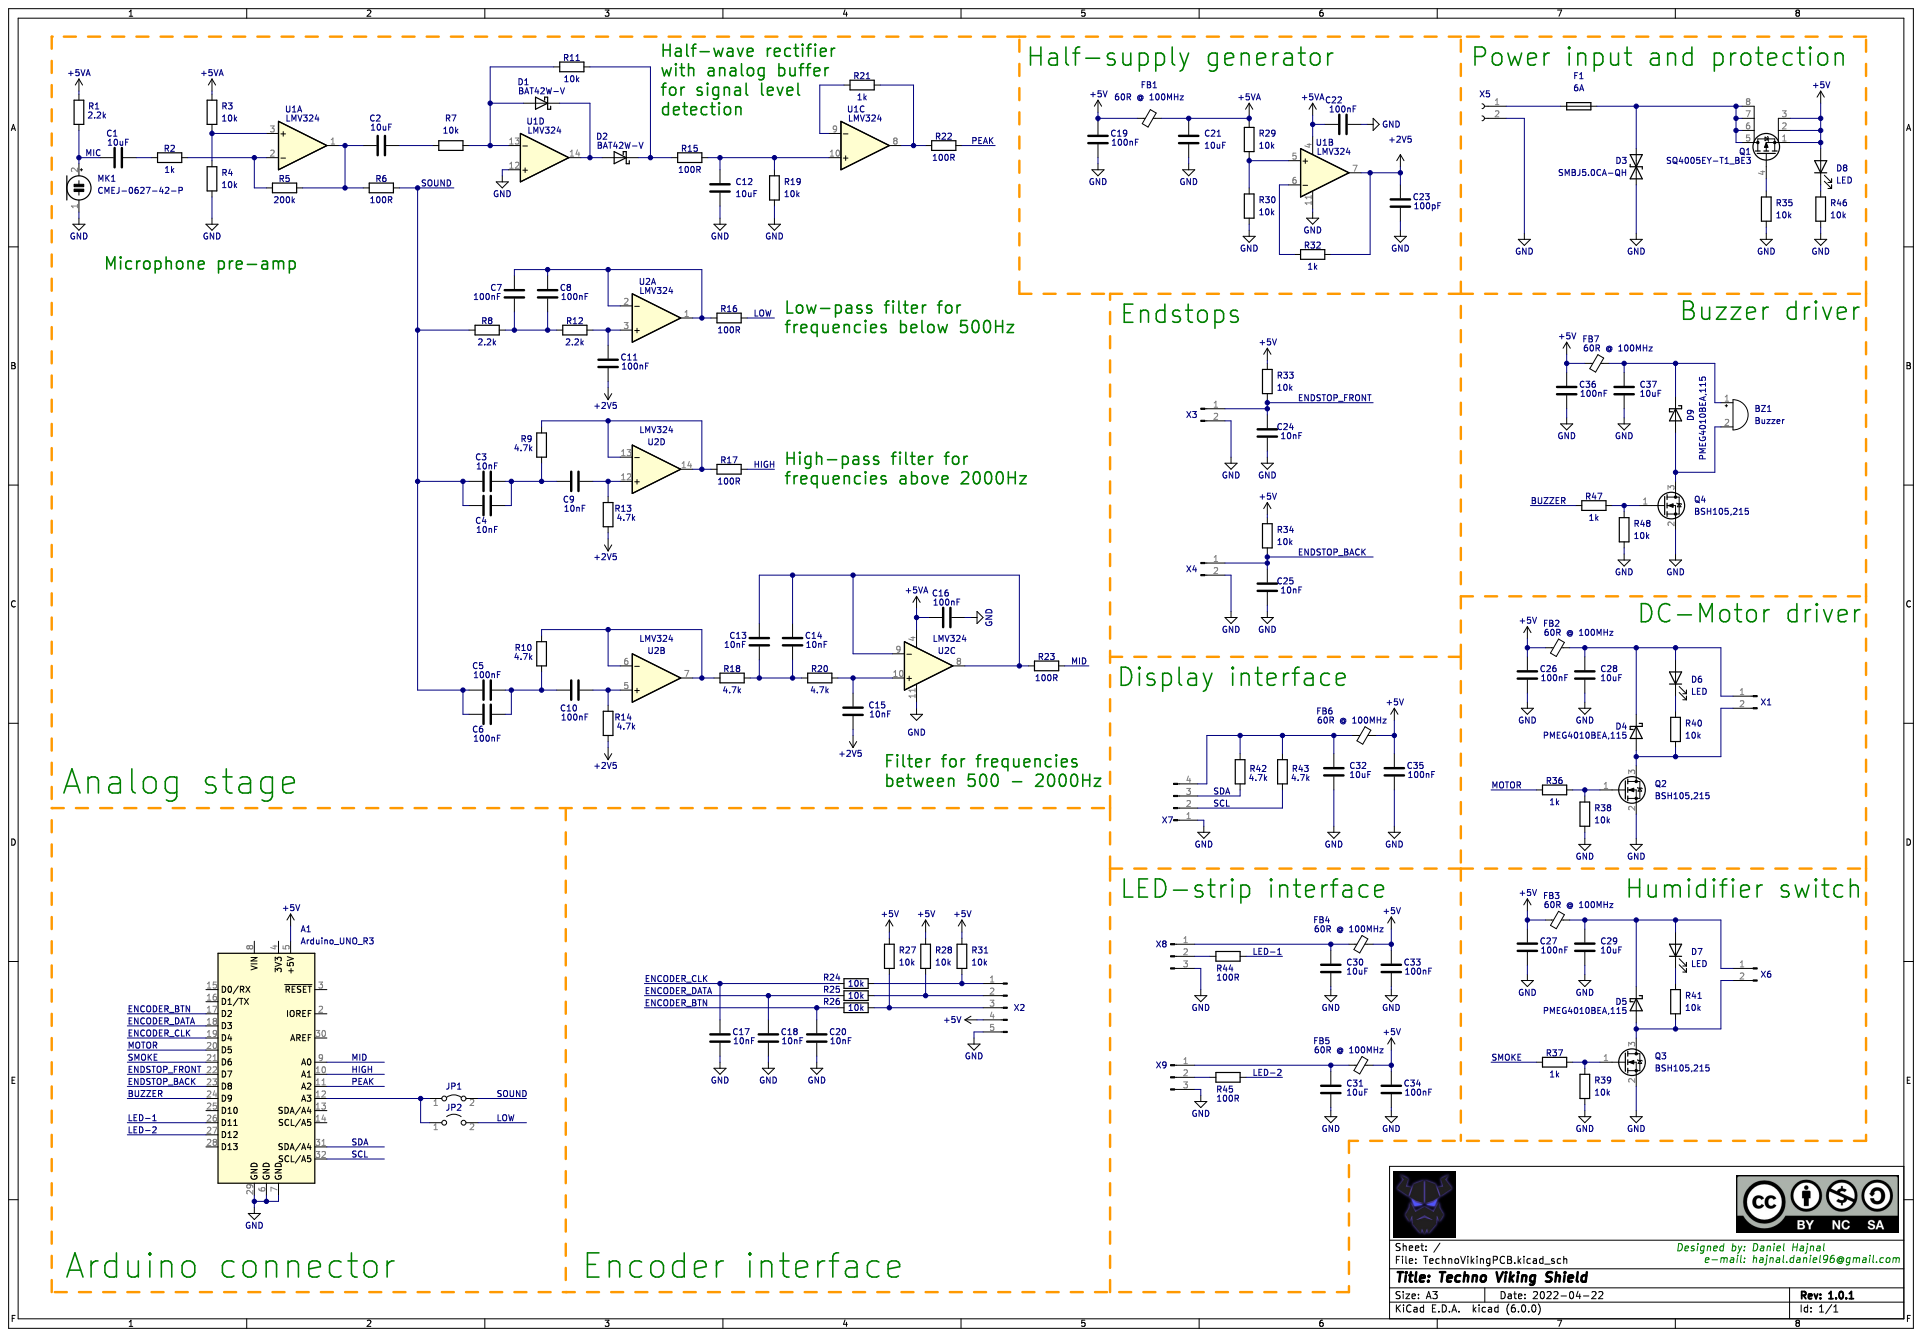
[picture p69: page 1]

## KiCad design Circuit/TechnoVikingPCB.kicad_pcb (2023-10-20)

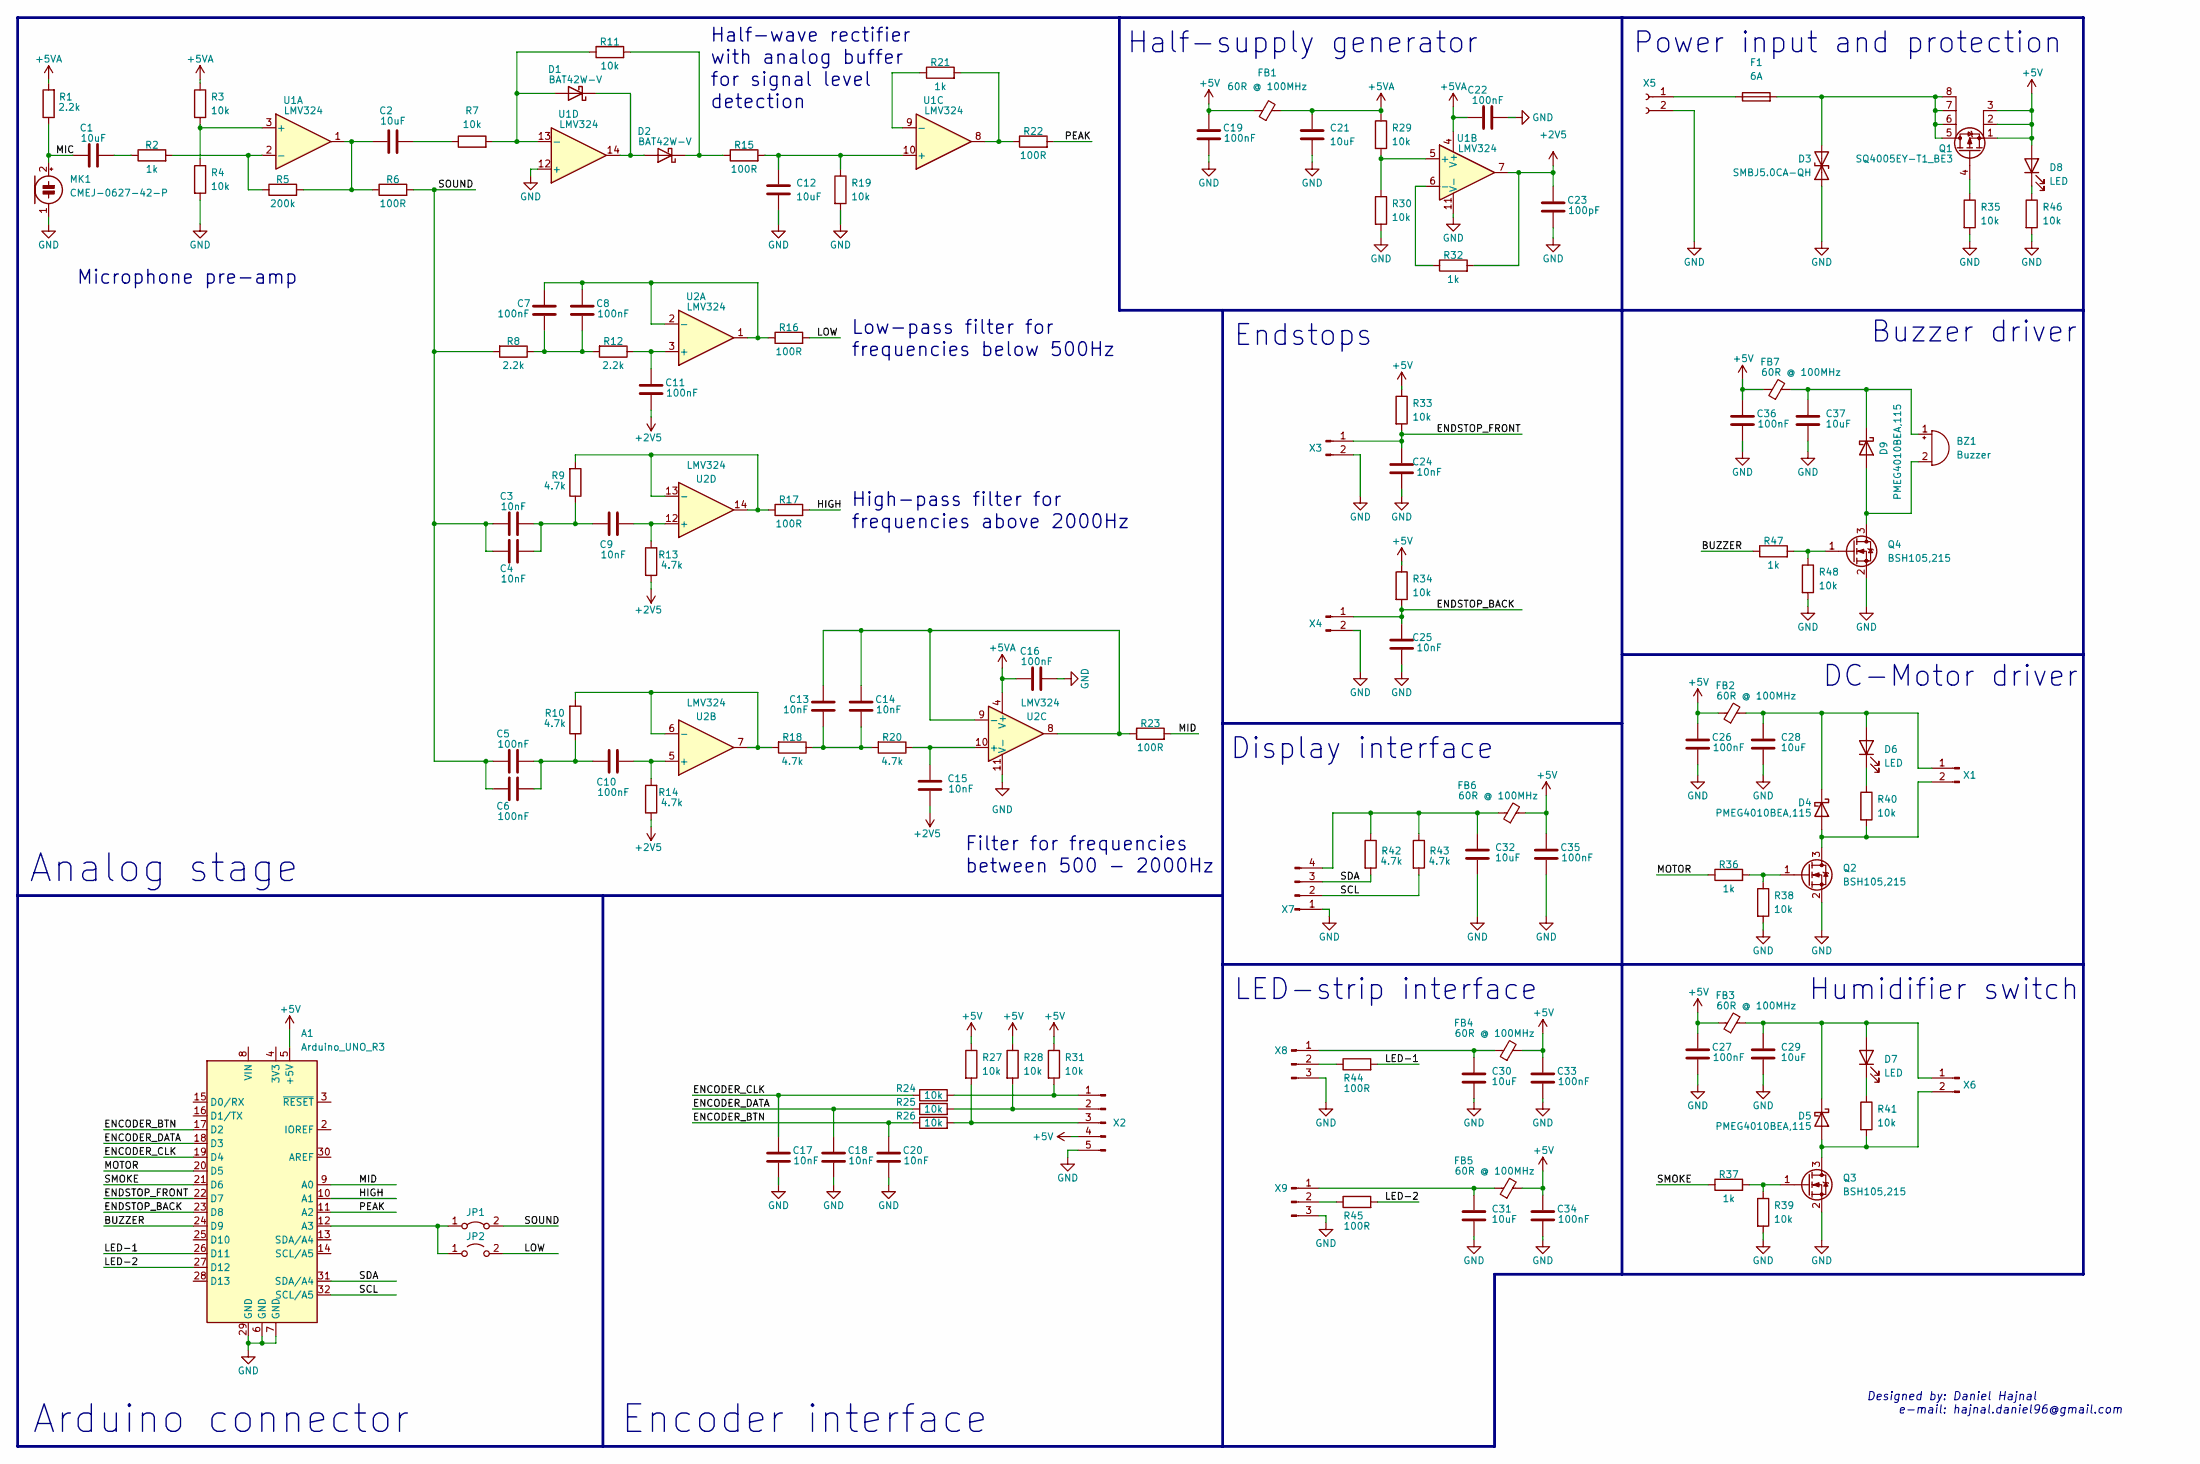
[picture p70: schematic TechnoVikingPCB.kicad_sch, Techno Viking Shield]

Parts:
A1: Arduino_UNO_R3; Arduino_R3_Extended; MPN 61304011121
BZ1: Buzzer; MagneticBuzzer_PUI_AT-0927-TT-6-R; MPN AT-0927-TT-6-R
C1, C2, C12, C21, C28, C29, C30, C31, C32, C37: 10uF; R_0805_2012Metric_Pad1.20x1.40mm_HandSolder; MPN GRM21BR61C106KE15K
C3, C4, C9, C13, C14, C15, C17, C18, C20, C24, C25: 10nF; R_0603_1608Metric_Pad0.98x0.95mm_HandSolder; MPN CC0603KRX7R7BB103
C5, C6, C7, C8, C10, C11, C16, C19, C22, C26, C27, C33, C34, C35, C36: 100nF; R_0603_1608Metric_Pad0.98x0.95mm_HandSolder; MPN CC0603JRX7R7BB104
C23: 100pF; R_0603_1608Metric_Pad0.98x0.95mm_HandSolder; MPN CC0603KRX7R7BB101
D1, D2: BAT42W-V; D_SOD-123; MPN BAT42W-G3-08
D3: SMBJ5.0CA-QH; D_SMB_Handsoldering; MPN SMBJ5.0CA-QH
D4, D5, D9: PMEG4010BEA,115; D_SOD-323_HandSoldering; MPN PMEG4010BEA,115
D6, D7: LED; LED_0603_1608Metric_Pad1.05x0.95mm_HandSolder; MPN APT1608SYC/J3-AMT
D8: LED; LED_0603_1608Metric_Pad1.05x0.95mm_HandSolder; MPN APT1608ZGC-AMT
F1: 6A; Fuse_1206_3216Metric_Pad1.42x1.75mm_HandSolder; MPN 0685P6000-01
FB1, FB2, FB3, FB4, FB5, FB6, FB7: 60R @ 100MHz; L_0603_1608Metric_Pad1.05x0.95mm_HandSolder; MPN BLM18PG600SZ1D
JP1: Jumper_2_Bridged; SolderJumper-2_P1.3mm_Bridged_Pad1.0x1.5mm
JP2: Jumper_2_Open; SolderJumper-2_P1.3mm_Open_Pad1.0x1.5mm
MK1: CMEJ-0627-42-P; Mic 6mm; MPN CMEJ-0627-42-P
Q1: SQ4005EY-T1_BE3; SO-8_3.9x4.9mm_P1.27mm; MPN SQ4005EY-T1_BE3
Q2, Q3, Q4: BSH105,215; SOT-23; MPN BSH105,215
R1, R8, R12: 2.2k; R_0603_1608Metric_Pad0.98x0.95mm_HandSolder; MPN CRCW06032K20FKEAC
R2, R21, R32, R36, R37, R47: 1k; R_0603_1608Metric_Pad0.98x0.95mm_HandSolder; MPN CRCW06031K00JNEC
R3, R4, R7, R11, R19, R24, R25, R26, R27, R28, R29, R30, R31, R33, R34, R35, R38, R39, R40, R41, R46, R48: 10k; R_0603_1608Metric_Pad0.98x0.95mm_HandSolder; MPN RCG060310K0FKEA
R5: 200k; R_0603_1608Metric_Pad0.98x0.95mm_HandSolder; MPN CRCW0603200KFKEAC
R6, R15, R16, R17, R22, R23, R44, R45: 100R; R_0603_1608Metric_Pad0.98x0.95mm_HandSolder; MPN CRCW0603100RJNEAC
R9, R10, R13, R14, R18, R20, R42, R43: 4.7k; R_0603_1608Metric_Pad0.98x0.95mm_HandSolder; MPN CRCW06034K70JNEC
U1, U2: LMV324; SOIC-14_3.9x8.7mm_P1.27mm; MPN LMV324IDR
X1, X3, X4, X6: Conn_01x02_Male; JST_PH_S2B-PH-K_1x02_P2.00mm_Horizontal; MPN S2B-PH-K-S (LF)(SN)
X2: Conn_01x05_Male; JST_PH_S5B-PH-K_1x05_P2.00mm_Horizontal; MPN S5B-PH-K-S (LF)(SN)
X5: Conn_01x02_Female; TerminalBlock_4Ucon_1x02_P3.50mm_Horizontal; MPN 39357-0002
X7: Conn_01x04_Male; JST_PH_S4B-PH-K_1x04_P2.00mm_Horizontal; MPN S4B-PH-K-S (LF)(SN)
X8, X9: Conn_01x03_Male; JST_PH_B3B-PH-K_1x03_P2.00mm_Vertical; MPN B3B-PH-K-S(LF)(SN)

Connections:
+2V5: C11.1, C15.1, C23.1, R13.1, R14.1, R32.2, U1.7
+5V: A1.5 (+5V), C19.2, C26.2, C27.2, C33.2, C34.2, C35.2, C36.2, D8.2 (A), FB1.1, FB2.1, FB3.1, FB4.2, FB5.2, FB6.2, FB7.1, Q1.1 (S), Q1.2 (S), Q1.3 (S), R27.1, R28.1, R31.1, R33.1, R34.1, X2.4
+5VA: C16.1, C21.2, C22.1, FB1.2, R1.2, R3.1, R29.1, U1.4 (V+), U2.4 (V+)
/BUZZER: A1.24 (D9), R47.1
/ENCODER_BTN: A1.17 (D2), C20.1, R26.1
/ENCODER_CLK: A1.19 (D4), C17.1, R24.1
/ENCODER_DATA: A1.18 (D3), C18.1, R25.1
/ENDSTOP_BACK: A1.23 (D8), C25.1, R34.2, X4.1
/ENDSTOP_FRONT: A1.22 (D7), C24.1, R33.2, X3.1
/HIGH: A1.10 (A1), R17.2
/LED-1: A1.26 (D11), R44.2
/LED-2: A1.27 (D12), R45.2
/LOW: JP2.2 (B), R16.2
/MIC: C1.1, MK1.2 (+), R1.1
/MID: A1.9 (A0), R23.2
/MOTOR: A1.20 (D5), R36.1
/PEAK: A1.11 (A2), R22.2
/SCL: A1.32 (SCL/A5), R43.2, X7.2
/SDA: A1.31 (SDA/A4), R42.2, X7.3
/SMOKE: A1.21 (D6), R37.1
/SOUND: C3.2, C4.2, C5.2, C6.2, JP1.2 (B), R6.2, R8.2
GND: A1.6 (GND), A1.7 (GND), A1.29 (GND), C12.1, C16.2, C17.2, C18.2, C19.1, C20.2, C21.1, C22.2, C23.2, C24.2, C25.2, C26.1, C27.1, C28.1, C29.1, C30.1, C31.1, C32.1, C33.1, C34.1, C35.1, C36.1, C37.1, D3.1 (A1), MK1.1 (-), Q2.2 (S), Q3.2 (S), Q4.2 (S), R4.2, R19.2, R30.2, R35.2, R38.2, R39.2, R46.2, R48.2, U1.11 (V-), U1.12 (+), U2.11 (V-), X2.5, X3.2, X4.2, X5.2, X7.1, X8.3, X9.3
unnamed: A1.12 (A3), JP1.1 (A), JP2.1 (A)
unnamed: BZ1.1 (-), C37.2, D9.1 (K), FB7.2
unnamed: BZ1.2 (+), D9.2 (A), Q4.3 (D)
unnamed: C1.2, R2.1
unnamed: C2.1, R5.2, R6.1, U1.1
unnamed: C2.2, R7.1
unnamed: C3.1, C4.1, C9.2, R9.1
unnamed: C7.1, C8.1, R8.1, R12.2
unnamed: C7.2, C8.2, R16.1, U2.1, U2.2 (-)
unnamed: C9.1, R13.2, U2.12 (+)
unnamed: C10.1, R14.2, U2.5 (+)
unnamed: C5.1, C6.1, C10.2, R10.1
unnamed: C11.2, R12.1, U2.3 (+)
unnamed: C12.2, R15.2, R19.1, U1.10 (+)
unnamed: C13.1, C14.1, R18.1, R20.2
unnamed: C13.2, C14.2, R23.1, U2.8, U2.9 (-)
unnamed: C15.2, R20.1, U2.10 (+)
unnamed: C28.2, D4.1 (K), D6.2 (A), FB2.2, X1.1
unnamed: C29.2, D5.1 (K), D7.2 (A), FB3.2, X6.1
unnamed: C30.2, FB4.1, X8.1
unnamed: C31.2, FB5.1, X9.1
unnamed: C32.2, FB6.1, R42.1, R43.1, X7.4
unnamed: D1.1 (K), D2.2 (A), U1.14
unnamed: D1.2 (A), R7.2, R11.1, U1.13 (-)
unnamed: D2.1 (K), R11.2, R15.1
unnamed: D3.2 (A2), F1.2, Q1.5 (D), Q1.6 (D), Q1.7 (D), Q1.8 (D)
unnamed: D4.2 (A), Q2.3 (D), R40.2, X1.2
unnamed: D5.2 (A), Q3.3 (D), R41.2, X6.2
unnamed: D6.1 (K), R40.1
unnamed: D7.1 (K), R41.1
unnamed: D8.1 (K), R46.1
unnamed: F1.1, X5.1
unnamed: Q1.4 (G), R35.1
unnamed: Q2.1 (G), R36.2, R38.1
unnamed: Q3.1 (G), R37.2, R39.1
unnamed: Q4.1 (G), R47.2, R48.1
unnamed: R2.2, R5.1, U1.2 (-)
unnamed: R3.2, R4.1, U1.3 (+)
unnamed: R10.2, R18.2, U2.6 (-), U2.7
unnamed: R9.2, R17.1, U2.13 (-), U2.14
unnamed: R21.1, U1.9 (-)
unnamed: R21.2, R22.1, U1.8
unnamed: R24.2, R31.2, X2.1
unnamed: R25.2, R28.2, X2.2
unnamed: R26.2, R27.2, X2.3
unnamed: R29.2, R30.1, U1.5 (+)
unnamed: R32.1, U1.6 (-)
unnamed: R44.1, X8.2
unnamed: R45.1, X9.2

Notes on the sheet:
High-pass filter for frequencies above 2000Hz
Half-supply generator
Arduino connector
Encoder interface
Filter for frequencies between 500 - 2000Hz
Endstops
LED-strip interface
Low-pass filter for frequencies below 500Hz
Display interface
Power input and protection
Buzzer driver
Designed by: Daniel Hajnal e-mail: hajnal.daniel96@gmail.com
Analog stage
Humidifier switch
Half-wave rectifier with analog buffer for signal level detection
DC-Motor driver
Microphone pre-amp

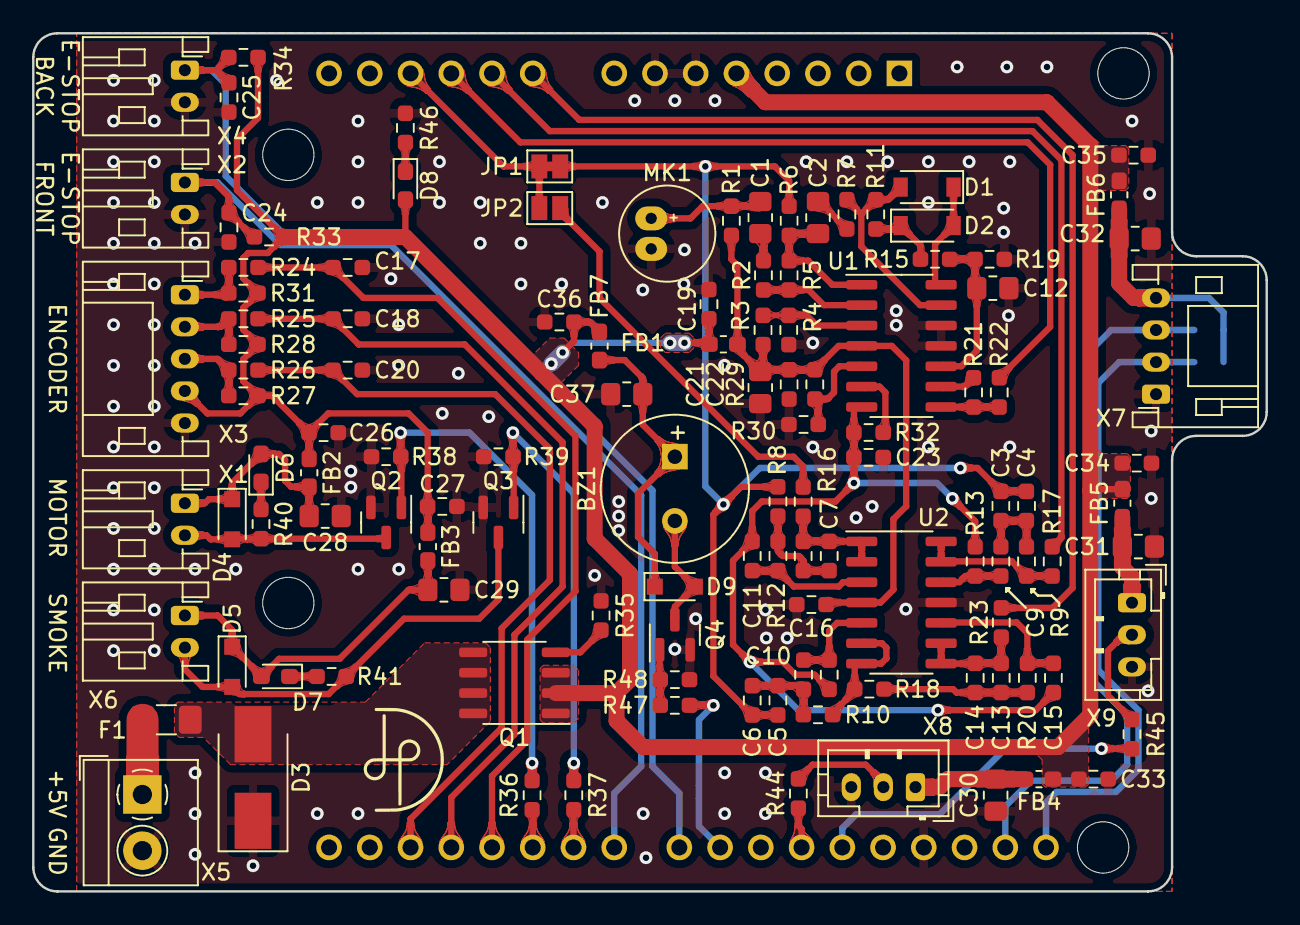
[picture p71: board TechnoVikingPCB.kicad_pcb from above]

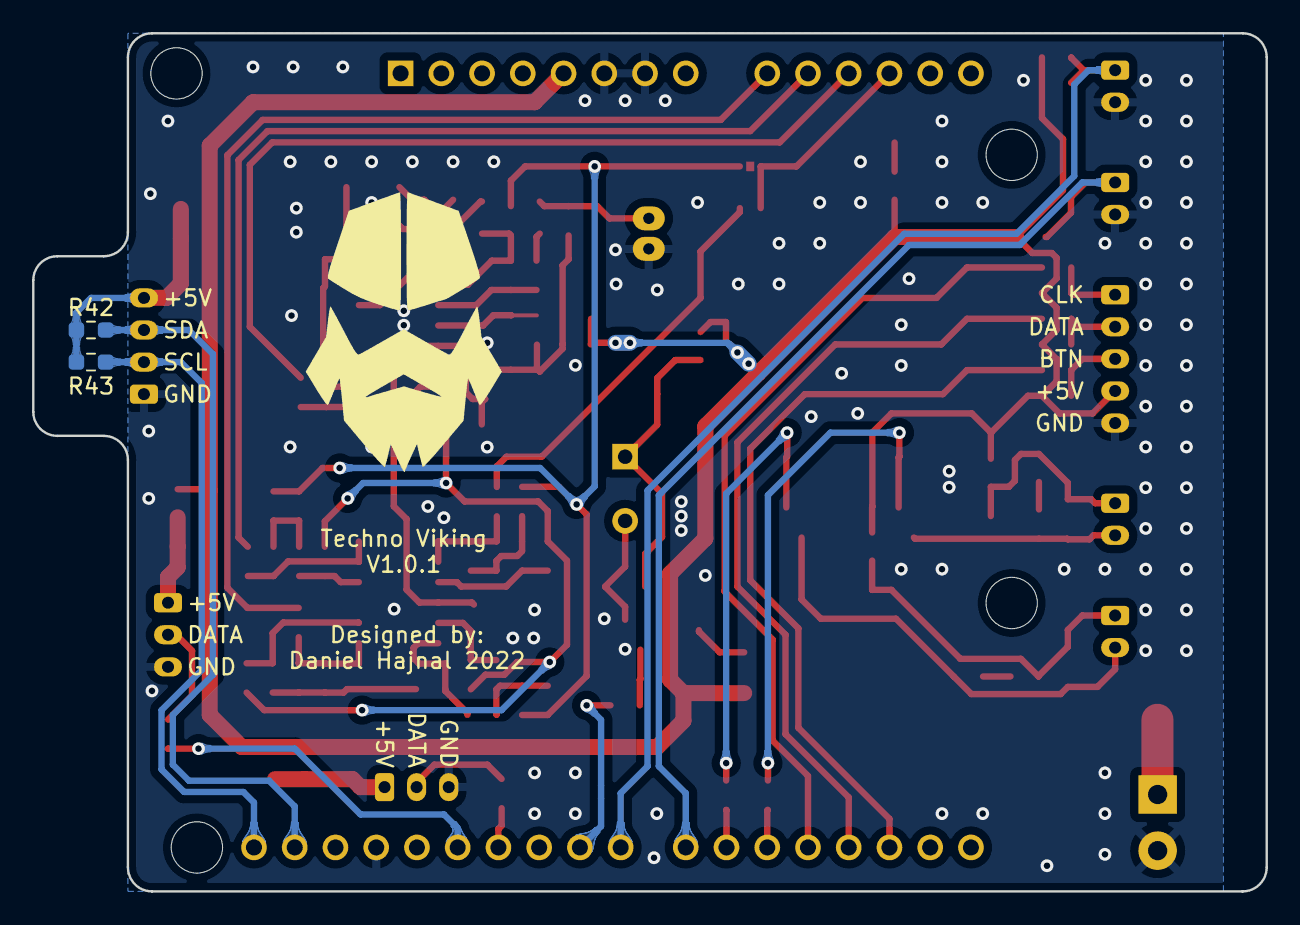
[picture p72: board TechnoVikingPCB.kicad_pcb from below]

Board: 2 copper layers, 76.9 x 53.5 mm, 122 parts (3 on the bottom side), 71 nets.

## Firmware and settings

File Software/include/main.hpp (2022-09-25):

/*
 * Created on May 28 2022
 *
 * Copyright (c) 2022 - Daniel Hajnal
 * hajnal.daniel96@gmail.com
 * This file is part of the Viking Skull Lamp project.
 * Modified 2022.06.27
*/

/*
MIT License
Copyright (c) 2022 Daniel Hajnal
Permission is hereby granted, free of charge, to any person obtaining a copy
of this software and associated documentation files (the "Software"), to deal
in the Software without restriction, including without limitation the rights
to use, copy, modify, merge, publish, distribute, sublicense, and/or sell
copies of the Software, and to permit persons to whom the Software is
furnished to do so, subject to the following conditions:
The above copyright notice and this permission notice shall be included in all
copies or substantial portions of the Software.
THE SOFTWARE IS PROVIDED "AS IS", WITHOUT WARRANTY OF ANY KIND, EXPRESS OR
IMPLIED, INCLUDING BUT NOT LIMITED TO THE WARRANTIES OF MERCHANTABILITY,
FITNESS FOR A PARTICULAR PURPOSE AND NONINFRINGEMENT. IN NO EVENT SHALL THE
AUTHORS OR COPYRIGHT HOLDERS BE LIABLE FOR ANY CLAIM, DAMAGES OR OTHER
LIABILITY, WHETHER IN AN ACTION OF CONTRACT, TORT OR OTHERWISE, ARISING FROM,
OUT OF OR IN CONNECTION WITH THE SOFTWARE OR THE USE OR OTHER DEALINGS IN THE
SOFTWARE.
*/

#ifndef MAIN_HPP__
#define MAIN_HPP__

#include "Arduino.h"
#include "globalResources.hpp"
#include "oled.hpp"
#include "menu.hpp"
#include "motorControl.hpp"
#include "lightControl.hpp"
#include "buzzerControl.hpp"
#include "configuration.hpp"
#include "fogMachine.hpp"
#include <avr/wdt.h>

/// The encoder button is connected to pin 2 on the Arduino.
#define ENCODER_BTN 2

/// The encoder data line is connected to pin 4 on the Arduino.
#define ENCODER_DATA 4

/// The encoder clock line is connected to pin 3 on the Arduino.
#define ENCODER_CLK 3

// The buzzer is connected to pin 9 on the Arduino.
#define BUZZER 9
/*
    ____       ____            ____     ______            _____      
   / __ \___  / __/___ ___  __/ / /_   / ____/___  ____  / __(_)___ _
  / / / / _ \/ /_/ __ `/ / / / / __/  / /   / __ \/ __ \/ /_/ / __ `/
 / /_/ /  __/ __/ /_/ / /_/ / / /_   / /___/ /_/ / / / / __/ / /_/ / 
/_____/\___/_/  \__,_/\__,_/_/\__/   \____/\____/_/ /_/_/ /_/\__, /  
                                                            /____/   

*/
//---- This section contains the default configuration for the first boot up ----//

/// Default value for the light mode.
#define DEFAULT_LIGHT_MODE          LIGHT_MODE_RAINBOW

/// Default value for the user selected color.
#define DEFAULT_SELECTED_COLOR      0

/// Default value for the brightness.
#define DEFAULT_LIGHT_BRIGHTNESS    30

/// By default the buzzer is enabled.
#define DEFAULT_BUZZER_STATE        true

/// By default the clap switch is enabled.
#define DEFAULT_CLAP_SWITCH_STATE   true

/// By default the fog machine is enabled.
#define DEFAULT_FOG_STATE           true

/// Interrupt service for the encoder rotation events.
void encoderISR();

/// This function handles the button press detection.
void encoderButtonUpdate();

#endif

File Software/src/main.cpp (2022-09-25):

/*
 * Created on May 28 2022
 *
 * Copyright (c) 2022 - Daniel Hajnal
 * hajnal.daniel96@gmail.com
 * This file is part of the Viking Skull Lamp project.
 * Modified 2022.06.27
*/

/*
MIT License
Copyright (c) 2022 Daniel Hajnal
Permission is hereby granted, free of charge, to any person obtaining a copy
of this software and associated documentation files (the "Software"), to deal
in the Software without restriction, including without limitation the rights
to use, copy, modify, merge, publish, distribute, sublicense, and/or sell
copies of the Software, and to permit persons to whom the Software is
furnished to do so, subject to the following conditions:
The above copyright notice and this permission notice shall be included in all
copies or substantial portions of the Software.
THE SOFTWARE IS PROVIDED "AS IS", WITHOUT WARRANTY OF ANY KIND, EXPRESS OR
IMPLIED, INCLUDING BUT NOT LIMITED TO THE WARRANTIES OF MERCHANTABILITY,
FITNESS FOR A PARTICULAR PURPOSE AND NONINFRINGEMENT. IN NO EVENT SHALL THE
AUTHORS OR COPYRIGHT HOLDERS BE LIABLE FOR ANY CLAIM, DAMAGES OR OTHER
LIABILITY, WHETHER IN AN ACTION OF CONTRACT, TORT OR OTHERWISE, ARISING FROM,
OUT OF OR IN CONNECTION WITH THE SOFTWARE OR THE USE OR OTHER DEALINGS IN THE
SOFTWARE.
*/

#include "main.hpp"

/// Object for the display.
///
/// This object can control a 128 x 32 pixel oled
/// display whisch have an SSD1306 display driver.
/// The address is configurable in the
/// @ref OLED_ADDRESS macro.
/// @see OLED_ADDRESS
ssd1306 display( OLED_ADDRESS );

/// Object for the menu.
///
/// This object handles all the logic behind the
/// menu system. It uses the @ref display object
/// as output and the default selected menu item
/// is @ref lightMenuItem
menu menuController( &display, &lightMenuItem );

/// This array contains all the variables,
/// that required for configuring the device
configurationManager::configurationData_t configTree[] = {

    createData( lightMode ),
    createData( selectedColor ),
    createData( lightBrightness ),
    createData( buzzerEnabled ),
    createData( clapSwitchEnabled ),
    createData( fogMachineEnabled )

};

/// Object for configuration saving and loading.
///
/// This object handles the saving and the loading 
/// loading of the configuration data. It uses the
/// @ref configTree array, which contains all the
/// configuration associated variables.
configurationManager config( configTree, ( sizeof( configTree ) / sizeof( configTree[0] ) ) );

/// Last system time when the button was pressed.
long lastButtonPress = 0;

/// Counts how many button press was detected in a period.
uint8_t buttonPressCntr = 0;

/// Flag for button press detection.
bool buttonPressed = false;

/// Device initialization section after reset.
void setup() {
  
    // Just in case we enable the watchdog with 4-sec timeout.
    wdt_enable( WDTO_4S );

    // Initialize the Serial port.
    Serial.begin( 115200 );

    // Try to load the configuration from the EEPROM.
    if( !config.loadConfig() ){

        // If the configuration loading is not succesful,
        // we set the config variables to the default values.
        lightMode = DEFAULT_LIGHT_MODE;
        selectedColor = DEFAULT_SELECTED_COLOR;
        lightBrightness = DEFAULT_LIGHT_BRIGHTNESS;
        buzzerEnabled = DEFAULT_BUZZER_STATE;
        clapSwitchEnabled = DEFAULT_CLAP_SWITCH_STATE;
        fogMachineEnabled = DEFAULT_FOG_STATE;

        // Also we try to save the config again.
        config.saveConfig();

    }

    // Try to initialize the oled display.
    if( !display.begin() ){

        // If we can't, we print the error.
        Serial.println( F( "Display Error!" ) );
        
    }

    // Initialize motor logic.
    motorInit();

    // Initialize encoder pins.
    pinMode( ENCODER_CLK, INPUT );
    pinMode( ENCODER_BTN, INPUT );
    pinMode( ENCODER_DATA, INPUT );

    // For encoder rotation detection we use an interrupt,
    // so we have to register that to the @ref ENCODER_CLK pin.
    // Every time a rising endge arrives ti @ref ENCODER_CLK pin,
    // the @ref encoderISR function will be called.
    attachInterrupt( digitalPinToInterrupt( ENCODER_CLK ), encoderISR, RISING );

    // Initialize menu system.
    menuInit();

    // Initialize lighting.
    lightInit();

    // Initialize the humidifier.
    fogMachineInit();
        
}

/// This is the infinite loop of
/// the code. Every periodic task
/// should be placed here.
void loop() {

    // Update menu data.
    menuController.draw();

    // Update button handler.
    encoderButtonUpdate();

    // Update lighting effects.
    lightUpdate();

    // Update the humidifier module.
    fogMachineUpdate();

    // Feed the watchdog.
    wdt_reset();

}

void encoderISR(){

    // We only allowed to use the menu,
    // when the front panel is opened.
    if( frontState != FRONT_OPEN ){

        return;

    }

    // We have to detect the direction of the rotation.
    // If we rotate it to one direction the state of the
    // data line and the clock line always be equal. If we
    // change direction they always be different.
    if( digitalRead( ENCODER_CLK ) == digitalRead( ENCODER_DATA ) ){

        menuController.up();
        encoderRotateSound();
        
    }

    else{

        menuController.down();
        encoderRotateSound();
        
    }
  
}

void encoderButtonUpdate(){

    // The encoder button uses inverted logic. If it is pressed
    // the output of the button will be low.
    if( digitalRead( ENCODER_BTN ) == 0 && !buttonPressed ){

        // A tiny delay required to debounce the signal.
        delay( 15 );

        // Increment the buttonPressCntr.
        buttonPressCntr++;

        // Save system time.
        lastButtonPress = millis();

        // Set the flag to true. It is required for event generation.
        buttonPressed = true;
    }

    // Check if the button was released.
    if( digitalRead( ENCODER_BTN ) == 1 ){

        // Reset the flag.
        buttonPressed = false;

    }

    // To detect multiple button presses we have to be quick. The time between
    // two button presses should be less than 250ms. Otherwise it will be detected
    // as a single press.
    if( ( ( millis() - lastButtonPress ) > 250 ) && buttonPressCntr ){

        // Decide action according to the number of the button pressed.
        switch( buttonPressCntr ){

            // Button pressed once.
            case 1:

                // If the front is opened we use the button to navigate
                // in the menu. Also we save the config with every button
                // press. If there are no changes in the configuration
                // data it will skip the writing anyway.
                if( frontState == FRONT_OPEN ){

                    menuController.next();
                    config.saveConfig();
                    buttonClickSound();

                }

                // If the front is closed we use the button to turn on or
                // off the lighting.
                else{

                    lightToggle();
                    turnOnMelody();

                }

            break;

            // Button pressed twice.
            case 2:

                // Open or close the front depending on it's state.
                openCloseMelody();
                if( frontState == FRONT_OPEN ){

                    closeFront();

                }

                else{

                    openFront();

                }

            break;

        }
        
        // Reset the buttonPressCntr variable for the next round.
        buttonPressCntr = 0;
        
    }

}

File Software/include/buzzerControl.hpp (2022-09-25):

/*
 * Created on May 28 2022
 *
 * Copyright (c) 2022 - Daniel Hajnal
 * hajnal.daniel96@gmail.com
 * This file is part of the Viking Skull Lamp project.
 * Modified 2022.06.27
*/

/*
MIT License
Copyright (c) 2022 Daniel Hajnal
Permission is hereby granted, free of charge, to any person obtaining a copy
of this software and associated documentation files (the "Software"), to deal
in the Software without restriction, including without limitation the rights
to use, copy, modify, merge, publish, distribute, sublicense, and/or sell
copies of the Software, and to permit persons to whom the Software is
furnished to do so, subject to the following conditions:
The above copyright notice and this permission notice shall be included in all
copies or substantial portions of the Software.
THE SOFTWARE IS PROVIDED "AS IS", WITHOUT WARRANTY OF ANY KIND, EXPRESS OR
IMPLIED, INCLUDING BUT NOT LIMITED TO THE WARRANTIES OF MERCHANTABILITY,
FITNESS FOR A PARTICULAR PURPOSE AND NONINFRINGEMENT. IN NO EVENT SHALL THE
AUTHORS OR COPYRIGHT HOLDERS BE LIABLE FOR ANY CLAIM, DAMAGES OR OTHER
LIABILITY, WHETHER IN AN ACTION OF CONTRACT, TORT OR OTHERWISE, ARISING FROM,
OUT OF OR IN CONNECTION WITH THE SOFTWARE OR THE USE OR OTHER DEALINGS IN THE
SOFTWARE.
*/

#ifndef BUZZER_CONTROL_HPP__
#define BUZZER_CONTROL_HPP__

#include "Arduino.h"
#include "menu.hpp"

/// The speaker is connected to pin 9 on the Arduino.
#define SPEAKER_PIN 9

/// Tone frequency for button click event.
#define BUTTON_CLICK_FREQUENCY 1000
/// Tone duration for button click event.
#define BUTTON_CLICK_DURATION 20

/// Tone frequency for encoder rotate event.
#define ENCODER_ROTATE_FREQUENCY 5000
/// Tone duration for encoder rotate event.
#define ENCODER_ROTATE_DURATION 15

/// Tone frequency for turn on event.
#define TURN_ON_SOUND_FREQUENCY 1800
/// Tone duration for turn on event.
#define TURN_ON_SOUND_DURATION 30

// Frequency of notes.
#define NOTE_B0  31
#define NOTE_C1  33
#define NOTE_CS1 35
#define NOTE_D1  37
#define NOTE_DS1 39
#define NOTE_E1  41
#define NOTE_F1  44
#define NOTE_FS1 46
#define NOTE_G1  49
#define NOTE_GS1 52
#define NOTE_A1  55
#define NOTE_AS1 58
#define NOTE_B1  62
#define NOTE_C2  65
#define NOTE_CS2 69
#define NOTE_D2  73
#define NOTE_DS2 78
#define NOTE_E2  82
#define NOTE_F2  87
#define NOTE_FS2 93
#define NOTE_G2  98
#define NOTE_GS2 104
#define NOTE_A2  110
#define NOTE_AS2 117
#define NOTE_B2  123
#define NOTE_C3  131
#define NOTE_CS3 139
#define NOTE_D3  147
#define NOTE_DS3 156
#define NOTE_E3  165
#define NOTE_F3  175
#define NOTE_FS3 185
#define NOTE_G3  196
#define NOTE_GS3 208
#define NOTE_A3  220
#define NOTE_AS3 233
#define NOTE_B3  247
#define NOTE_C4  262
#define NOTE_CS4 277
#define NOTE_D4  294
#define NOTE_DS4 311
#define NOTE_E4  330
#define NOTE_F4  349
#define NOTE_FS4 370
#define NOTE_G4  392
#define NOTE_GS4 415
#define NOTE_A4  440
#define NOTE_AS4 466
#define NOTE_B4  494
#define NOTE_C5  523
#define NOTE_CS5 554
#define NOTE_D5  587
#define NOTE_DS5 622
#define NOTE_E5  659
#define NOTE_F5  698
#define NOTE_FS5 740
#define NOTE_G5  784
#define NOTE_GS5 831
#define NOTE_A5  880
#define NOTE_AS5 932
#define NOTE_B5  988
#define NOTE_C6  1047
#define NOTE_CS6 1109
#define NOTE_D6  1175
#define NOTE_DS6 1245
#define NOTE_E6  1319
#define NOTE_F6  1397
#define NOTE_FS6 1480
#define NOTE_G6  1568
#define NOTE_GS6 1661
#define NOTE_A6  1760
#define NOTE_AS6 1865
#define NOTE_B6  1976
#define NOTE_C7  2093
#define NOTE_CS7 2217
#define NOTE_D7  2349
#define NOTE_DS7 2489
#define NOTE_E7  2637
#define NOTE_F7  2794
#define NOTE_FS7 2960
#define NOTE_G7  3136
#define NOTE_GS7 3322
#define NOTE_A7  3520
#define NOTE_AS7 3729
#define NOTE_B7  3951
#define NOTE_C8  4186
#define NOTE_CS8 4435
#define NOTE_D8  4699
#define NOTE_DS8 4978

/// Generate button click sound
///
/// This function generates the button click sound effect on the buzzer.
/// @see BUTTON_CLICK_FREQUENCY
/// @see BUTTON_CLICK_DURATION
void buttonClickSound();

/// Generate encoder rotate sound
///
/// This function generates the encoder rotate sound effect on the buzzer.
/// @see ENCODER_ROTATE_FREQUENCY
/// @see ENCODER_ROTATE_DURATION
void encoderRotateSound();

/// Generate turn on sound
///
/// This function generates the turn on sound effect on the buzzer.
/// @note Originally it was a melody( this is why the name ), but I
/// @note ran out of memory, so I had to optimize out things.
/// @see TURN_ON_SOUND_FREQUENCY
/// @see TURN_ON_SOUND_DURATION
void turnOnMelody();

/// Generate open-close melody
///
/// This function generates the open-close melody on the buzzer.
void openCloseMelody();

/// Generate clap melody
///
/// This function generates the clap melody on the buzzer.
void clapMelody();

#endif

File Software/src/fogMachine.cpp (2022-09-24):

/*
 * Created on May 28 2022
 *
 * Copyright (c) 2022 - Daniel Hajnal
 * hajnal.daniel96@gmail.com
 * This file is part of the Viking Skull Lamp project.
 * Modified 2022.06.27
*/

/*
MIT License
Copyright (c) 2022 Daniel Hajnal
Permission is hereby granted, free of charge, to any person obtaining a copy
of this software and associated documentation files (the "Software"), to deal
in the Software without restriction, including without limitation the rights
to use, copy, modify, merge, publish, distribute, sublicense, and/or sell
copies of the Software, and to permit persons to whom the Software is
furnished to do so, subject to the following conditions:
The above copyright notice and this permission notice shall be included in all
copies or substantial portions of the Software.
THE SOFTWARE IS PROVIDED "AS IS", WITHOUT WARRANTY OF ANY KIND, EXPRESS OR
IMPLIED, INCLUDING BUT NOT LIMITED TO THE WARRANTIES OF MERCHANTABILITY,
FITNESS FOR A PARTICULAR PURPOSE AND NONINFRINGEMENT. IN NO EVENT SHALL THE
AUTHORS OR COPYRIGHT HOLDERS BE LIABLE FOR ANY CLAIM, DAMAGES OR OTHER
LIABILITY, WHETHER IN AN ACTION OF CONTRACT, TORT OR OTHERWISE, ARISING FROM,
OUT OF OR IN CONNECTION WITH THE SOFTWARE OR THE USE OR OTHER DEALINGS IN THE
SOFTWARE.
*/

#include "fogMachine.hpp"

/// This variable is used for automatic humidification.
/// It stores the last system time when the humidifier
/// was turned on by the automated logic.
unsigned long fogMachineTimer = 0;

/// This variable stores the last system time when the
/// humidifier was turned on by any reason.
unsigned long fogLastTurnOn = 0;

/// This variable stores the last system time when the
/// cool down event happened. From this time whe should
/// not turn on the humidifier for @ref HUMIDIFIER_COOL_DOWN
/// duration.
unsigned long fogCoolDownTimer = 0;

/// If the cool down procedure still in progress, this flag will be true.
bool fogCoolDown = false;

void fogMachineInit(){

    pinMode( HUMIDIFIER_PIN, OUTPUT );
    digitalWrite( HUMIDIFIER_PIN, 0 );

}

void fogMachineUpdate(){

    // Calculate one minute in ms.
    unsigned long timerCalculated = (unsigned long)1000 * 60; // one minute

    // Check if the maximum allowed on time has expired.
    if( ( ( (unsigned long)millis() - fogLastTurnOn ) > HUMIDIFIER_DURATION ) ){

        // If the humidifier is turned of we have to turn if off.
        if( digitalRead( HUMIDIFIER_PIN ) ){

            digitalWrite( HUMIDIFIER_PIN, 0 );
            Serial.print( millis() );
            Serial.print( F( " : " ) );
            Serial.println( F( "Humidifier finished! Cool-down timer start..." ) );

            // Start the cool down procedure by setting
            // the flag and saving the system time.
            fogCoolDown = true;
            fogCoolDownTimer = millis();

        }

    }

    // Check if the cool down period expired.
    if( fogCoolDown && ( ( (unsigned long)millis() - fogCoolDownTimer ) > HUMIDIFIER_COOL_DOWN ) ){

        Serial.print( millis() );
        Serial.print( F( " : " ) );
        Serial.println( F( "Cooling finished!" ) );

        // If the cool down procedure finished,
        // clear the flag.
        fogCoolDown = false;

    }

    // In this section we just calculate the automatic humidification
    // periods based on the fogTimer variable.
    switch( fogTimer ){

        case 0:
            timerCalculated = (unsigned long)15 * timerCalculated;
        break;

        case 1:
            timerCalculated = (unsigned long)30 * timerCalculated;
        break;

        case 2:
            timerCalculated = (unsigned long)45 * timerCalculated;
        break;

        case 3:
            timerCalculated = (unsigned long)60 * timerCalculated;
        break;

        case 4:
            timerCalculated = (unsigned long)90 * timerCalculated;
        break;

        case 5:
            timerCalculated = (unsigned long)120 * timerCalculated;
        break;

        case 6:
            timerCalculated = (unsigned long)180 * timerCalculated;
        break;

        case 7:
            timerCalculated = (unsigned long)300 * timerCalculated;
        break;

        case 8:
            timerCalculated = (unsigned long)480 * timerCalculated;
        break;

        case 9:
            timerCalculated = (unsigned long)720 * timerCalculated;
        break;

        case 10:
            timerCalculated = (unsigned long)1440 * timerCalculated;
        break;

        default:

            return;

        break;

    }

    // Check if the automatic humidification has to be turned on.
    if( ( (unsigned long)millis() - fogMachineTimer ) > timerCalculated ){

        // Save the system time for the logic.
        fogMachineTimer = millis();
        
        // Try to enable the humidifier.
        fogMachineEnable();
        Serial.print( millis() );
        Serial.print( F( " : " ) );
        Serial.println( F( "Timer elapsed, humidifier turning on..." ) );

    }

}

void fogMachineEnable(){

    // If the humidifier is disabled we are not allowed to turn it on.
    if( !fogMachineEnabled ){

        return;

    }

    // If the humidifier pin is off and the cool down procedure
    // expired, we are allowed to turn on the humidifier.
    if( !digitalRead( HUMIDIFIER_PIN ) && !fogCoolDown ){

        // Save the system time for the logic.
        fogLastTurnOn = millis();
        digitalWrite( HUMIDIFIER_PIN, 1 );

    }

}

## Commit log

2022-09-02 Documentation
    * Updated Style
    * Footer image
    * Graphs
    [TechnoVikingPCB.kicad_pcb, TechnoVikingPCB.kicad_sch, box_front_naked_1pcs.stl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]
2022-09-22 Assembly steps are finished.
    [TechnoVikingPCB.kicad_pcb, TechnoVikingPCB.kicad_sch]
2022-09-24 Documentation
    * Print Guide
    [azomizer_socket_1pcs_PETG.3mf, box_front_with_art_1pcs.3mf, display_clamp_2pcs.3mf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]
2022-09-24 Source code documentation.
    [box_front_naked_1pcs.stl, display_holder_naked_1pcs.stl, encoder_knob_naked_1pcs.stl]
2022-09-25 Source Documentation
    * motorControl
2022-09-26 Documentation
    * Issue templates
    * BOM
2022-10-14 Prusa Mini Gcodes
    [moving_platform_1pcs.3mf]
2023-10-20 MPN Fields are added to interactive BOM
    [TechnoVikingPCB.kicad_pcb, TechnoVikingPCB.kicad_sch]
